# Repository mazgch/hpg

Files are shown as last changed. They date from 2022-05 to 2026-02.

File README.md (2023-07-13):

#  mazg.ch - HPG Solution

>**Note** This is a private project from [@mazgch](https://github.com/mazgch) <br> This code and hardware was developped during my free time. [u-blox](https://www.u-blox.com) decided to launch a simliar, inspired product under the name [XPLR-HPG-2](https://www.u-blox.com/en/product/xplr-hpg-2) along with production grade software based on [ubxlib](https://github.com/u-blox/ubxlib). u-blox has published the [hardware](https://github.com/u-blox/XPLR-HPG-hardware) and [software](https://github.com/u-blox/XPLR-HPG-software) on the [u-blox github account](https://github.com/u-blox). You can easily recognize the u-blox productized version by its green PCB color and u-blox sticker and silk logo on the back of the PCB.<br>
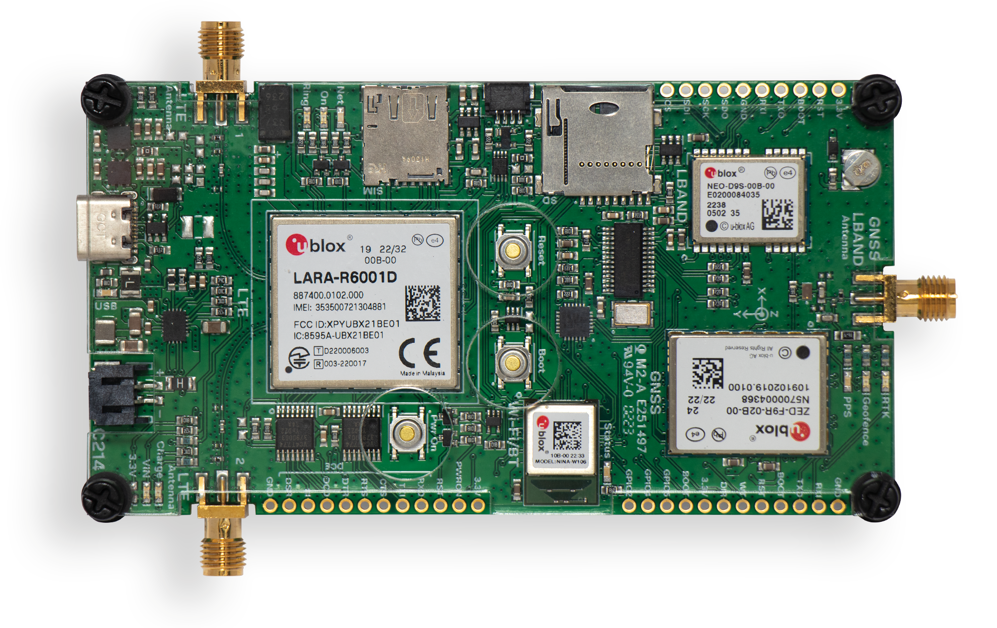
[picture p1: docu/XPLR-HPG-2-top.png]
[](https://www.u-blox.com/en/product/xplr-hpg-2)<br>
The Arduino software of this project can be compiled for the XPLR-HPG-2/1 by adjusting the `HW_TARGET` defines to `UBLOX_XPLR_HPG2_C214` in the [`software\HW.h`](./software/HW.h) file and selecting the right module/board. 

Board with accessories

This project has the goal to demonstrate a high precision positioning function. It uses a Global Navigation Satellite System (GNSS) L1/L2 receiver with Real Time Kinematic (RTK) and Inertial Measurement Unit (IMU) Sensor based Dead Reckoning (DR) function to determine its location. In order achieve its best accuracy the receiver needs a correction data stream. On this solution the correction data can be received from a satellite broadcast using a LBAND receiver or over IP connectivity using Wi-FI or LTE. While other systems typically use local reference stations as correction source that have to be setup a maintained, this system makes use of a continental wide commercial SSR service. The whole solution shared in this project consist of three parts: 

## The three elements of the HPG Solution 

| [**HPG Hardware**](./hardware) | [**HPG Software**](./software) | [**HPG Monitor Webpage**](./monitor) |
|---|---|---|
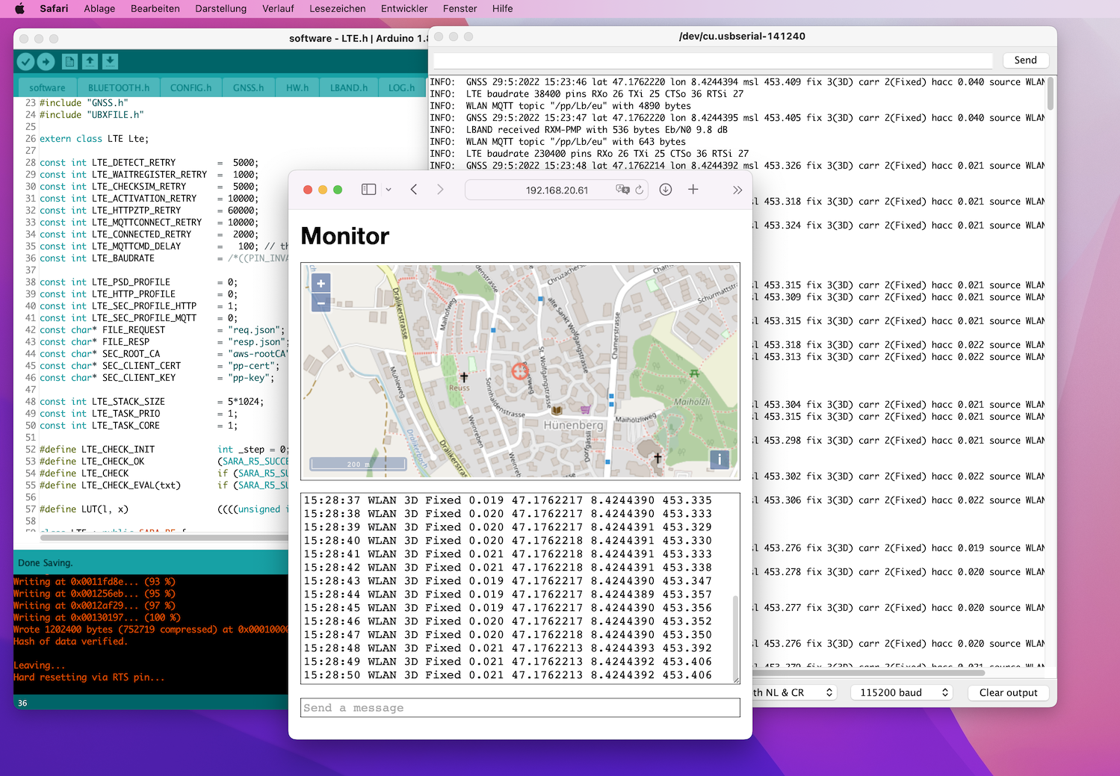
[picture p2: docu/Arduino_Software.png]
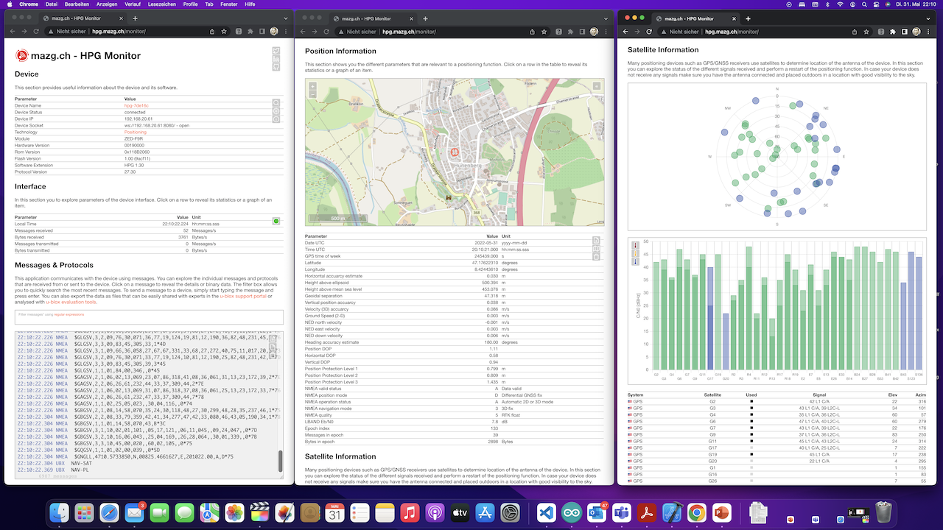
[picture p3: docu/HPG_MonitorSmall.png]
|  |  |  |
| The HPG hardware has a GNSS and a LBAND receiver that are used to achieve cm-Level precision. A Wi-Fi/BT module and a LTE modem make sure that the board is always connected to the internet. A USB port is used for changing or connecting a powerful host. The CPU of the Wi-Fi/BT module can be programmed with the HPG Software. | The HPG software implements a captive portal for configuration and monitoring. The software operates autonomously, configures all the modules and handles the different correction data sources and provides its data to the RTK system. It can also record two logfiles to the SD card of the GNSS/LBAND and the LTE communication. | The online HPG Monitor webpage at [hpg.mazg.ch](http://hpg.mazg.ch) is a online tools that allows you visualize the data of the solution. You can plot graph, export data to Excel or other offline tools. Satellite information as well as a map overlay are even available. The different messages and commands can be analyzed in a console. A simpler version can be accessed in the captive portal directly. |  

## Getting started

To make this device work as intended you need some accessories like LTE and GNSS antennas, a mobile data plan and nano SIM card and a subscription to PointPerfect. Follow this sequence to get the device configured and setup, click on the image below for a short YouTube video on how to do some of these steps.

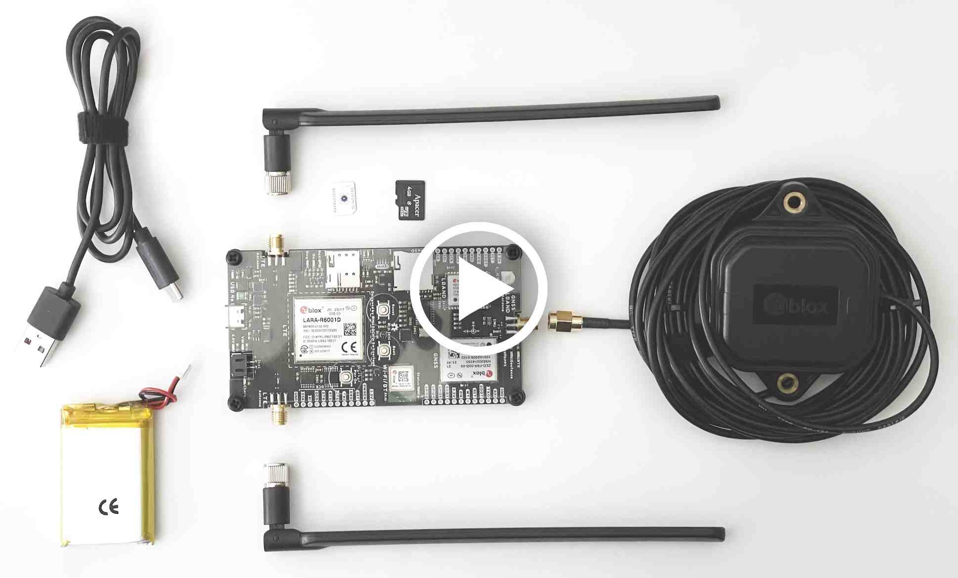
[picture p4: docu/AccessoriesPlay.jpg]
Accessories Video (https://youtu.be/jzHmvw_pzyI)


1. Insert a nano SIM card, the socket is a push/push socket so don't try to just pull the card out.
2. Optional: Insert a micro-SD card (FAT, max 32GB) if you like the device to record logfiles. 
3. Attach the two LTE antennas to the SMA ports located on the long edges. To avoid mechanical stress on the center pin, make sure you do not rotate the antenna itself but only the nut of the SMA connector. 
4. Connect a survey grade L1/L2/L5 GNSS and LBAND antenna to the SMA port on the small edge of the device and place the antenna in a location with very good and unobstructed visibility to the sky. This is important to allow reliable LBAND reception as well as avoid multipath errors on the GNSS measurements 
5. Connect a USB cable to a computer, this will turn the device on, and you will see various LEDS turn on. In addition, your computer will enumerate several USB devices and serial as well a modem ports will become available.  

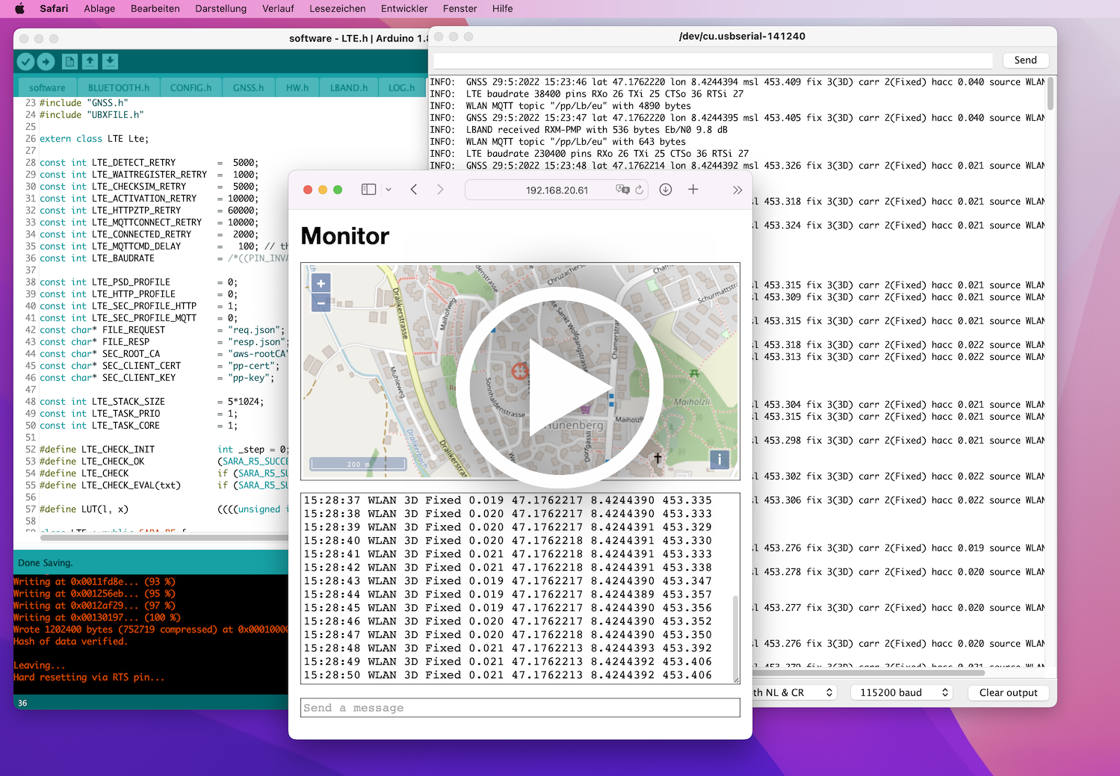
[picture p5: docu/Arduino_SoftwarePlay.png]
Software Getting Started Video (https://youtu.be/k2dovptFn9o)


6. Optional: if the [software](./software) is not yet programmed, follow the build instructions of the Arduino based software and load it to the device. 
7. In order to add the device to your local Wi-Fi connect your computer or mobile phone with the `hpg-XXXXXX` Wi-Fi network. You will be directed to a captive portal where you can then enter your networks Wi-Fi credentials. Make sure that the Wi-Fi network that you like to connect to is supporting 2.4GHz band. Once done the device will connect to your local network and get an IP. You may want to reset your device to force a fast reconnection.
8. After the device is connected, you can try to connect to it using its host name `hpg-XXXXXX`. The IP address of the device is also reported in the debug output on the console output CDC port at 115'200 baud. A third option is to use the device discovery of the [HPG Monitor](http://hpg.mazg.ch). Some networks do not allow communication between attached Wi-Fi clients so it may be better to connect the device to your computer or mobile in hotspot mode. 
9. After you have successfully connected your device, you need to configure the PointPerfect location device token that you can get from the Thingstream portal and set the possible correction sources to use. If you do not have a device profile, create one with following settings: ``Status = enabled, Auto Activate Devices = true, Hardware Code = mandatory`` Return existing device details if Hardware Code is in use. You can also set the SIM pin, but it is often easier to remove the SIM pin from your SIM card with a mobile phone first. Alternatively you can provide the ``u-centerConfig.json`` to the device.  
10. After that the device will provision the credentials using zero touch provisioning (ZTP) from the PointPerfect servers.
11. Now you are ready to Monitor the operation of the device using the console output on the CDC, using the Monitor webpage that is served directly by the device.

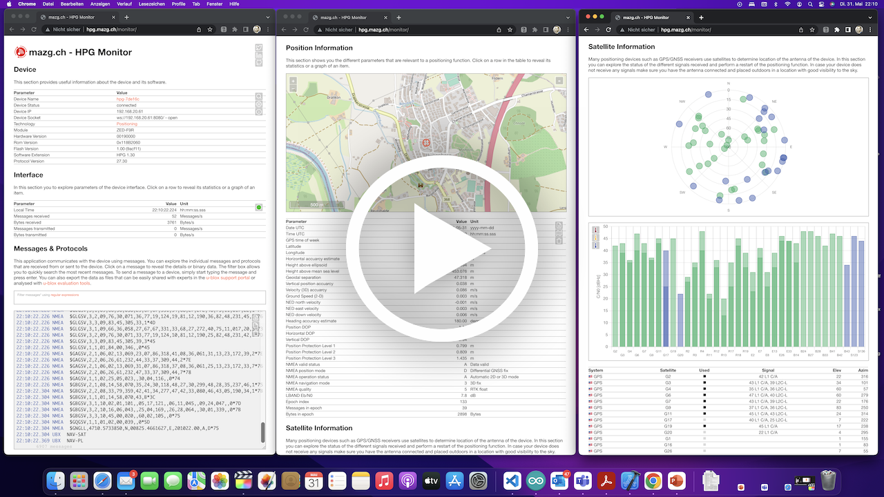
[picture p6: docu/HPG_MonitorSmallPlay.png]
HPG Monitor Getting Started Video (https://youtu.be/LLKUxa8krcs)

  
11. You can also access and find your hpg devices using the HPG Monitor webpage at [hpg.mazg.ch](http://hpa.mazg.ch) This webpage displays various status information, messages and can even plot graphs of parameter or satellite signal strenghs. A map overlay completes the functionality of the HPG Monitor. You can even export your data a text, in common file formats for offline tools.
12. You are now ready to start experimenting with this exciting technology and go outside and test RTK positioning in your use cases. The solution is suitable for a variety of applications from Lawn Mower, Heavy machine and Construction vehicles, Drones, Precision Agriculture, Cars and of course Mobile Robotics. 
13. To get best performance sure that the GNSS/LBAND antenna is well positioned and has good visibility to the sky!
14. So have fun and put this solution on your robot, [vehicle](docu/Vehicle.md), [scooter](docu/Scooter.md) or [lawn mower](docu/Mower.md) project. Feel free to connect with me even if it’s just to share the projects you are building using this exciting technology and solution.

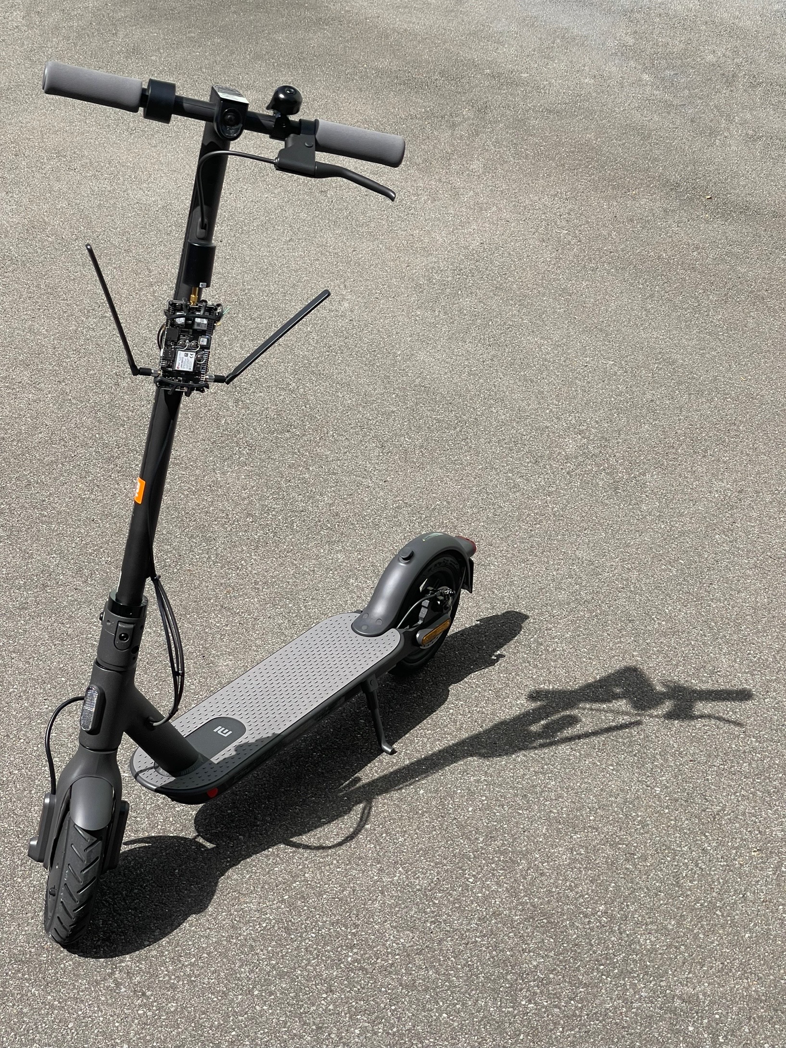
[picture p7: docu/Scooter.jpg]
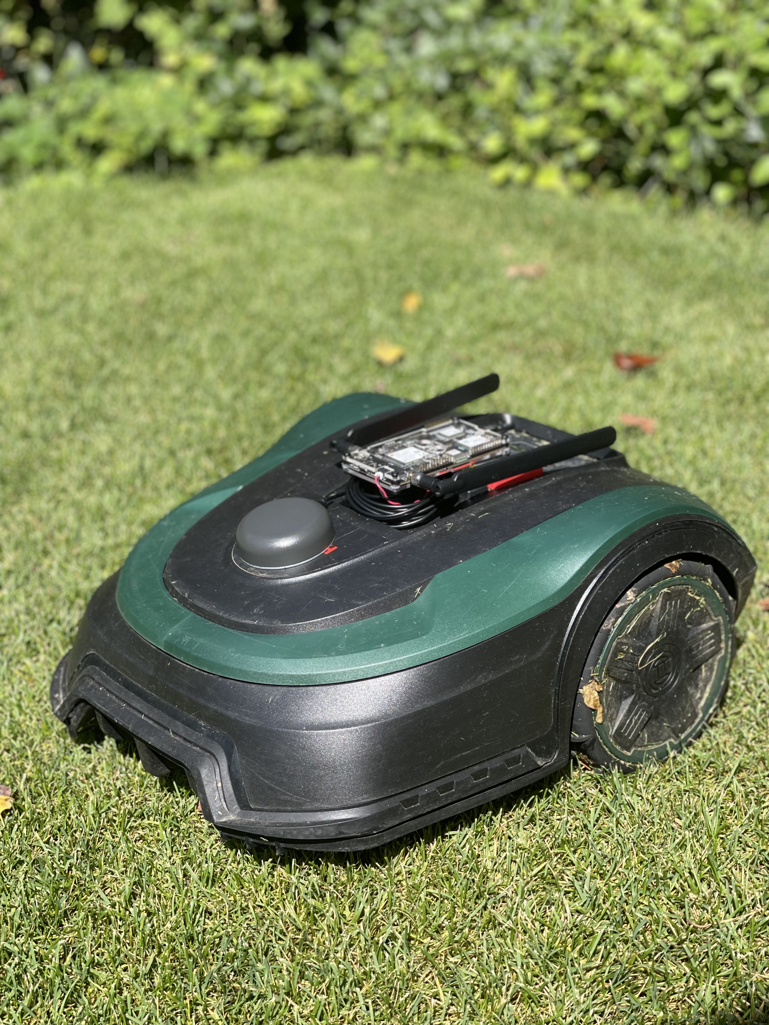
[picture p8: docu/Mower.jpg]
  

## Quick Reference Card

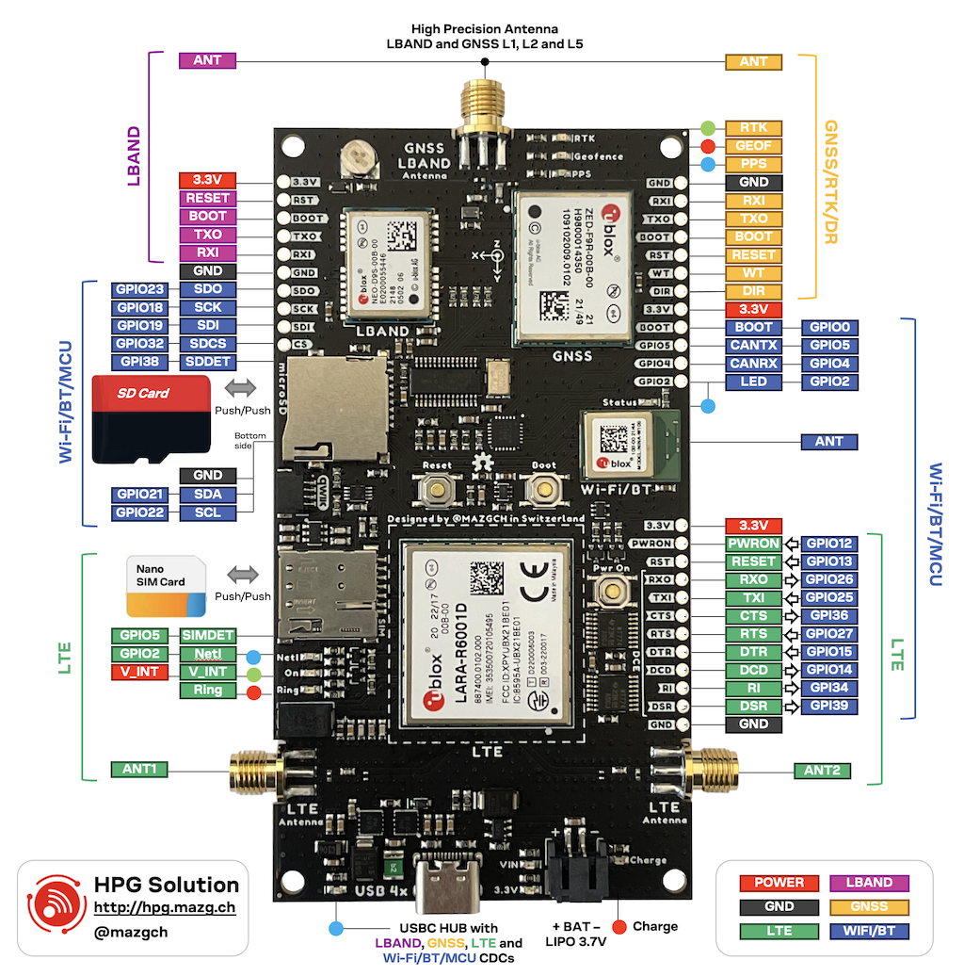
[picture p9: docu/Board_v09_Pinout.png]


## An all [u-blox](https://www.u-blox.com) solution

This solution is an attempt to design a 'full u-blox solution' using various products In particular the solution implements following hardware and services:

| u-blox Product / Service | Description |
|:---:|---|
| [NINA-W106](https://www.u-blox.com/en/product/nina-w10-series-open-cpu) | An ESP32 based WIFI and BT module with Open CPU that will host the application. | 
| [LARA-R6001D](https://www.u-blox.com/en/product/lara-r6-series) | A LTE Cat 1 cellular modem with 2G / 3G fallback. |
| [ZED-F9R](https://www.u-blox.com/en/product/zed-f9r-module) | A GNSS Module with RTK, DR and L1/L2 multiband capability. |
| [NEO-D9S](https://www.u-blox.com/en/product/neo-d9s-series) | A LBAND receiver to get PointPerfect correction service. | 
| [ANN-MB](https://www.u-blox.com/en/product/ann-mb-series) | L1/L2 multi-band, high precision GNSS antenna (LBAND is not offically supported, it may work but there is a slight degradation depending on the frequency) | 
| [PointPerfect](https://www.u-blox.com/en/product/pointperfect) | A continental wide SSR correction service with coverage in Europe and North America. |
| [AssistNow](https://www.u-blox.com/en/product/assistnow) | A assisted GNSS services that allows to speed up the system start. |

The hardware allows different SKUs and can be assembled with alternative modules with compatible form-factors such as [SARA-R510S](https://www.u-blox.com/en/product/sara-r5-series), [LENA-R8001](https://www.u-blox.com/en/product/lena-r8-series), [ZED-F9P](https://www.u-blox.com/en/product/zed-f9p-module) or [NEO-D9C](https://www.u-blox.com/en/product/neo-d9c-series).

## Availability

As this is a private project, availability of real prototypes and hardware is pretty much limited to friends and colleagues. I am sharing here my work with the open source community with the goal that others can learn from it and collaborate. If you like to have a discussion or business interesst you can contact me with a DM.

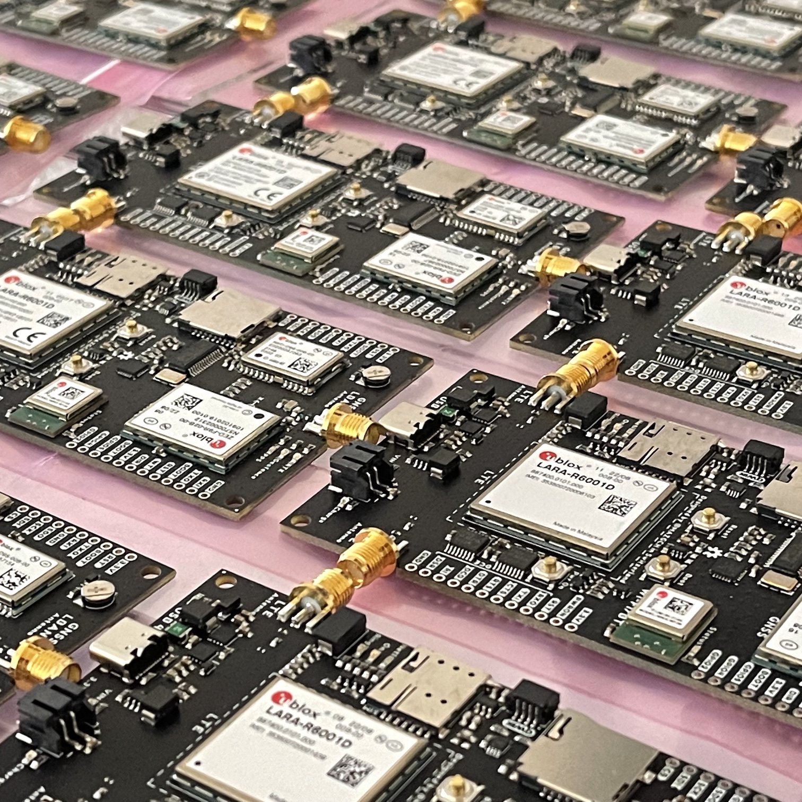
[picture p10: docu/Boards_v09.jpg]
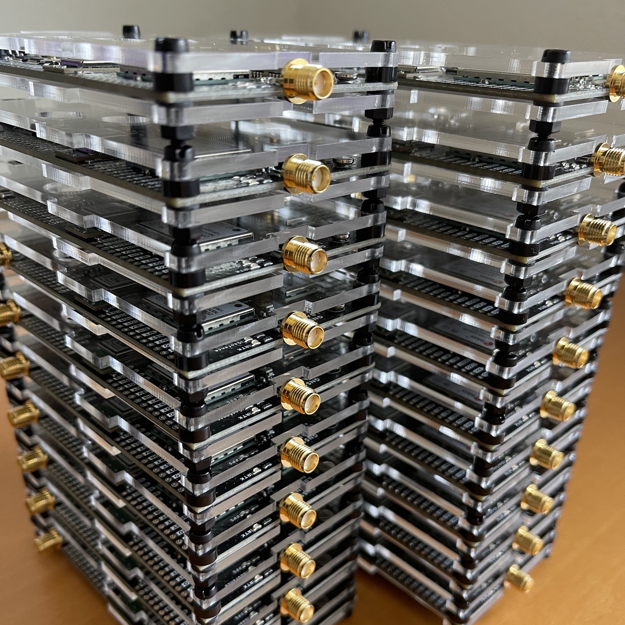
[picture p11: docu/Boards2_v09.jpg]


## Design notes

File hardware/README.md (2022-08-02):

# Hardware



This hardware was designed with Autodesk Eagle and is hugely based on Sparkfun open-source designs. The PCB is a standard four-layer PCB 1.6mm with quite conservative design rules and components, passives are mostly 0603. The core of the circuit is centered around various u-blox modules. The design's default assembly option are the following modules.

| u-blox Module | Function |
|:---|:---|
| [NINA-W106](https://www.u-blox.com/en/product/nina-w10-series-open-cpu) | An ESP32 based WIFI and BT module with Open CPU that will host the application. | 
| [LARA-R6001D](https://www.u-blox.com/en/product/lara-r6-series) | A LTE Cat 1 cellular modem with 2G / 3G fallback. |
| [ZED-F9R](https://www.u-blox.com/en/product/zed-f9r-module) | A GNSS Module with RTK, DR and L1/L2 multiband capability. |
| [NEO-D9S](https://www.u-blox.com/en/product/neo-d9s-series) | A LBAND receiver to get PointPerfect correction service. | 

## Design Resources 

Here you can find the schematic, layout and pictures of both sides of the PCB.
- [**PCB Schematic**](./HPG_Solution_sch.pdf)
- [**PCB Layout**](./HPG_Solution_brd.pdf)
- [**Autodesk Eagle Files**](./hardware/Eagle/)
- [**Gerber Files and Assembly Data**](./hardware/CAMOutputs)

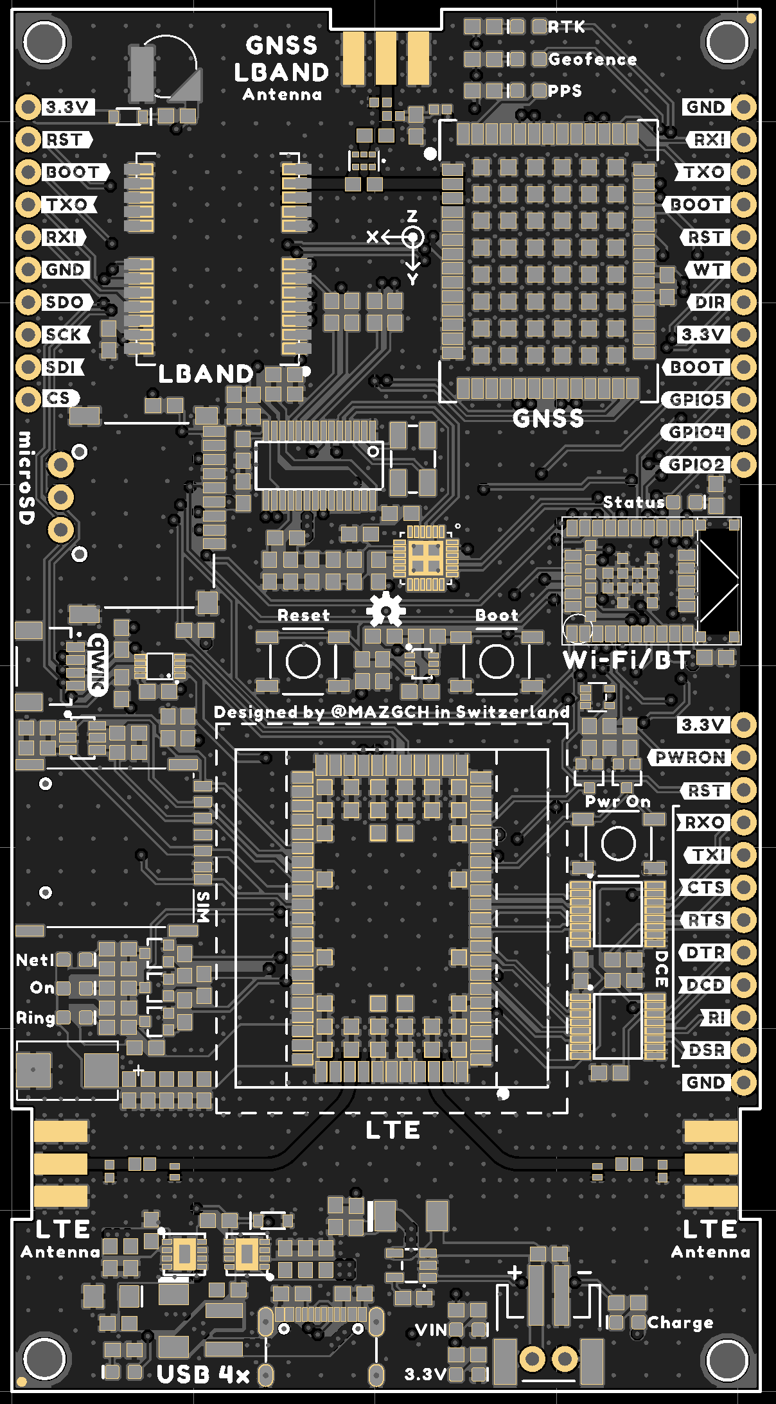
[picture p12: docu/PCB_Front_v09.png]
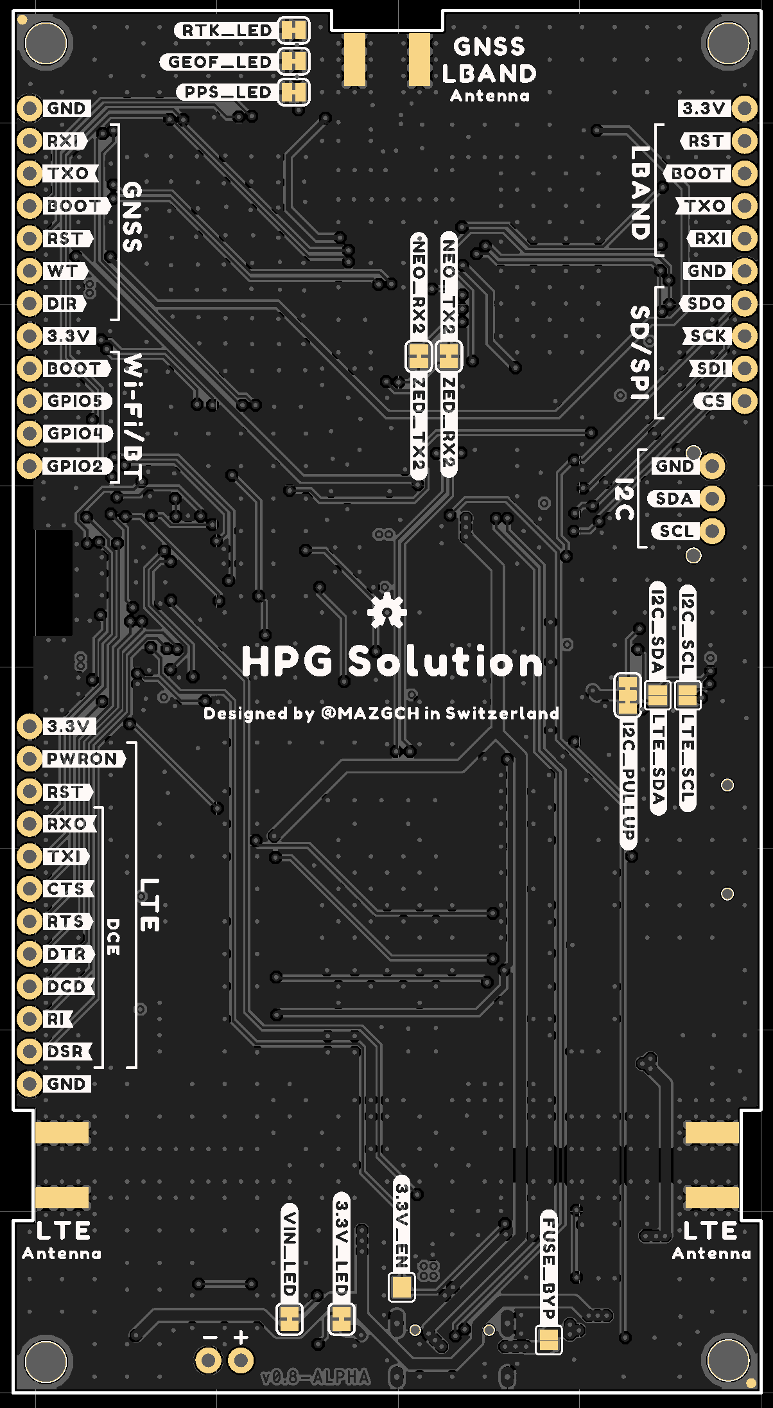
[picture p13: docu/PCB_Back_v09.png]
&nbsp;

## LTE Modem 
There board was designed for u-blox [LARA-R6001D](https://www.u-blox.com/en/product/lara-r6-series) LTE modem, but it allows SKUs by swapping the cellular module to a  [SARA-R510](https://www.u-blox.com/en/product/sara-r5-series) for LTE Cat M1 NB-IoT or a [LENA-R8001](https://www.u-blox.com/en/product/lena-R8-series) Cat 1 bis. Several different modem variants are available from u-blox, only some BOM adjustments might be needed to make different SKUs of this function board. The board requires two external LTE antennas with SMA connectors (only one antenna would be used for [LENA-R8001](https://www.u-blox.com/en/product/lena-R8-series), [SARA-R510](https://www.u-blox.com/en/product/sara-r5-series). The LTE modem uses DCE notation and signal are connected straight to the NINA CPU (no null modem, crossover). The LTE_PWR_ON pin is also connected to a button to allow manual turning on of the LTE modem. The LTE_RESET pin unfortunately does not have a pull up resistor, this could be considered as a mistake, but it can be set by the NINA CPU after software is loaded. If this is not done, then the module will turn off after it booted  

| u-blox Series | LTE Standard | # Antenna |
|:---|:---|:---:|
| [LARA-R6](https://www.u-blox.com/en/product/lara-r6-series) | LTE Cat 1 with 2G / 3G fallback | 2 |
| [LENA-R8](https://www.u-blox.com/en/product/lena-R8-series) | LTE Cat 1bis with 2G / 3G fallback | 1 |
| [SARA-R5](https://www.u-blox.com/en/product/sara-r5-series) | LTE Cat M1 / NB-IoT | 1 |
| [SARA-R4](https://www.u-blox.com/en/product/sara-r4-series) | LTE Cat M1 / NB-IoT with 2G fallback | 1 |

## High Precision GNSS and LBAND Receivers
The board was designed for u-blox **ZED-F9R** high precision GNSS RTK and DR module and a **NEO-D9S**, but it allows SKUs by swapping the modules to different variants such a **ZED-F9P** or the **NEO-D9C** that supports Japan's CLAS system. The board requires an external L1/L2/L5 and LBAND antenna with SMA connectors.

## Wi-Fi/BT with open CPU capability. 

NINA-W106-01 is a ESP32 with 8MB of FLASH memory. This module is responsible to run the software of the whole design. It can be easily programmed using different environments. The RESET and BOOT pins can be controlled with buttons and as well though a special Auto Reset circuit.

### NINA-W106 Pin Assignments

| GPIO  | Signal Function | DIR | Comment |
|:-----:|:---|:---:|:---|
| 0 | BOOT / GPIO0 | IN  | <- BOOT button, USB CDC RTS/CTS |
| 1 | CDC_TX | OUT | -> USB CDC RX |
| 2 | LED / GPIO2 | OUT | -> LED |
| 3 | CDC_RX | IN  | -> USB CDC TX |
| 4 | GPIO4 / CAN_RX | I/O | <- CAN (external) |
| 5 | GPIO5 / CAN_TX | I/O | -> CAN (external) |
|  12 | LTE_PWR_ON | OUT | active HIGH, **no pull up!** |
|  13 | LTE_RESET | OUT | active LOW, ext pulled LOW |
|  14 | LTE_DCD | OUT | -> LTE. |
|  15 | LTE_DTR | OUT | -> LTE |
|  18 | MICROSD_SCK / SCK | OUT | -> SD card |
|  19 | MICROSD_SDI / COPI / MOSI | OUT | -> SD card |
|  23 | MICROSD_SDO / CIPO / MISO | IN  | <- SD card |
|  21 | I2C_SDA | I/O | <-> GNSS, LBAND, LTE, QWIC |
|  22 | I2C_SCL | OUT | -> GNSS, LBAND, LTE, QWIC |
|  25 | LTE_TXI | OUT | -> LTE |
|  26 | LTE_RXO | IN  | -> LTE |
|  27 | LTE_RTS | OUT | -> LTE |
|  32 | MICROSD_CS | OUT | -> SD |
|  33 | VCC_EN | OUT | -> power supply |
|  34 | LTE_RI | IN  | <- LTE |
|  35 | VIN/3 | IN  | <- power supply |
|  36 | LTE_CTS | IN  | <- LTE |
|  37 | LTE_ON | IN  | <- LTE |
|  38 | MICROSD_DET | IN  | <- SD card holder |
|  39 | LTE_DSR | IN  | <- LTE |
| RESET | RESET | IN  | <- RESET button, USB CTS RTS/CTS |

## Power Supply
The board has two 1A LDOs, one for the LTE modem and a second for all other functions. The status of the Power supply can be monitored using the different LEDs across the board. A changer is provided to support charging of a single 3.7V LIPO cell. A special LED will indicate the charging status. The **3.3V pins on the pin headers are output only** and can be used to power an external sensor or device like a CAN transceiver. 

## Other Functions

- **USB** The USB-C port provides as interface to an external host and is used for supplying the board. 
- **CAN** The GPIO4 and GPIO5 of the NINA-W106 can be used to connect a CAN transceiver such as a SN65HVD230. Thre a simple breakout board that you can attach using jumper wires such as the [CJMCU-230](https://de.aliexpress.com/item/32278648363.html)
- **BAT** A 3.7V single LIPO cell can be connected and will be charged when USB is connected. 
- **QWIK** The QWIK connector can be used to connect other I2C devices such as sensors or a display. 

## External Accessories

External antennas have to be connected to operate the device. The combined GNSS and LBAND antenna should support at least L1, L2 and LBAND frequency bands and it can support L5 band in addition. The antenna should be an antennna that is high precision capable, typically these are Helix type of antennas or active patch antennas with dual feed and reasonably sized GND planes (>10cm). If the antenna does not come with a ground plane, place it on a metal surface such as a car roof.
The LTE modem needs to 4G capable antennas and cover the band of the modem usually this is 700kHz - 2.6GHz. In addition you need to insert a SIM card with a data plan from your local mobile network operator.
A micro-SD card is only required if you intend to record logfiles from the modem of GNSS_ 

### Accessory parts and suppliers:
- Plexi were ordered from [Alibaba Shenzhen Elemei Display Products Co., Ltd](https://elemeidisplay.en.alibaba.com/minisiteentrance.html) they offer laser cut custom plexi under part number [OEM and ODM custom laser cut acrylic shapes customized service](https://www.alibaba.com/product-detail/OEM-and-ODM-custom-laser-cut_1600273363981.html) you send them the two PlexiTop and PlexBot layers exported as DXF file.  
- LTE antennas were ordered from [Advanced Aerial Store](https://de.aliexpress.com/store/912726145), you need 2pcs (= one order) of the following product for each board [2pcs/lot 4G Antenna 10dBi SMA Male 700-2700MHz for 4G LTE Router External Antenna](https://de.aliexpress.com/item/1005003688735673.html)
- The screws an nuts were ordered from [LANHAI Fastener Store](https://de.aliexpress.com/store/912262969), for a single board 4pcs are needed from each part. 
  - [M3x15mm / Phillips head screw](https://de.aliexpress.com/item/1005003106000201.html)
  - [hex nut M3](https://de.aliexpress.com/item/1005003106000201.html)
  - [Black / M3 ID3.1mm OD7mm / 3mm](https://de.aliexpress.com/item/1005003106036023.html)
  - [M3x6x1mm / black](https://de.aliexpress.com/item/1005003106227200.html)

## Known Issue of version 0.9: 
- The LTE_PWR_ON is floating towards GND, this causes the modem to constantly reset if no software is loaded. Software needs to be loaded that configures the GPIO12 either output HIGH or as INPUT with PULL-UP enabled. During reset the ESP applies however some LOW and high signal. It would be best to swap the LTE_RESET and LTE_PWRON pins to avoid changes during updates or reset. 
- The C41 was added to the Auto Reset circuit of the NINA-W106. This sometimes can cause issues with certain terminal applications or if the BOOT GPIO is used for other functions. Simply remove the C41 with a soldering iron if it causes issues for you.
- The shield of the SIM card holder is not connected to GND in the symbol. To make SIM detection work, we have to connect it to GND by makeing a solder bridge to GND pads of C38/36. In addition the software needs to set AT+UGPIOC=42,7 and AT+UDCONF=50,1. If SIM detection is not needed and then it is better to maybe remove R50. 
- On the v0.9 build some of the SIMhard holders are not porperly positioned on the board. This results in the component being a bit tilted due to the guidance pins. The parts were not repositioned but simply fixed with just more solder. 
- If special firmware is loaded to ZED-F9 (e.g., dev builds), make sure that RTK_STAT assigned to GPIO11 and GEOFENCE to GPIO12 to use that function.
- Higher baud rates on the LTE are not recommended even if RTS / CTS is used, this is a software issue and unrelated to hardware.
- LENA-R8: prototype require VCC of the module to be higher than 3.5V, this can be fixed by changing the dedicated LTE LDO to a adjustable version with a resistor divider at 3.8V. Also Pin 33 USB_BOOT of LENA should be routed to a jumper that can connect to VINT (V1.8) to allo firmware update over USB.
- Pins could be reassigned, to allow use of JTAG as alternative to the full 8 wire UART (second level shifter would need to be disabled.

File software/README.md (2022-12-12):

# Software



The software ensures full autonomous operation of a high precision solution using cellular or Wi-Fi network for internet connectivity. u-center compatible logging of GNSS data can be stored on SD card. In parallel full evaluation capability should be feasible by giving direct access to the modules through USB to all modules, this interface is also used to update software and firmware of the modules. The application that will runs on the NINA-W106 is be open sourced and serve as an example that can be tailored to different use cases. Ideally the board can be shipped with a software that can be configured using captive portal 

## Features
- Captive and Web portal for configuration of the system and setting Wi-Fi credentials
- Reporting of status on the console using CDC on USB 
- Storing of GNSS UBX and AT commands file to SD card
- Provisioning of PointPerfect credentials using zero touch provisioning (ZTP) by providing device profile token
- Reception of Pointperfect correction data using the MQTT protocol over WIFI an LTE
- Reception of NTRIP corrections using WIFI or LTE (when PointPerfect Correction source set to a `NTRIP:` option)
- Management of different regional correction stream to only ensure one active connection per device. 
- configuration of LBAND frequency and communication settings depending on location and PointPerfect subscription plan. 
- Configuration of the GNSS correction source depending on incoming LBAND or IP data
- Hot plug and runtime detection of gnss, lband and SD card
- Visualisation of the data on a webpage [hpg.mazg.ch](http://hpg.mazg.ch) using websockets 
- Bluetooth connection from a mobile phone using a suitable app (e.g SW Maps on [iOS](https://apps.apple.com/ch/app/sw-maps/id6444248083) or [Android](https://play.google.com/store/apps/details?id=np.com.softwel.swmaps) ). 

## Captive portal
A captive portal is available for configurating the device. Select the Wi-Fi network `hpg-XXXXXX` with a notebook or mobile phone. You can then enter the Wi-Fi network to connect to, configure the Point Perfect device token, stream preferences as well as the LTE related settings. 
The captive protal also will show the client ID when provisioned. 

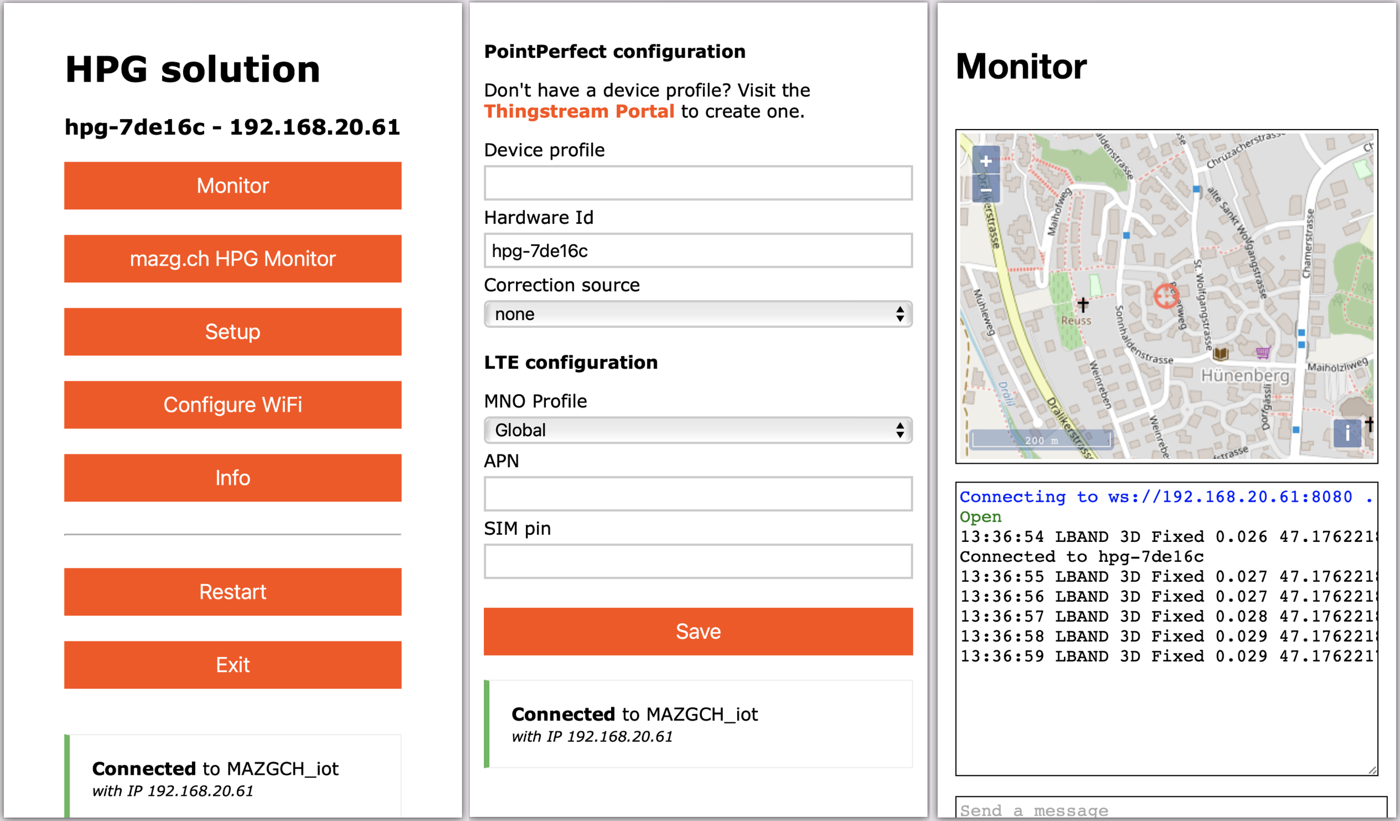
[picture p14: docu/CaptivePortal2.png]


## Host drivers & tools
The USB port exposes each module as serial ports, the LARA is also recognized as a modem. These ports are available for a prowerful host or to connect the various u-blox evaluation tools or a terminal program: 

- [m-Center Cellular Evaluation Tool](https://www.u-blox.com/en/product/m-center)
- [u-center GNSS Evaluation Tool](https://www.u-blox.com/en/product/u-center)

The solution might require installation of drivers these are either available from Microsoft Update or from the u-blox and third party websites.

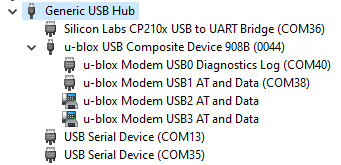
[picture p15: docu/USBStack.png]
Drivers


- [LARA-R6 Drivers](https://content.u-blox.com/sites/default/files/2022-04/ublox_LARA-R6xx_%20windows_3264_v1.0.0.0.exe.zip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)
- [SiLabs CP2101N Drivers](https://www.silabs.com/developers/usb-to-uart-bridge-vcp-drivers)
- ZED-F9 and NEO-D9 works with the standard Windows drivers. [This application note explain details](https://www.u-blox.com/sites/default/files/WindowsDrivers_AppNote_%28UBX-19005821%29.pdf)
- USB Hub works with the standard Windows drivers.

## CDC interface: 
The solution provides a debug console on a CDC USB port. This interface can be used to update this application firmware after compiling it in the Arduino environment. After normal startup it will provide visibility of the activity of the solution. Messages are tagged depending on their severity and software block. (the debug output on the CDC port was recently restructed to use the ESP log APIs an now looks different)

```
INFO:  -------------------------------------------------------------------
INFO:  u-blox HPG solution
INFO:  MAIN task on core 1
INFO:  CONFIG::init FFS ok
INFO:  CONFIG::init "FFS/config.ffs" read
INFO:  UBXSD task on core 1
INFO:  UBXSD card state changed 1 (removed)
INFO:  LBAND detect receiver detected
INFO:  LBAND detect configuration complete, receiver online
INFO:  GNSS detect receiver detected
INFO:  GNSS detect injecting saved key 60 bytes
INFO:  GNSS detect configuration complete, receiver online
INFO:  LED task on core 1
INFO:  WLAN task on core 0
INFO:  LTE task on core 1
INFO:  WLAN init autoconnect using wifi/hostname "u-blox-hpg-7d6de378"
INFO:  LBAND received RXM-PMP EB/N0 37 with 528 bytes
INFO:  GNSS spartanUseSource 1-PMP from source LBAND
INFO:  LBAND received RXM-PMP EB/N0 37 with 528 bytes
INFO:  GNSS 30:4:2022 19:21:08 lat 47.1762495 lon 8.4243838 msl 453.130 fix 3(3D) carr 2(Fixed) hacc 0.025 heap 121188
INFO:  WIFI state change 1(searching)
INFO:  WLAN poll got connection
INFO:  WLAN poll connected with hostname "u-blox-hpg-7d6de378" at IP 192.168.20.57 RSSI -51 dBm
INFO:  WLAN poll visit portal at "http://192.168.20.57/"
INFO:  WLAN bindCallback webserver started
INFO:  WIFI state change 3(provisioned)
INFO:  GNSS 30:4:2022 19:21:09 lat 47.1762495 lon 8.4243838 msl 453.139 fix 3(3D) carr 2(Fixed) hacc 0.026 heap 61696
INFO:  LTE config manufacturer "u-blox" model="LARA-R6401D" version="00.11"
INFO:  LTE state change 1(check sim)
INFO:  LTE SIM card status "READY" CCID="89410112191214532555"
INFO:  LBAND received RXM-PMP EB/N0 35 with 528 bytes
INFO:  LTE IMEI="359352450003076" IMSI="228012122453255" subscriber=""+41799613242"
INFO:  LTE state change 2(sim ready)
INFO:  LTE state change 3(wait register)
INFO:  GNSS 30:4:2022 19:21:10 lat 47.1762496 lon 8.4243839 msl 453.133 fix 3(3D) carr 2(Fixed) hacc 0.027 heap 59320
INFO:  GNSS 30:4:2022 19:21:11 lat 47.1762496 lon 8.4243839 msl 453.135 fix 3(3D) carr 2(Fixed) hacc 0.027 heap 52384
INFO:  LBAND received RXM-PMP EB/N0 39 with 528 bytes
INFO:  GNSS 30:4:2022 19:21:12 lat 47.1762495 lon 8.4243837 msl 453.141 fix 3(3D) carr 2(Fixed) hacc 0.022 heap 67196
INFO:  WLAN MQTT connect to "pp.services.u-blox.com":8883 as client "c07eae12-a01d-4f23-8b8f-dd67a753f3b7"
INFO:  WIFI state change 4(connected)
INFO:  WLAN MQTT subscribe "/pp/ubx/mga"
INFO:  WLAN MQTT subscribe "/pp/ubx/0236/Lb"
INFO:  LBAND received RXM-PMP EB/N0 39 with 528 bytes
INFO:  WLAN MQTT "/pp/ubx/mga" received 8184 wrote 8184 of total 8184 bytes
INFO:  WLAN MQTT "/pp/ubx/0236/Lb" received 60 wrote 60 of total 60 bytes
INFO:  WLAN MQTT subscribe "/pp/Lb/eu"
INFO:  GNSS 30:4:2022 19:21:13 lat 47.1762496 lon 8.4243838 msl 453.130 fix 3(3D) carr 2(Fixed) hacc 0.022 heap 69976
INFO:  GNSS spartanUseSource 0-SPARTAN from source WLAN
INFO:  WLAN MQTT "/pp/Lb/eu" received 232 wrote 232 of total 232 bytes
INFO:  GNSS 30:4:2022 19:21:14 lat 47.1762496 lon 8.4243838 msl 453.129 fix 3(3D) carr 2(Fixed) hacc 0.022 heap 71756
INFO:  WLAN MQTT "/pp/Lb/eu" received 4690 wrote 4690 of total 4690 bytes
INFO:  WLAN MQTT "/pp/Lb/eu" received 572 wrote 572 of total 572 bytes
INFO:  LBAND received RXM-PMP EB/N0 38 with 528 bytes
INFO:  GNSS 30:4:2022 19:21:15 lat 47.1762496 lon 8.4243838 msl 453.131 fix 3(3D) carr 2(Fixed) hacc 0.023 heap 71756
INFO:  GNSS 30:4:2022 19:21:16 lat 47.1762494 lon 8.4243831 msl 453.149 fix 3(3D) carr 2(Fixed) hacc 0.021 heap 71756
INFO:  LBAND received RXM-PMP EB/N0 40 with 528 bytes
INFO:  GNSS 30:4:2022 19:21:17 lat 47.1762495 lon 8.4243833 msl 453.139 fix 3(3D) carr 2(Fixed) hacc 0.021 heap 71756
INFO:  LBAND received RXM-PMP EB/N0 39 with 528 bytes
INFO:  GNSS 30:4:2022 19:21:18 lat 47.1762495 lon 8.4243833 msl 453.145 fix 3(3D) carr 2(Fixed) hacc 0.021 heap 71756
INFO:  WLAN MQTT "/pp/Lb/eu" received 136 wrote 136 of total 136 bytes
INFO:  GNSS 30:4:2022 19:21:19 lat 47.1762495 lon 8.4243833 msl 453.152 fix 3(3D) carr 2(Fixed) hacc 0.022 heap 71756
```

## Known Issues
- Rarely the software crashes and the webserver maybe not so responsive (about 10s) as it is not asynchronous. It seems this is caused by low memoryand was improved by optimizing usage and now is more stable. **imroved**
- When connecting the board to a windows hotspot, then it seems that the network stack of the laptop gets confused. It is unclear why this happens maybe the dhcp or other service of the captive portal causes these issues. Better use a hotspot or ihone mobile hotspot mode.
- Since the latest arduino_esp32 SDK it seems that parallel wifi and SD is causing issues. start_ssl_client fails during MQTT connect, maybe some dependency on the use of the file system of available heap. **solved**
- 2.0.4 had a issue with partition maps when 2MB is selected, workarount is to use 4MB or stay with 2.0.3 **solved**

## Build instructions
This software uses the free **Arduino IDE** that you can download from [their website](https://www.arduino.cc/en/software). It is recommended to use the installer (not the windows store App) as there have been on some PCs issues with running the compiler. The board uses a ESP32 based module, the NINA-W106 or Sparkfuns ESP32 Micromod. In order to compile the software for this target you need to install the [**arduino-esp32**](https://github.com/espressif/arduino-esp32) board support package. The [install instructions](https://docs.espressif.com/projects/arduino-esp32/en/latest/installing.html) will guide you through that process. At the time of writing these instructions, it is recommended to use the current development release of the package as some critical fixes that this software relies on were just recently contributed to this package. Then go to the board manager and install the esp32 package. When done you may need to restart to select and configure the Arduino IDE to use the correct device, please select **u-blox NINA-W10 series** and make sure the various settings are like in following screenshot: 

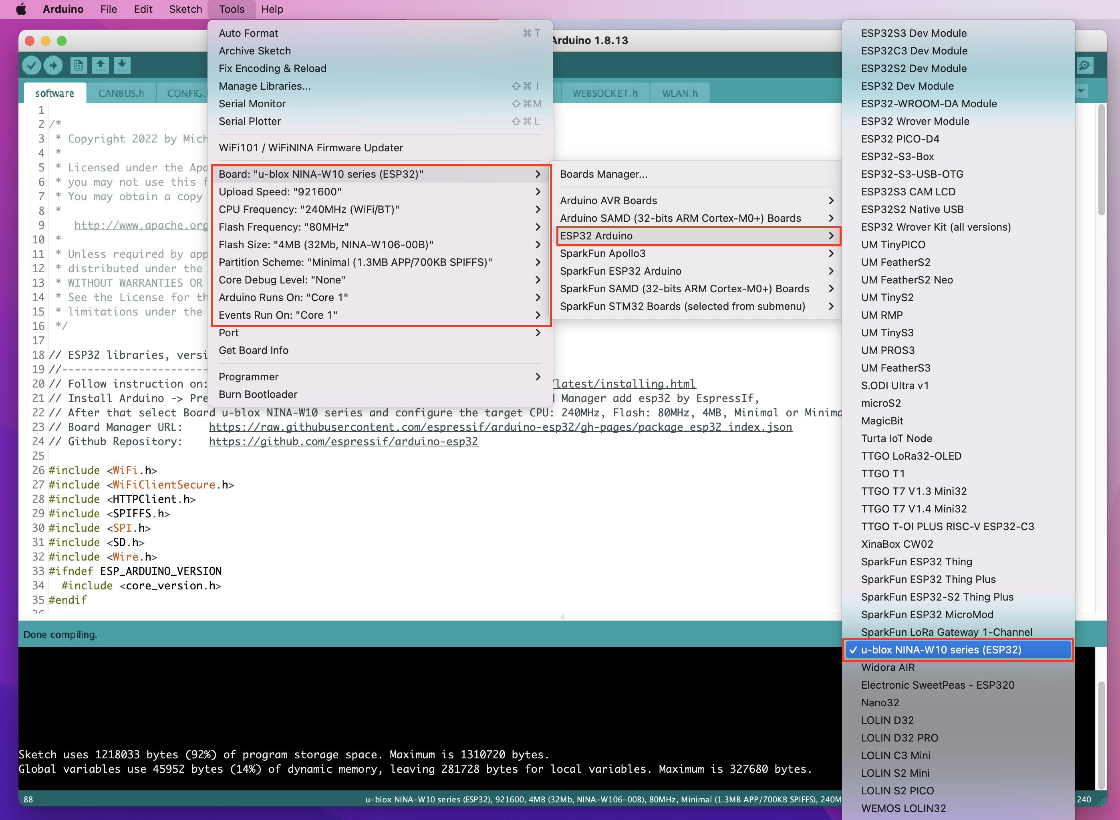
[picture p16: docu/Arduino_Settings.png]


The software makes use of several proprietary libraries and packages, all the packages can be downloaded using the library manager (recommended) or manually downloaded installed using GitHub, for this project some fixes and features were contributed to the following libraries so please makes sure you have the latest beta or even development version. You will find library manager links also in the software.ino file just click them all and install the needed package, some links give you multiple option please select carefully the right package: 
- [arduino-esp32](https://github.com/espressif/arduino-esp32) used for NINA-W1 target and SD, FS, Wifi, SPI and many other functions provided by the ESP chip
- [ArduinoMqttClient](https://github.com/arduino-libraries/ArduinoMqttClient) for communicating with PointPerfect MQTT broker 
- [ArduinoJson](https://github.com/bblanchon/ArduinoJson) Json for storing configurations and parsing ZTP messages  
- [WiFiManager](https://github.com/tzapu/WiFiManager) Captive and configuration portal
- [ArduinoWebsockets](https://github.com/gilmaimon/ArduinoWebsockets) in future we may communicate with a website using web sockets
- [SparkFun_u-blox_GNSS_Arduino_Library](https://github.com/sparkfun/SparkFun_u-blox_GNSS_Arduino_Library) can be used for ZED-F9 or NEO-D9 communication using UBX or NMEA
- [SparkFun_u-blox_SARA-R5_Arduino_Library](https://github.com/sparkfun/SparkFun_u-blox_SARA-R5_Arduino_Library) can be used to communicate using AT commands with SARA or LARA LTE modems

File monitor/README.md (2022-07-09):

# HPG Monitor



This webpage is used in the HPG-Solution project. Its main capability is to search for devices in local network, visualize the data from the GNSS receiver and perform configurations, actions or export data. 
the page is accessible at [http://hpg.mazg.ch](http://hpg.mazg.ch)

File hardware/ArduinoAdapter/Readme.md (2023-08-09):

# Arduino Adapter Board

This is an adapter for replacing the ArduSimple board in the [Open Mower project](https://github.com/ClemensElflein/OpenMower) by [Clemens Elflein](https://github.com/ClemensElflein/OpenMower/commits?author=ClemensElflein) with this project or a XPLR-HPG-2.

**Remarks**
- The Yellow marked pin headers are mounted on bottom side to provide connection to the Open Mower board.
- The Purple marked pin headers are mounted on top side and connect to the HPG board.
- All other pin header signals are not connected, but can be mounted for mechanical stability. 
- When powering the board in this way do not connect a battery as this is used to inject supply from the Open mower board. 

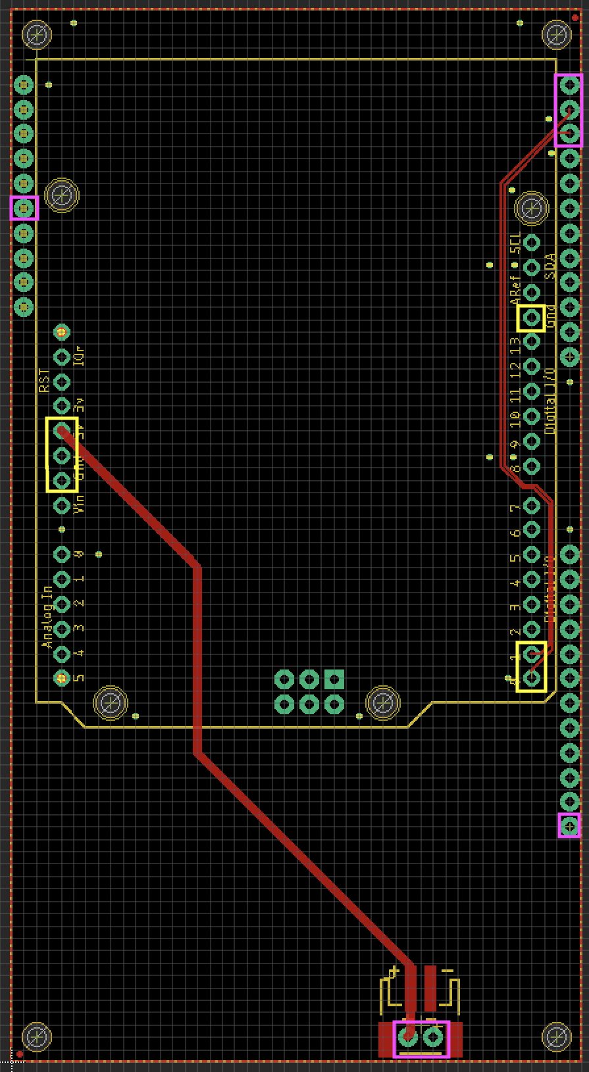
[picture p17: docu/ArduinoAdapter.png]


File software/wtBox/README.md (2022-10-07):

# Hall sensor wheel tick to ESF-MEAS conversion box.

This small project converts the 6 Hall sensor signals from two motors (e.g from a small robot) to a ``UBX-ESF-MEAS`` mesage that can be directly injected into the UART port (``ZED-RXI``) of the HPG solution board. You can probably use any Arduino that has 7 spare GPIOs and at least one UART. Any u-blox Arduino compatible modules like NINA-B10x, ANNA-B10x, NINA-W10x or NORA.W10x will probably work well.

Each motor has three hall sensors that represent 6 states, if the state is increading it means it is moving forward, if decreasing it means it moved backwards. For vehicles with two independent wwheels one of the motor might be reversed as it is mounted in 180 degrees compared to the other one. . 
```
State:  -000-111-222-333-444-555-000-111-222-333-444-555-000-111-222-333-444-555-
        |   .   .   .   .   .   |   .   .   .   .   .   |   .   .   .   .   .   | 
Hall C: ________/-----------\___________/-----------\___________/-----------\____
        |   .   .   .   .   .   |   .   .   .   .   .   |   .   .   .   .   .   |  
Hall B: ----\___________/-----------\___________/-----------\___________/--------
        |   .   .   .   .   .   |   .   .   .   .   .   |   .   .   .   .   .   | 
Hall A: ------------\___________/-----------\___________/-----------\___________/
        |   .   .   .   .   .   |   .   .   .   .   .   |   .   .   .   .   .   | 
``` 

The following picture shows how the board is connected to the wires, at the time of this photo the non default ``D8`` was used for ``D4 TX1 -> ESF-MEAS -> ZED RXI``, this was later changed to the default ``D4 TX1`` location which links with the status LED. I used a WEMOS D1 mini that was just lying around in my drawer. and connected all signals with 1k Ohm resoistors to have them a bit decoupled. 

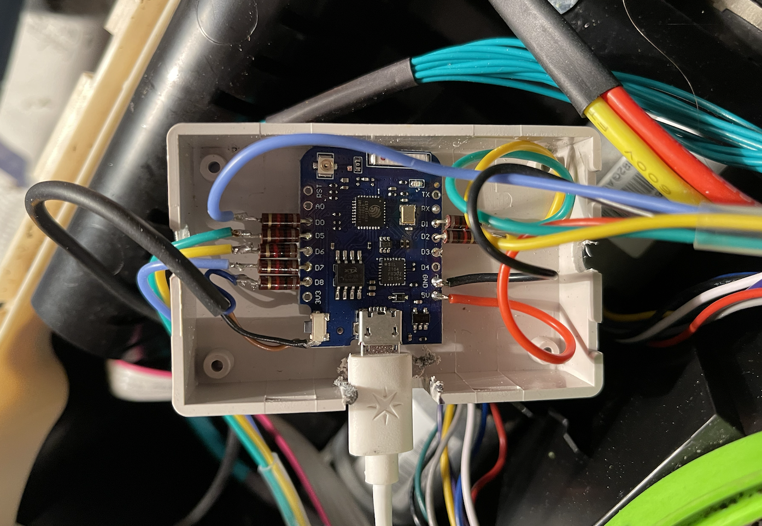
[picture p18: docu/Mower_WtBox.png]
Mower conversion box


Here is the default pin assignement of the WT conversion code when running on the board I used. 

```
                          --- ANTENNA ---
                          |        LED  |
                          RST          TX -> CDC @ 115200
                          ADC0         RX 
      BLUE / HALL_RL_A -> D0,WAKE      D1 <- HALL_RL_B / YELLOW 
     GREEN / HALL_RR_C -> D5           D2 <- HALL_RL_C / GREEN
    YELLOW / HALL_RR_B -> D6   CHIPS   D3
      BLUE / HALL_RR_A -> D7   LED,TXI,D4 -> ESF-MEAS @ 38400 -> ZED RXI
                          D8          GND
                          3v3          5V <- IN
                          ---------------
                                USB
```

Please check the [Mower](../../docu/Mower.md) documentation for an example use of this conversion box.

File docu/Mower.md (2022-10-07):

# Lawn Mower & Slow Moving Robots

The HPG solution can be easily fitted to a lawn mower or slow moving robot to test the performance. 

Bosch lawn mower

The lawn mowers from BOSCH can be easily modified to extract the Hall sensor signals that are used as a distance sensor by the ZED-F9R WT input. First you need to open the mower. Remove the green and black cover by releasing the 6 plastic latches from the bottom side. Release the 8 screws, 6 are easily accessible and two are hidden under the black button with an arrow on it, just next to the red stop botton. Now the black cover can be removed. The Hall sensors signals can be tapped in on the Green, Purple and Gray wires on the two motor connectors. In addition Red is 5V and Black is ``GND``. The signal from the hall sensor is 3.3V and can directly be used. The three thicker wires are to drive phase wires to the motor, these are high current !. 

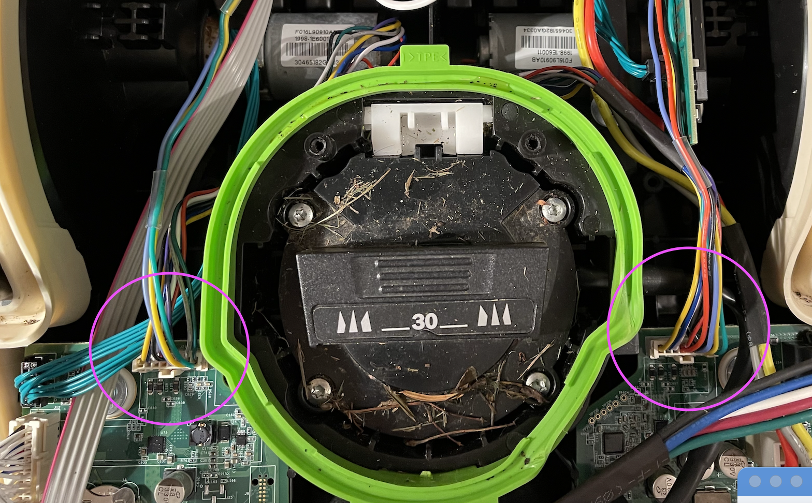
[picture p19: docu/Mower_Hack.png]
Bosch lawn mower


To convert the Hall sensors signals to a ``UBX-ESF-MEAS`` a small Arduino MCU with at least 7 GPIOs is used. This code could be integrated with the main project but we don't have enough spare GPIOs on the hpg board and maybe it also better to avoid large delays in processing and sampling the Hall signals. For details about standalone software project go to [wtBox](../software/wtBox/). I used 1kOhm resistors to connect the wtBox to the Hall sensor wires of the mower, and also for the connection to the HPG board ``ZED RXI`` pin and ``GND`` pins. This reduces the risk for accidential issues in case one of the boards is missbehaving or off. The following picture shows how the board is connected to the wires, at the time of this photo the non defualt ``D8`` was used for ``D4 TX1 -> ESF-MEAS -> ZED RXI``, this was later changed to the default ``D4 TX1`` location that is also connected to the LED on the board. In [``GNSS.h``](../software/GNSS.h) you need to set the ``dynModel = DYN_MODEL_MOWER`` that applies certain configurations required to ZED, you may also need to change the ``odoFactor`` for the wheel circumference as well as the ticks per revolution. 

Bosch lawn mower

Here is the HPG board and antenna mounted to the mower. The GNSS antenna and the IMU sensor are positioned centered above the rear axle, with X axis pointing accurately towards the front. This will ensure best performance and only minimal configuration for sensor fusion is needed. If you displace the antenna from the center rear axle or rotate the board then you may have to configure the lever arm and set IMU alignment.   

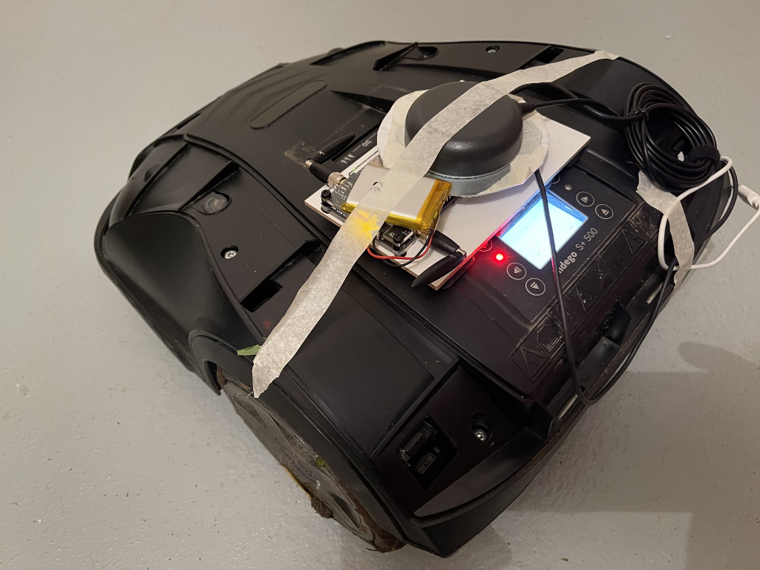
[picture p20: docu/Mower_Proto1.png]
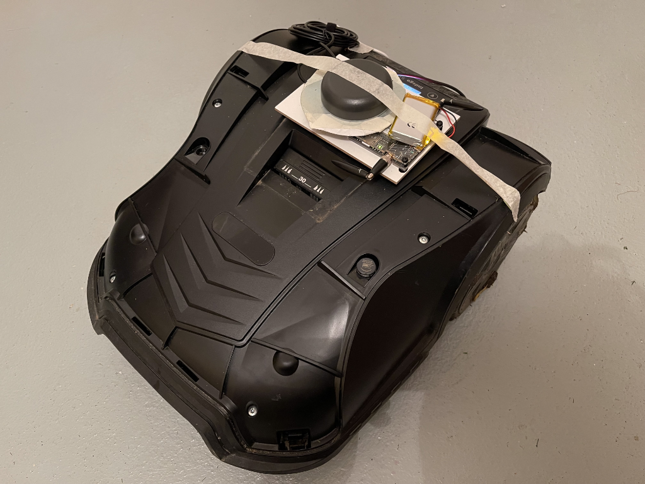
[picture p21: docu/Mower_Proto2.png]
  

Below a short video of the mower and the monitor website in action. This is just a short video with DWT and IMU sensor fusion. 

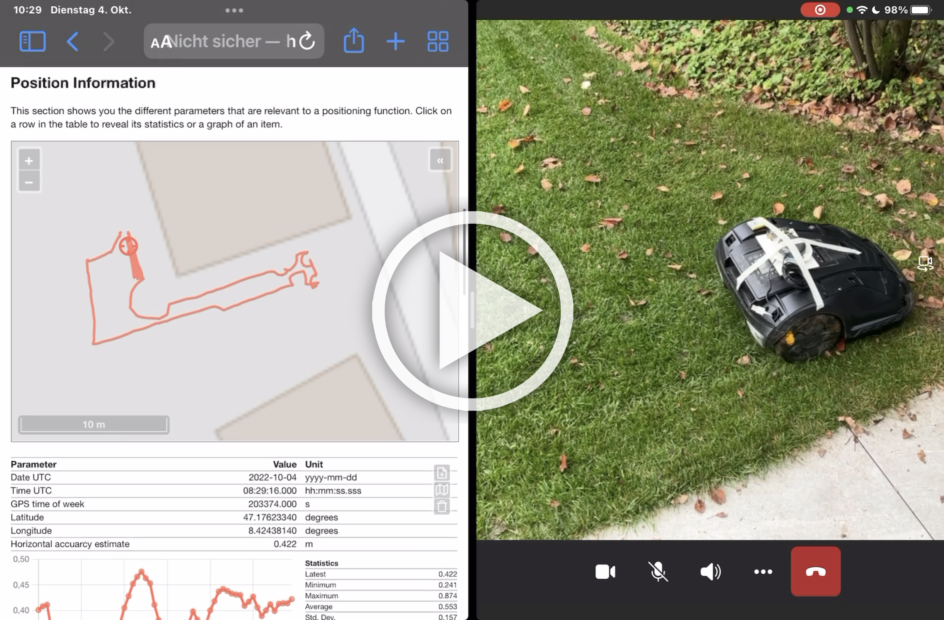
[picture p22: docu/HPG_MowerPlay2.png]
HPG Mower with IMU and DWT Sensor Fusion Video (https://youtu.be/o-bJSjF51Sc)


The first 10 minutes of the next viedo shows the calibration of the sensors and the wheel ticks, during this time, sensor fusion is initializing and calibrating. At position [9:50](https://youtu.be/d0S1z9fmatQ?t=590) the sensor fusion swiches into fusion mode and is now able to naviagte more reliably using the sensors and determine the heading or course over ground even while rotateing at its location. 

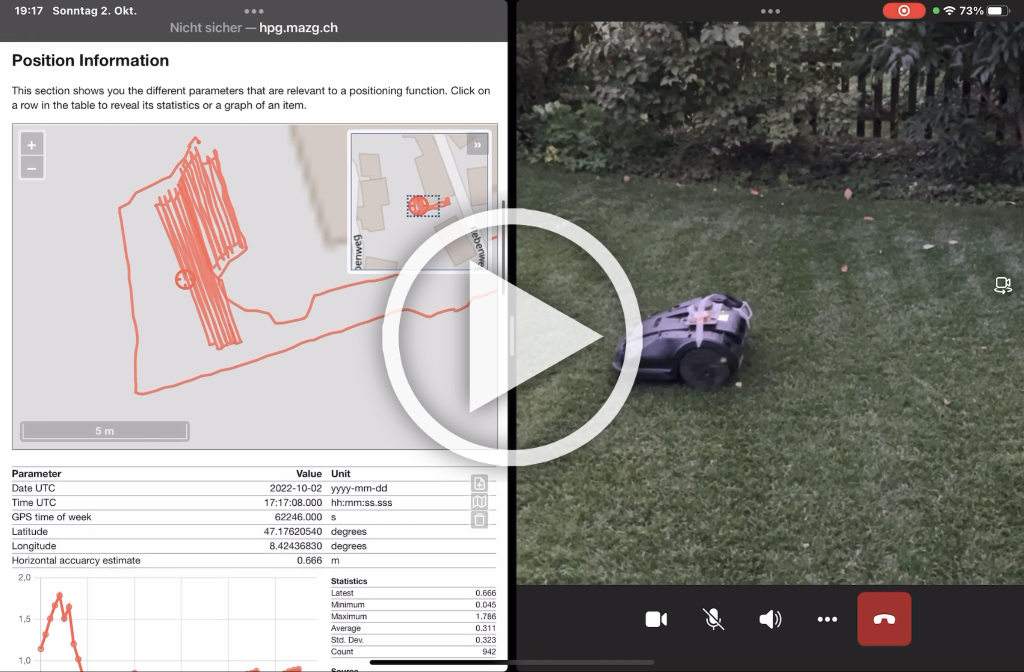
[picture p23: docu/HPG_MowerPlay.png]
HPG Mower with IMU only Sensor Fusion Video (https://youtu.be/d0S1z9fmatQ)


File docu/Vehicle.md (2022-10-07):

# Vehicles (CAN)

The HPG solution can be easily fitted to the CAN bus of a vehicle to support the DR function of the ZED-F9R.

The GPIO4 and GPIO5 of the NINA-W106 can be used to connect a CAN transceiver such as a SN65HVD230. There a simple breakout board that you can attach using jumper wires such as the [CJMCU-230](https://de.aliexpress.com/item/32278648363.html)

An example implementation of a CAN test is part of this project [``CANBUS.h``](../software/CANBUS.h) but the CAN protocol and messages are propritary for every vehicle and brand. The community around Comma.ai has a published a project that contains CAN definition definition files. You can go to their [project on github](https://github.com/commaai/opendbc) to get some information of different vehicles and brands.

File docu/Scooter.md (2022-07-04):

# Scooter

The HPG solution can be easily fitted to a scooter to test the performance. 

Xiaomi Scooter

The scooters from XIAOMI can be easily hacked to extract the Hall sensor signals that are used as a distance sensor by the ZED-F9R WT input. 
The hall sensor are located in the front wheel next to the motor. Their singal are connected to the ESC motor controller that is located in the base of 
the scooter. To open the base plate remove the Torx screws from the bottom side. This will reveal the controlle. The Hall sensor connector 
is the white 5 pin 2mm JST connector. The connector carries three hall sensors signals (yellow, green and blue), 5V (red) and GND (black).
The hall sensors output a signal between 0 and 3.3V when the scooter is on and the wheel is rotated. Select one of the Hall sensors and 
connect it to the ZED-F9R WT input with a series resistor (e.g 1k) to have some isolation and limit the current that can flow. The GND can 
be directly connected to the GND of the HPG solutions. In my case I routed the cable through the steering bar up to the handle bar. You need 
to bypass some foam and squeeze it though the rubber parts along the other cables, but this gives a clean nice setup.

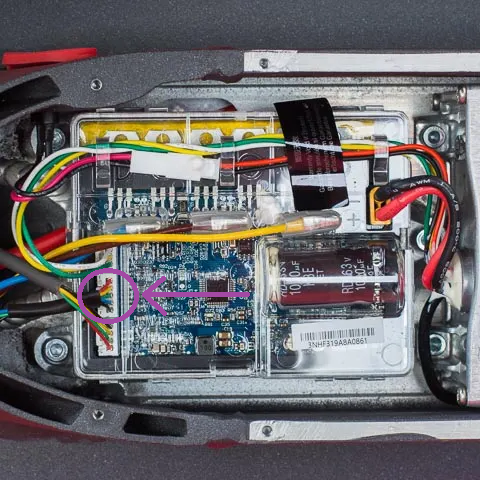
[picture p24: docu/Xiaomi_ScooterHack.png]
Scooter Handle Bar


At the handle bar you need to mount the HPG solution board leveled, with x-axis pointing in drive direction. This is important in order 
to use the default sensor alignment settings, otherwise you need to manually set the alignment of the HPG board with UBX configuration 
commands in the ZED-F9R. Select also the scooter dynamic model and save it. Make sure that you fix the board tightly so that it does not 
fall off or gets tilted on handle bar. The antenna is very critical to achive best performance, use a patch with GND plane or a helix 
antenna. Avoid the other antennas being in close and point them away to avoid obstruction. 

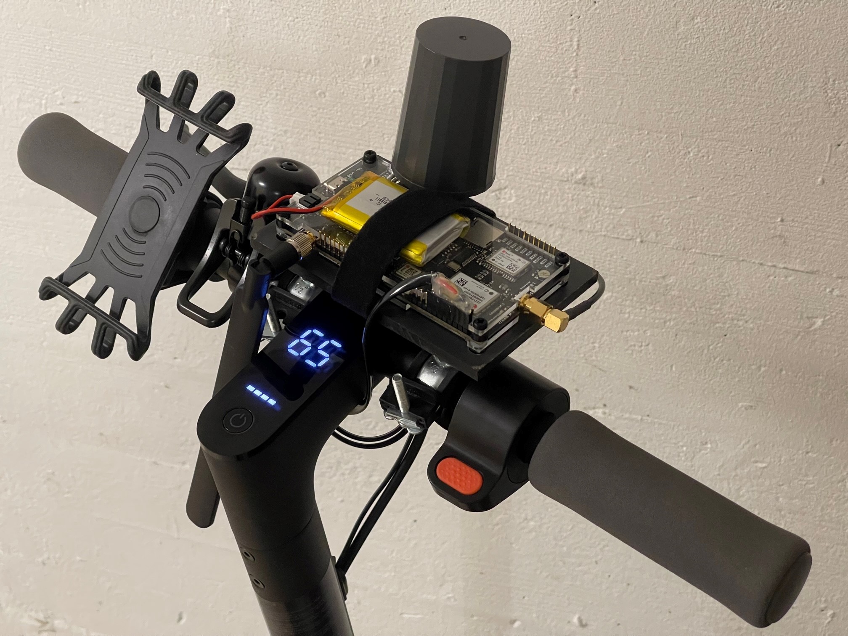
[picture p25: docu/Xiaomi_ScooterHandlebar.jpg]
Scooter Handle Bar


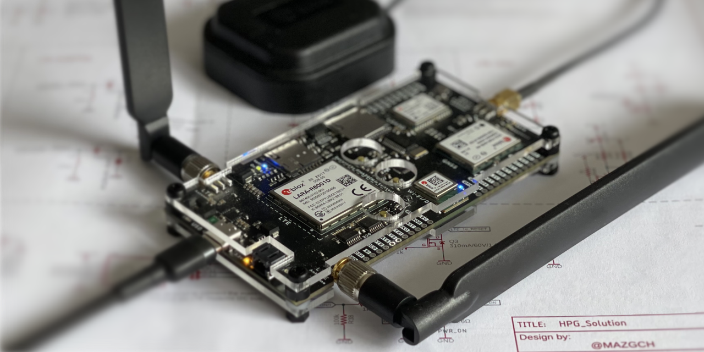
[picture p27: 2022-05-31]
docu/GithubSocialImage.png

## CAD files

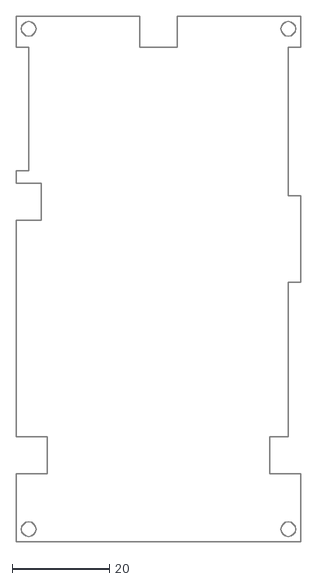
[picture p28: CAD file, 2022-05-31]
hardware/CAMOutputs/Assembly/AcrylGlass_Bot.dxf
58.4 x 108.0

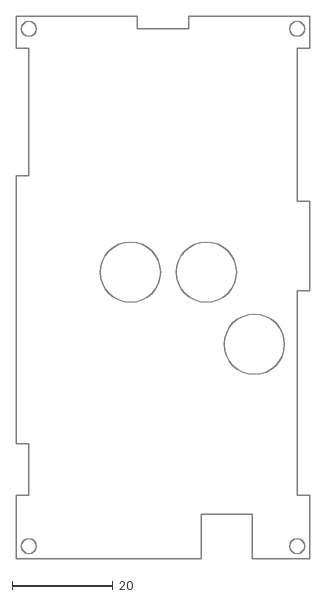
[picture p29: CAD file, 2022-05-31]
hardware/CAMOutputs/Assembly/AcrylGlass_Top.dxf
58.4 x 108.0

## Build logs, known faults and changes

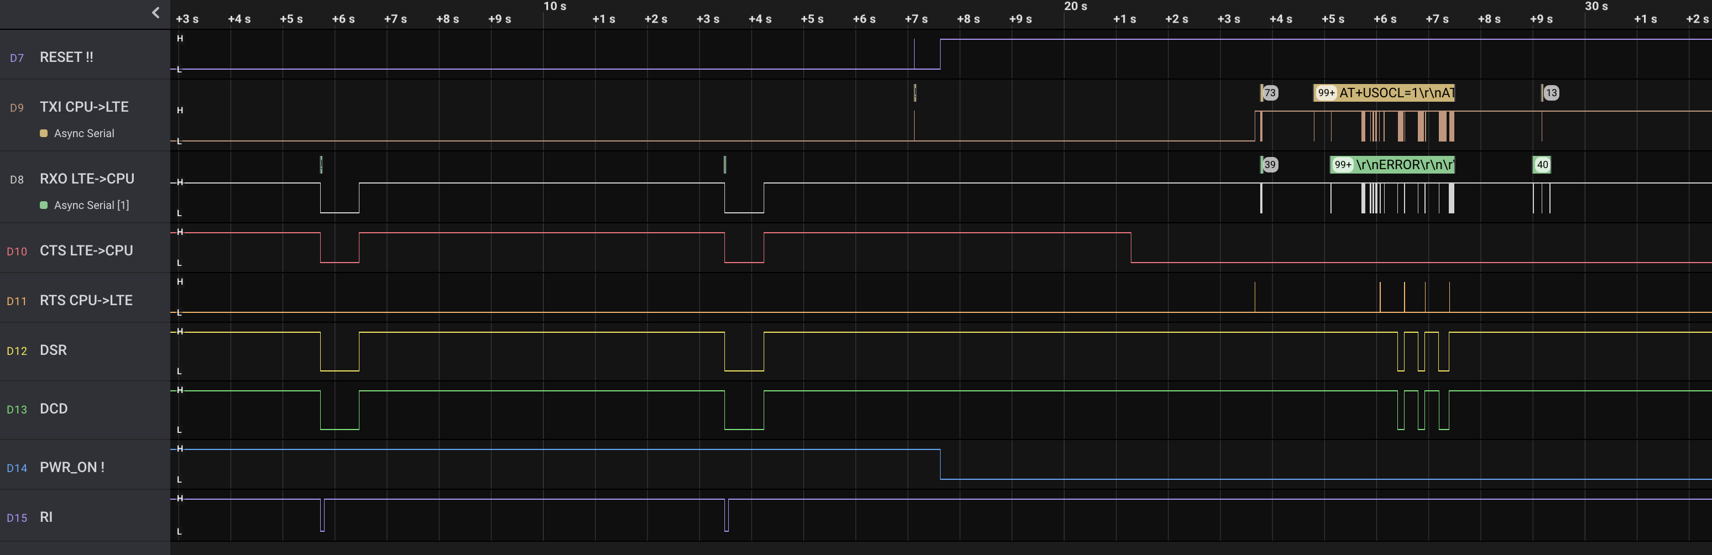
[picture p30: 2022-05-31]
docu/MinorIssue_v09_RESET_PWRON.png

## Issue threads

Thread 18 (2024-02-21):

spi_flash: Detected size(128k) smaller than the size in the binary image header(4096k). Probe failed.

netanbi, 2024-02-21:
Hi,
I program the XPLR module from the Arduino IDE I received this message
do you know how to fix that?

17:00:14.256 ->
17:00:14.256 -> rst:0xc (SW_CPU_RESET),boot:0x33 (SPI_FAST_FLASH_BOOT)
17:00:14.288 -> configsip: 0, SPIWP:0xee
17:00:14.288 -> clk_drv:0x00,q_drv:0x00,d_drv:0x00,cs0_drv:0x00,hd_drv:0x00,wp_drv:0x00
17:00:14.288 -> mode:DIO, clock div:1
17:00:14.288 -> load:0x3fff0030,len:1184
17:00:14.288 -> load:0x40078000,len:13260
17:00:14.288 -> load:0x40080400,len:3028
17:00:14.288 -> entry 0x400805e4
17:00:14.726 -> E (452) spi_flash: Detected size(128k) smaller than the size in the binary image header(4096k). Probe failed.
17:00:14.726 ->
17:00:14.726 -> assert failed: do_core_init startup.c:328 (flash_ret == ESP_OK)
17:00:14.726 ->
17:00:14.726 ->
17:00:14.726 -> Backtrace: 0x40083b7d:0x3ffe3ab0 0x4008df95:0x3ffe3ad0 0x400936ed:0x3ffe3af0 0x4011496a:0x3ffe3c20 0x40083291:0x3ffe3c50 0x40079306:0x3ffe3c90 |<-CORRUPTED
17:00:14.726 ->
17:00:14.726 ->

mazgch, 2024-02-21:
Make sure you select the tight target as indicated on lines 21 in software.ino, also partition must be properly selected.

Try to follow the build instructions at the bottom of software/readme.md

netanbi, 2024-02-22:
Hi,
I follow your response, i still received resets from the nina module
this is my configuration,

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

rst:0x3 (SW_RESET),boot:0x33 (SPI_FAST_FLASH_BOOT)
configsip: 0, SPIWP:0xee
clk_drv:0x00,q_drv:0x00,d_drv:0x00,cs0_drv:0x00,hd_drv:0x00,wp_drv:0x00
mode:DIO, clock div:1
load:0x3fff0030,len:1256
load:0x40078000,len:13832
load:0x40080400,len:4
load:0x40080404,len:3048
entry 0x40080590
ets Jul 29 2019 12:21:46

rst:0x3 (SW_RESET),boot:0x33 (SPI_FAST_FLASH_BOOT)
configsip: 0, SPIWP:0xee
clk_drv:0x00,q_drv:0x00,d_drv:0x00,cs0_drv:0x00,hd_drv:0x00,wp_drv:0x00
mode:DIO, clock div:1
load:0x3fff0030,len:1256

this is the flusing output:
Sketch uses 1415217 bytes (71%) of program storage space. Maximum is 1966080 bytes.
Global variables use 50364 bytes (15%) of dynamic memory, leaving 277316 bytes for local variables. Maximum is 327680 bytes.
"C:\Users\NetanelB\AppData\Local\Arduino15\packages\esp32\tools\esptool_py\4.6/esptool.exe" --chip esp32 --port "COM14" --baud 921600  --before default_reset --after hard_reset write_flash  -z --flash_mode keep --flash_freq keep --flash_size keep 0x1000 "C:\Users\NetanelB\AppData\Local\Temp\arduino\sketches\42A5A684C703AC7993F48E2DF576D34B/software.ino.bootloader.bin" 0x8000 "C:\Users\NetanelB\AppData\Local\Temp\arduino\sketches\42A5A684C703AC7993F48E2DF576D34B/software.ino.partitions.bin" 0xe000 "C:\Users\NetanelB\AppData\Local\Arduino15\packages\esp32\hardware\esp32\3.0.0-alpha3/tools/partitions/boot_app0.bin" 0x10000 "C:\Users\NetanelB\AppData\Local\Temp\arduino\sketches\42A5A684C703AC7993F48E2DF576D34B/software.ino.bin"
esptool.py v4.6
Serial port COM14
Connecting....
Chip is ESP32-D0WD-V3 (revision v3.0)
Features: WiFi, BT, Dual Core, 240MHz, VRef calibration in efuse, Coding Scheme None
Crystal is 40MHz
MAC: e8:31:cd:da:98:ec
Uploading stub...
Running stub...
Stub running...
Changing baud rate to 921600
Changed.
Configuring flash size...
Flash will be erased from 0x00001000 to 0x00005fff...
Flash will be erased from 0x00008000 to 0x00008fff...
Flash will be erased from 0x0000e000 to 0x0000ffff...
Flash will be erased from 0x00010000 to 0x0016bfff...
Compressed 18240 bytes to 12688...
Writing at 0x00001000... (100 %)
Wrote 18240 bytes (12688 compressed) at 0x00001000 in 0.3 seconds (effective 428.1 kbit/s)...
Hash of data verified.
Compressed 3072 bytes to 146...
Writing at 0x00008000... (100 %)
Wrote 3072 bytes (146 compressed) at 0x00008000 in 0.0 seconds (effective 585.1 kbit/s)...
Hash of data verified.
Compressed 8192 bytes to 47...
Writing at 0x0000e000... (100 %)
Wrote 8192 bytes (47 compressed) at 0x0000e000 in 0.1 seconds (effective 866.4 kbit/s)...
Hash of data verified.
Compressed 1421744 bytes to 911452...
Writing at 0x00010000... (1 %)
Writing at 0x0001a06b... (3 %)
Writing at 0x000219ba... (5 %)
Writing at 0x000269cd... (7 %)
Writing at 0x0002be05... (8 %)
Writing at 0x00034754... (10 %)
Writing at 0x0003fd9d... (12 %)
Writing at 0x0004491a... (14 %)
Writing at 0x0004b89a... (16 %)
Writing at 0x00053f0c... (17 %)
Writing at 0x00066b26... (19 %)
Writing at 0x0006ed63... (21 %)
Writing at 0x00074b3a... (23 %)
Writing at 0x0007aae7... (25 %)
Writing at 0x00080a11... (26 %)
Writing at 0x00085f35... (28 %)
Writing at 0x0008c3a0... (30 %)
Writing at 0x00093353... (32 %)
Writing at 0x000996ab... (33 %)
Writing at 0x0009f86f... (35 %)
Writing at 0x000a5b5a... (37 %)
Writing at 0x000ab76b... (39 %)
Writing at 0x000b0ff9... (41 %)
Writing at 0x000b6c9c... (42 %)
Writing at 0x000bc3c0... (44 %)
Writing at 0x000c13df... (46 %)
Writing at 0x000c66c4... (48 %)
Writing at 0x000cba32... (50 %)
Writing at 0x000d0d55... (51 %)
Writing at 0x000d5fa8... (53 %)
Writing at 0x000dafaf... (55 %)
Writing at 0x000e02fa... (57 %)
Writing at 0x000e565d... (58 %)
Writing at 0x000ea61f... (60 %)
Writing at 0x000ef6d3... (62 %)
Writing at 0x000f47ce... (64 %)
Writing at 0x000fa1fe... (66 %)
Writing at 0x000ff9c5... (67 %)
Writing at 0x001050e4... (69 %)
Writing at 0x0010a3fe... (71 %)
Writing at 0x0010f7b1... (73 %)
Writing at 0x00114b13... (75 %)
Writing at 0x0011a029... (76 %)
Writing at 0x0011f30a... (78 %)
Writing at 0x001249e0... (80 %)
Writing at 0x0012a172... (82 %)
Writing at 0x0012ff1b... (83 %)
Writing at 0x001358ab... (85 %)
Writing at 0x0013b036... (87 %)
Writing at 0x0014421a... (89 %)
Writing at 0x0014acd4... (91 %)
Writing at 0x00152361... (92 %)
Writing at 0x001574df... (94 %)
Writing at 0x0015cd78... (96 %)
Writing at 0x001621d0... (98 %)
Writing at 0x00167778... (100 %)
Wrote 1421744 bytes (911452 compressed) at 0x00010000 in 15.0 seconds (effective 757.4 kbit/s)...
Hash of data verified.

Leaving...
Hard resetting via RTS pin...

mazgch, 2024-02-22:
I think the module on the board is the -10B version with bigger flash. But not sure if this will improve as you used a small partition.

In case you have the u-blox version (green board) have you changed the HW.h file?

I don't see any resets in your report.

Maybe try to enable core debug.

netanbi, 2024-02-22:
I have the black xplr module, like in documents,
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

I configure it like in :
// After that select Board u-blox NINA-W10 series and configure the target CPU: 240MHz, Flash: 80MHz, 4MB, Minimal SPIFFS

i did not touch anything in HW.h

do I need to change something with the black module?
is the partition that I selected correct?
this is the serial monitor output :
see the first row
**rst:0x3 (SW_RESET),boot:0x33 (SPI_FAST_FLASH_BOOT)**
configsip: 0, SPIWP:0xee
clk_drv:0x00,q_drv:0x00,d_drv:0x00,cs0_drv:0x00,hd_drv:0x00,wp_drv:0x00
mode:DIO, clock div:2
load:0x3fff0030,len:1256
load:0x40078000,len:13816
load:0x40080400,len:4
load:0x40080404,len:3048
entry 0x40080590
ets Jul 29 2019 12:21:46

netanbi, 2024-02-22:
can you please what is you setup that work ? esp32 board library version ? configuration ?

gabrielyoung92, 2024-04-29:
I've had this same problem, it is a problem with the ESP32 board manager.  If you install V2.0.10 or later this will occur nor matter the sketch - "Blink" will do the same issue!  You need to downgrade to 2.0.9 or lower
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

mazgch, 2024-04-29:
Related to: https://github.com/espressif/esp-idf/issues/12222

mazgch, 2024-05-29:
arduino_esp32 v3.0.0 (https://github.com/espressif/arduino-esp32/releases/tag/3.0.0) with esp core 5.1 seems to solve this issue, but several libraries needed are not yet compatible or create several warnings

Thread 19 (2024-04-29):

Monitor page keeps refreshing

gabrielyoung92, 2024-04-29:
I have an issue where the monitor page (https://hpg.mazg.ch/monitor/) keeps refreshing constantly without loading.  Tested this on Chrome, Chrome (Incognito mode), Edge, and Android phone (Chrome) with all the browsers doing the same thing.  Initially, the page loaded fine

In the attached video the web UI as presented by the module loads and can be refreshed ok.  As soon as "Monitor" is clicked it redirects to the monitor page and just continues to reload.  Even if you load the URL without the "?ip=" it will keep reloading
https://github.com/mazgch/hpg/assets/76025494/8c666195-05f9-4e50-8c57-a9271216ee74

The hardware is a ublox-xplr-hpg-2-gnss-kit

mazgch, 2024-04-29:
What is page-script.js

Does it happen if there is no device avaialble. Just unpower it.

Can you give me any hint what might be the last thing that done before it reloads, maybe try to break on any exceptions.

gabrielyoung92, 2024-04-29:
This is the Passkey feature of my Bitwarden password manager.  This issue also occurs in other browsers where I do not use Bitwarden
chrome-extension://nngceckbapebfimnlniiiahkandclblb/content/fido2/page-script.js

I was able to capture the network tab again, it looks like it is trying to load HTTP then gets a redirect to HTTPS
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

It looks like under hpg/monitor/js/monitor.js Line 38, it is trying to redirect HTTPSback to HTTP, then GitHub reverses it back to HTTPS when serving the page

mazgch, 2024-04-29:
The https will not work with this page as it will cause issues with mixed content as the websocket on the device is using insecure ws (not wss) connection. You have to use the http://hpg.mazg.ch/monitor/ this is why the page will redirect to http if it was loaded using https protocol. It should stay with http it is not clear to me why it would redirect back to https.

mazgch, 2024-04-30:
Now a message box will popup before redirecting. Can you confirm that it is wirking with http so we can close this?

gabrielyoung92, 2024-04-30:
I have just loaded the latest copy of the code onto the module
A popup does appear now but if I click OK it goes into an endless loop
If I click cancel the attached the page loads but freezes.
Please see attached video

https://github.com/mazgch/hpg/assets/76025494/8ed7c7b8-0c2d-4ced-a552-17b9e7ca9ff1

mazgch, 2024-05-01:
Have you tried to enter http://hpg.mazg.ch/monitor/ manualy ?

gabrielyoung92, 2024-05-02:
Originally doing that didn't work, but since Chrome has just updated it works now and the page loads.  It does product that message once, clicking ok then manually changing https:// to HTTP:// works.  Thanks

mazgch, 2024-05-03:
Thanks Gabriel for confirming and sorry for the inconvenience, if you have a proposal/fix how to improve don't hesitate to send me a pull request.

Closed 2024-05-02.

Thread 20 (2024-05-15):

LTE socket error when verifying

phant0m85, 2024-05-15:
I am using esp32 2.0.9 with all recommended library versions listed in software.ino. This issue is only with the latest version. I would like to use LTE. Anything I am doing incorrectly? Should I just build it given the listed errors?

In file included from C:\git_repos\mazgch\hpg\software\software.ino:76:
C:\git_repos\mazgch\hpg\software\LTE.h: In member function 'bool LTE::ntripConnect(String)':
C:\git_repos\mazgch\hpg\software\LTE.h:483:22: error: 'socketSetSecure' was not declared in this scope
       LTE_CHECK(6) = socketSetSecure(ntripSocket, proto.equalsIgnoreCase("https"), LTE_SEC_PROFILE_NTRIP);
                      ^~~~~~~~~~~~~~~
C:\git_repos\mazgch\hpg\software\LTE.h:483:22: note: suggested alternative: 'socketConnect'
       LTE_CHECK(6) = socketSetSecure(ntripSocket, proto.equalsIgnoreCase("https"), LTE_SEC_PROFILE_NTRIP);
                      ^~~~~~~~~~~~~~~
                      socketConnect

exit status 1

Compilation error: 'socketSetSecure' was not declared in this scope

mazgch, 2024-05-15:
Could you please chevk the Sparkfun SARA-R5 library version. This was recently added in a pull request to SFe library.

mazgch, 2024-05-15:
https://github.com/sparkfun/SparkFun_u-blox_SARA-R5_Arduino_Library/commit/11cc451de73bfaa79af345b26d6cac0fa0ab6971

phant0m85, 2024-05-15:
Ah, good catch. I was using Sparkfun SARA-R5 library version 1.1.10. After updating, it now verifies. Thank you very much for the fast reply!

Closed 2024-05-15.

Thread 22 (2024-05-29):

NTRIP correction over LTE fails, but over WIFI works fine

gabrielyoung92, 2024-05-29:
I am having an issue with using NTRIP correction data over LTE where it will perform the ntripConnect() [LTE.h:548] but will not get any data.  This is both true for HTTPS (443) and HTTP (2101).  However correctional data will work fine over WIFI.  I am not using PointPerfect

A difference that can be seen in the attached screenshots
LTE_HTTPS, The connection debug string shows the server URL without the mount point and doesn't go any further
LTE_HTTP, the URL string is full, and the GET line comes through [LTE.h:497] but then disconnects.  This will then loop and try to connect

The hardware I am using is the C214 dev board - The SIM that is inserted into the LARA-R6 module is confirmed working even with m-centre

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

mazgch, 2024-05-29:
Are you blanking the password and user names in those screenshots or are they really empty?

Is there any way I could try this, I must admit I have not tested a lot with LTE as I need to swap SIMs.

gabrielyoung92, 2024-05-29:
Yes, i have blanked out username/passwords.  There are proper credentials which do work.

To use the source of the NTRIP I am using, you can sign up https://gnss.ga.gov.au/stream
It is a free service here in Australia

The particular source that I am using is  [/MBCH00AUS0]  http://ntrip.data.gnss.ga.gov.au:443/MBCH00AUS0

mazgch, 2024-05-29:
I just added some debug messages that might give us better clues of what is happening or blocking the code to proceed. Just pull them. I might be able to try it later today when I am home.

gabrielyoung92, 2024-05-31:
Sorry this took a while, I had an issue where the modem was refusing to register to the network here.  it is now working
I have attached 2x log files where I have also enabled  [Lte.enableAtDebugging]  Both methods act different.
It looks like I can get HTTP over LTE to work.  Not sure about HTTPS yet

I've done some testing using PUTTY and found that a header is required
[PuttySocket_Failed.txt](https://github.com/user-attachments/files/15507934/PuttySocket_Failed.txt)

I created a socket and put in the host part and now I'm getting data through putty
[PuttySocket_Success.txt](https://github.com/user-attachments/files/15507928/PuttySocket_Success.txt)

I did alter the LTE code a little to try and add the Host header but it doesn't seem to work for me
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

=== MCU Serial Output data ===
For HTTP it looks like the socket is opened and data is sent to the server (Lines 33-41) but when the read socket (26.13 Read Socket Data +USORD) is attemped there is never any data ready
[HTTP_Log_Serial.txt](https://github.com/user-attachments/files/15507869/HTTP_Log_Serial.txt)

For HTTPS, line 61 the MCU sends [AT+USOWR=0,242] to the LTE module but gets an error back  (26.11 Write socket data +USOWR) returns an error
[HTTPS_Log_Serial.txt](https://github.com/user-attachments/files/15507870/HTTPS_Log_Serial.txt)
(Serial);]

mazgch, 2024-06-01:
I pushed some fixes to LTE.h. Seems there was an additional cr/lr missing for this server. At least insecure connection using http and 2101 now works

```
[  5230][_][LTE.h:753] lteRegistered(): registered 1(home) operator "Swisscom" rssi 27 clock "24/06/01,15:35:49+08"
[  5259][_][LTE.h:890] setState(): state change 4(registered)
[  5294][_][LTE.h:890] setState(): state change 5(online)
[  5517][D][LTE.h:482] ntripConnect(): server "http://ntrip.data.gnss.ga.gov.au:2101"
[  5656][_][GNSS.h:302] onPVT(): 11.9.2022 00:21:48 lat 0.0000000 lon 0.0000000 msl -17.000 fix 0(No) carr 0(No) hacc 4294967.295 source -
[  5923][D][LTE.h:496] ntripConnect(): GET "/MBCH00AUS0" user="username" pwd="password" auth="scrambleduserpwd" ver="Ntrip/2.0"
[  6354][_][LTE.h:535] ntripConnect(): url "http://ntrip.data.gnss.ga.gov.au:2101/MBCH00AUS0" user "username" pwd "password" ver "Ntrip/2.0" connected
[  6368][_][LTE.h:890] setState(): state change 7(ntrip)
[  6431][_][LTE.h:591] ntripTask(): read 111 bytes
[  6510][_][LTE.h:612] ntripTask(): write "$GPGGA,131240.00,0000.0000,N,00000.0000,E,1,31,0.87,453.4,M,47.3,M,,*5C\r\n" 71 bytes
```

I did not get the https/443 version working so far. probably something to to with the TLS negotiation.

Here also just for completeness the two curl requests that worked from the console.
```
~ % curl -v -u username:password -f -v --http0.9 --header "Ntrip-Version: Ntrip/2.0" "https://ntrip.data.gnss.ga.gov.au:443/MBCH00AUS0"
* Host ntrip.data.gnss.ga.gov.au:443 was resolved.
* IPv6: (none)
* IPv4: 3.104.156.106, 52.65.142.231, 13.237.241.59
*   Trying 3.104.156.106:443...
* Connected to ntrip.data.gnss.ga.gov.au (3.104.156.106) port 443
* ALPN: curl offers h2,http/1.1
* (304) (OUT), TLS handshake, Client hello (1):
*  CAfile: /etc/ssl/cert.pem
*  CApath: none
* (304) (IN), TLS handshake, Server hello (2):
* TLSv1.2 (IN), TLS handshake, Certificate (11):
* TLSv1.2 (IN), TLS handshake, Server key exchange (12):
* TLSv1.2 (IN), TLS handshake, Server finished (14):
* TLSv1.2 (OUT), TLS handshake, Client key exchange (16):
* TLSv1.2 (OUT), TLS change cipher, Change cipher spec (1):
* TLSv1.2 (OUT), TLS handshake, Finished (20):
* TLSv1.2 (IN), TLS change cipher, Change cipher spec (1):
* TLSv1.2 (IN), TLS handshake, Finished (20):
* SSL connection using TLSv1.2 / ECDHE-RSA-AES128-GCM-SHA256 / [blank] / UNDEF
* ALPN: server did not agree on a protocol. Uses default.
* Server certificate:
*  subject: CN=*.prod-data.gnss.ga.gov.au
*  start date: Nov 13 00:00:00 2023 GMT
*  expire date: Dec 12 23:59:59 2024 GMT
*  subjectAltName: host "ntrip.data.gnss.ga.gov.au" matched cert's "*.data.gnss.ga.gov.au"
*  issuer: C=US; O=Amazon; CN=Amazon RSA 2048 M02
*  SSL certificate verify ok.
* using HTTP/1.x
* Server auth using Basic with user 'mazgch'
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
< HTTP/1.1 200 OK
< Connection: close
< Content-Type: gnss/data
< Date: Sat, 01 Jun 2024 13:20:08 GMT
< Transfer-Encoding: chunked
<
Warning: Binary output can mess up your terminal. Use "--output -" to tell
Warning: curl to output it to your terminal anyway, or consider "--output
Warning: <FILE>" to save to a file.
* Failure writing output to destination
* Failed reading the chunked-encoded stream
* Closing connection
* TLSv1.2 (OUT), TLS alert, close notify (256):
... ~ % curl -v -u user:password -f -v --http0.9 --header "Ntrip-Version: Ntrip/2.0" "http://ntrip.data.gnss.ga.gov.au:2101/MBCH00AUS0"
* Host ntrip.data.gnss.ga.gov.au:2101 was resolved.
* IPv6: (none)
* IPv4: 3.104.156.106, 52.65.142.231, 13.237.241.59
*   Trying 3.104.156.106:2101...
* Connected to ntrip.data.gnss.ga.gov.au (3.104.156.106) port 2101
* Server auth using Basic with user 'mazgch'
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
< HTTP/1.1 200 OK
< Connection: close
< Content-Type: gnss/data
< Date: Sat, 01 Jun 2024 13:21:11 GMT
< Transfer-Encoding: chunked
<
Warning: Binary output can mess up your terminal. Use "--output -" to tell
Warning: curl to output it to your terminal anyway, or consider "--output
Warning: <FILE>" to save to a file.
* Failure writing output to destination
* Failed reading the chunked-encoded stream
* Closing connection

```

gabrielyoung92, 2024-06-02:
Morning,

ALmost there, I had to add another line to the code to get it to work. Now I am receiving the NTRIP data over LTE and even getting the RTK led to flash on the PCB

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

mazgch, 2024-06-03:
Nice that you got the same solutions.

gabrielyoung92, 2024-06-03:
Hi Michael,

Yes, we can close this now.  I believe that using the correction data over an unencrypted channel is acceptable as it is already publicly accessible data. Thanks for your help with this.

Gab

Closed 2024-06-03.

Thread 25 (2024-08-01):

Change the baudrate of the tx/rx pins of the UART on the XPLR-HPG-2 board

etonucci, 2024-08-01:
Dear Michael,
I tryed to change the baudrate of the tx/rx pins of the UART on the XPLR-HPG-2 board without succes.
I tryed to change the UART1 baudrate from the UBX->CFG->PRT menu and then save the configuration by the UBX->CFG->CFG menu from the u-center software, but the speed doesn't change!
There is a possibility to chenge this speed from your code?

Thank you in advance.

Emanuele
[Michael Ammann Github.pdf](https://github.com/user-attachments/files/16457065/Michael.Ammann.Github.pdf)

mazgch, 2024-08-01:
You need to use the new configuration view with config keys for F9 generation. It is described in the F9 interface manuals. It is the UBX-CFG-SETVAL ... messages

The old u-blox m8 config messages are no longer supported in 9th generation.

mazgch, 2024-08-01:
You can also set this from the software look at the init code in GNSS.h and set the additional UART1 Baudrate config key

etonucci, 2024-08-02:
Dear Michael,

thank you very much for your support.

I tryed to insert this istructions:

GNSS_CHECK(15) = rx.setVal(UBLOX_CFG_UART1_BAUDRATE, 115200, VAL_LAYER_RAM);

or

GNSS_CHECK(15) = rx.setVal(UBLOX_CFG_UART1_BAUDRATE, 0x0001C200, VAL_LAYER_RAM);

before the istructions

online = ok = GNSS_CHECK_OK;

GNSS_CHECK_EVAL("configuration");

but I received this error

Thank you again

Emanuele

Da: Michael Ammann ***@***.***
Inviato: giovedì 1 agosto 2024 17:39
A: mazgch/hpg ***@***.***>
Cc: Ing. Emanuele Tonucci ***@***.***>; Author ***@***.***>
Oggetto: Re: [mazgch/hpg] Change the baudrate of the tx/rx pins of the UART on the XPLR-HPG-2 board (Issue #25)

You can also set this from the software look at the init code in GNSS.h and set the additional UART1 Baudrate config key

—
Reply to this email directly, view it on GitHub <https://github.com/mazgch/hpg/issues/25#issuecomment-2263380206> , or unsubscribe <https://github.com/notifications/unsubscribe-auth/ADKXBKK6IA5TCMXD2IXKYC3ZPJJCPAVCNFSM6AAAAABL2R4FA2VHI2DSMVQWIX3LMV43OSLTON2WKQ3PNVWWK3TUHMZDENRTGM4DAMRQGY> .
You are receiving this because you authored the thread.  <https://github.com/notifications/beacon/ADKXBKKLHBGLJSEAGGSJVZLZPJJCPA5CNFSM6AAAAABL2R4FA2WGG33NNVSW45C7OR4XAZNMJFZXG5LFINXW23LFNZ2KUY3PNVWWK3TUL5UWJTUG5BYO4.gif> Message ID: < ***@***.***> ***@***.***>

--
Questa email è stata esaminata alla ricerca di virus dal software antivirus AVG.
www.avg.com

mazgch, 2024-08-02:
You may also use directly the Sparkfun API for changing baudrate rx.setSerialRate(112500, ...)

etonucci, 2024-08-02:
Dear Michael,

thank you very much!

Now it’s works!

You are Great!

Emanuele

Da: Michael Ammann ***@***.***
Inviato: venerdì 2 agosto 2024 13:50
A: mazgch/hpg ***@***.***>
Cc: Ing. Emanuele Tonucci ***@***.***>; Author ***@***.***>
Oggetto: Re: [mazgch/hpg] Change the baudrate of the tx/rx pins of the UART on the XPLR-HPG-2 board (Issue #25)

You may also use directly the Sparkfun API for changing baudrate rx.setSerialRate(112500, ...)

—
Reply to this email directly, view it on GitHub <https://github.com/mazgch/hpg/issues/25#issuecomment-2265188782> , or unsubscribe <https://github.com/notifications/unsubscribe-auth/ADKXBKKVNIDQXPETNP2AS2DZPNW5LAVCNFSM6AAAAABL2R4FA2VHI2DSMVQWIX3LMV43OSLTON2WKQ3PNVWWK3TUHMZDENRVGE4DQNZYGI> .
You are receiving this because you authored the thread.  <https://github.com/notifications/beacon/ADKXBKIEO5QIIP555QRKHETZPNW5LA5CNFSM6AAAAABL2R4FA2WGG33NNVSW45C7OR4XAZNMJFZXG5LFINXW23LFNZ2KUY3PNVWWK3TUL5UWJTUHAQE24.gif> Message ID: ***@***.*** ***@***.***> >

--
Questa email è stata esaminata alla ricerca di virus dal software antivirus AVG.
www.avg.com

Closed 2024-08-02.

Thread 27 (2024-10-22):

DeadReckon Question

Geromatic, 2024-10-22:
how can I turn on dead reckoning or is it on by default?

mazgch, 2024-10-22:
Basically you can switch the GNSS_DYNAMIC_MODE to your platform and need to wire up the system to your vehicle so that is get the speed or tick information.

Setting up DR is not easy, you need some engineering skills and knowledge. It is all documented, I suggest to also read the u-blox manuals on DR.

Michael

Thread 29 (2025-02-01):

Don't find bluetooth device, problem with wifi connection

rodolfoblanchietti, 2025-02-01:
Hallo,
I build (with bluetooth option) and flashed the program,
but I have two problems:

1) I can't find xplr-hpg-2 via bluetooth way;
2) If I connect  xplr-hpg-2 with wifi at the page  http://hpg.mazg.ch/monitor/
   I only see the screenshoot's page and no else, and I can't find
   the page at https://github.com/mazgch/hpg/tree/main/monitor

How can I solve the problem?
Than you very much
Rodolfo Blanchietti

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

mazgch, 2025-02-03:
Sorry - but you need to better describe your problem, your setup, what you are doing or have compiled. It is unclear from the information you share here.

rodolfoblanchietti, 2025-02-04:
Hello Michael,
thank you for your fast reply,

1. I downloaded at the page https://github.com/mazgch/hpg  your software.
2. I enabled all feature execpt canbus (picture 1) and I compilated
   the sofware without  problems.
2. At the page https://github.com/mazgch/hpg/tree/main/software  I see that I
   should reach the two picture above (picture 2-3)
3. I enabled wifi, bluetooth.
4. but I'm only able to reach the page of the fourth picture, Why?

I hope I was clear.
Thank you very much.
Rodolfo Blanchietti

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

mazgch, 2025-02-04:
Cam be many things. Maybe you have disabled point to point communication in your network.

Try watching zhe videos, reading all documentation, maybe even ask a knowledgeable colleague for help.

You are still not providing the serial output if you device, which I therefore assume you have not looked at. The serial output gives good infication egat is happening.

I also dont understand why you would add bluetooth to the project, but then try to access using wifi http/websocket? Have you tried swmaps with the bluetooth feature?

This is sn adanced project that involves many tasks, functions and hardware, maybe try starting with some simple arduino or esp projects.

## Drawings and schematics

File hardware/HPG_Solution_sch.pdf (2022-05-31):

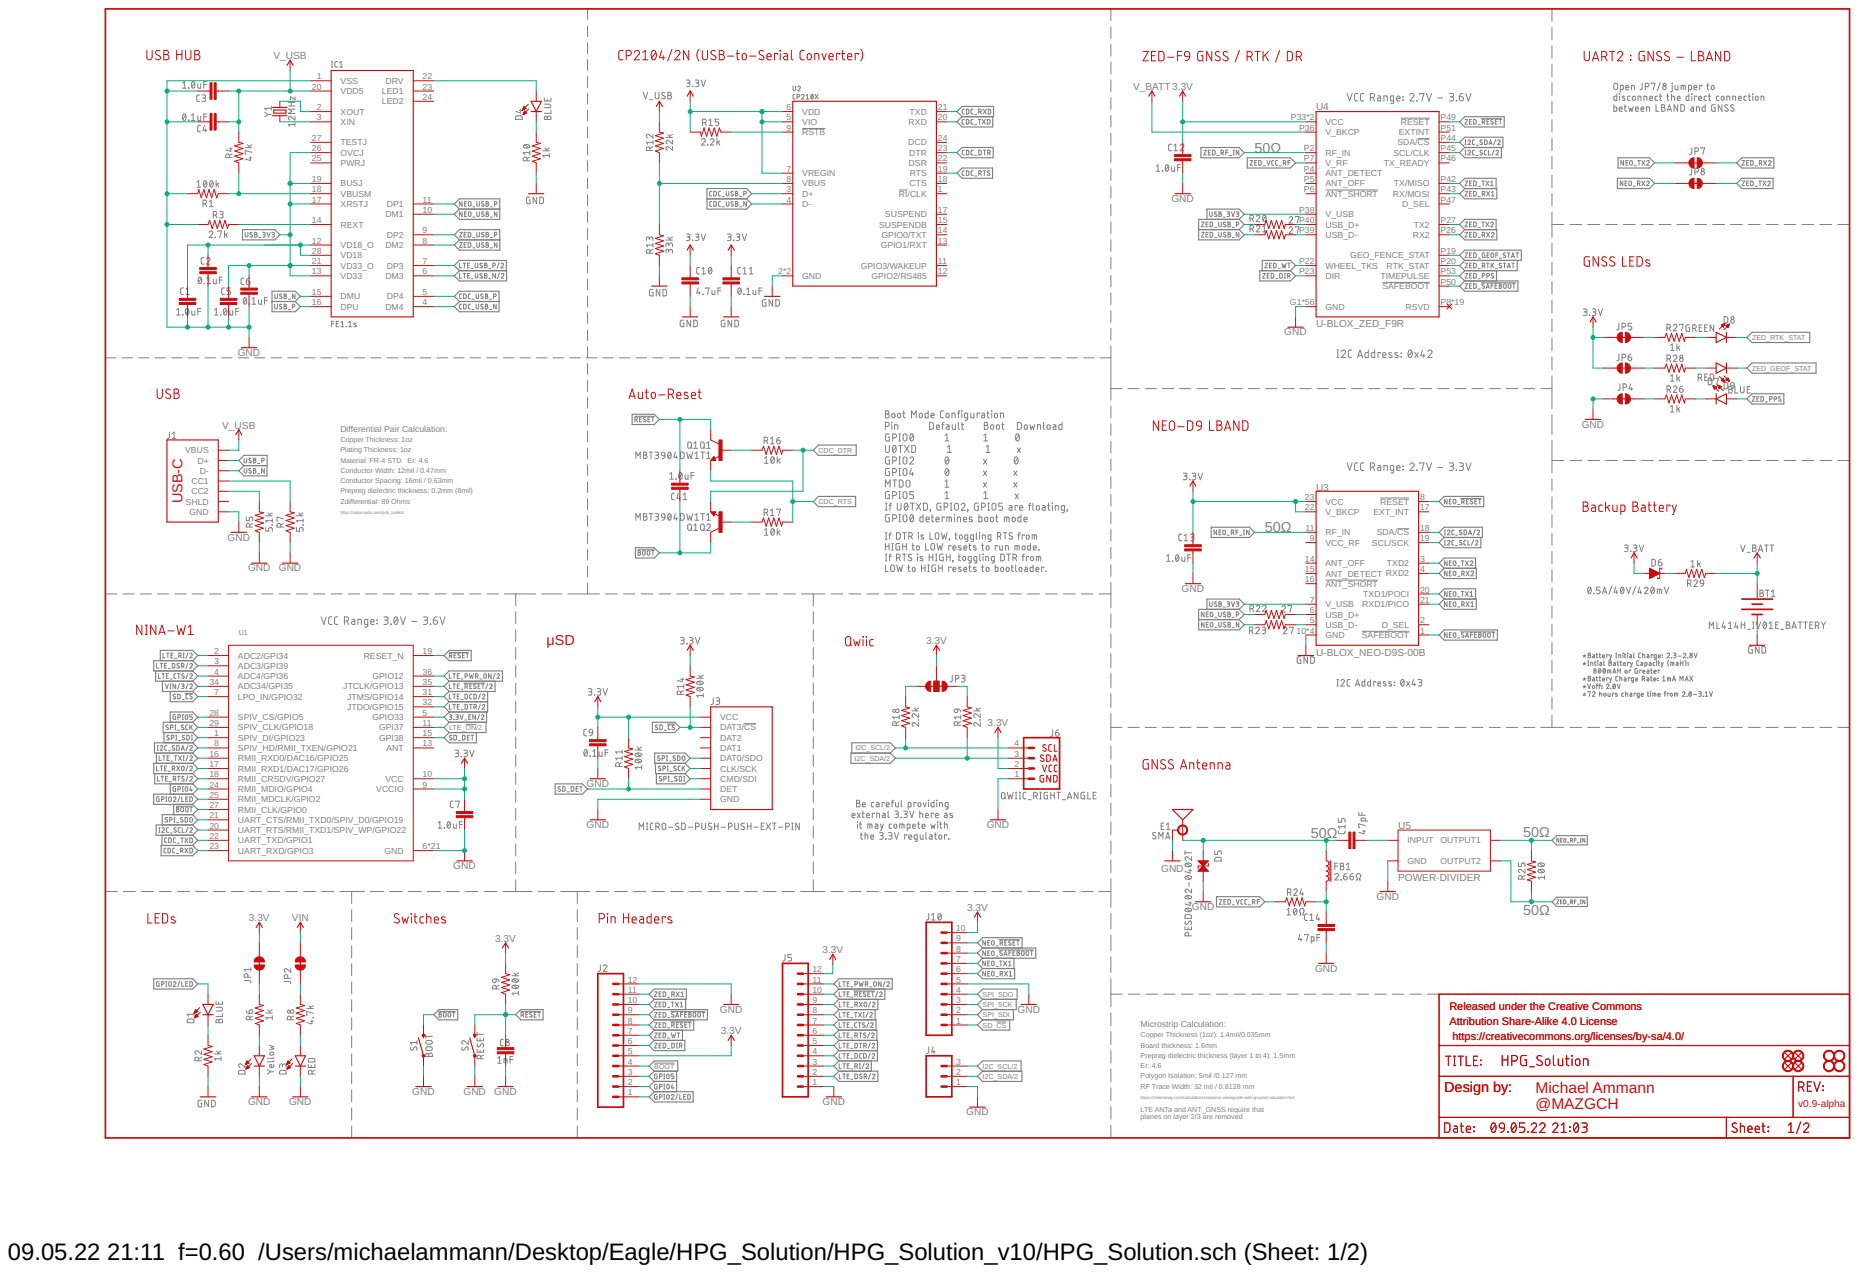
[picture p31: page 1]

Differential Pair Calculation:
Plating Thickness: 1oz Material: FR-4 STD Er: 4.6 Copper Thickness: 1oz Conductor Spacing: 16mil / 0.63mm

Prepreg dielectric thickness: 0.2mm (8mil) https://saturnpcb.com/pcb_toolkit/
Zdifferential: 89 Ohms

VCC
DAT3/CS CMD/SDI DAT0/SDO
DAT2 DAT1 CLK/SCK DET

Released under the Creative Commons Attribution Share-Alike 4.0 License

Microstrip Calculation:
Er: 4.6 Copper Thickness (1oz): 1.4mil/0.035mm
Board thickness: 1.6mm
Prepreg dielectric thickness (layer 1 to 4): 1.5mm

https://creativecommons.org/licenses/by-sa/4.0/ Design by:

Polygon Isolation: 5mil /0.127 mm
RF Trace Width: 32 mil / 0.8128 mm

https://chemandy.com/calculators/coplanar-waveguide-with-ground-calculator.htm
LTE ANTa and ANT_GNSS require that planes on layer 2/3 are removed

09.05.22 21:11 f=0.60 /Users/michaelammann/Desktop/Eagle/HPG_Solution/HPG_Solution_v10/HPG_Solution.sch (Sheet: 1/2)

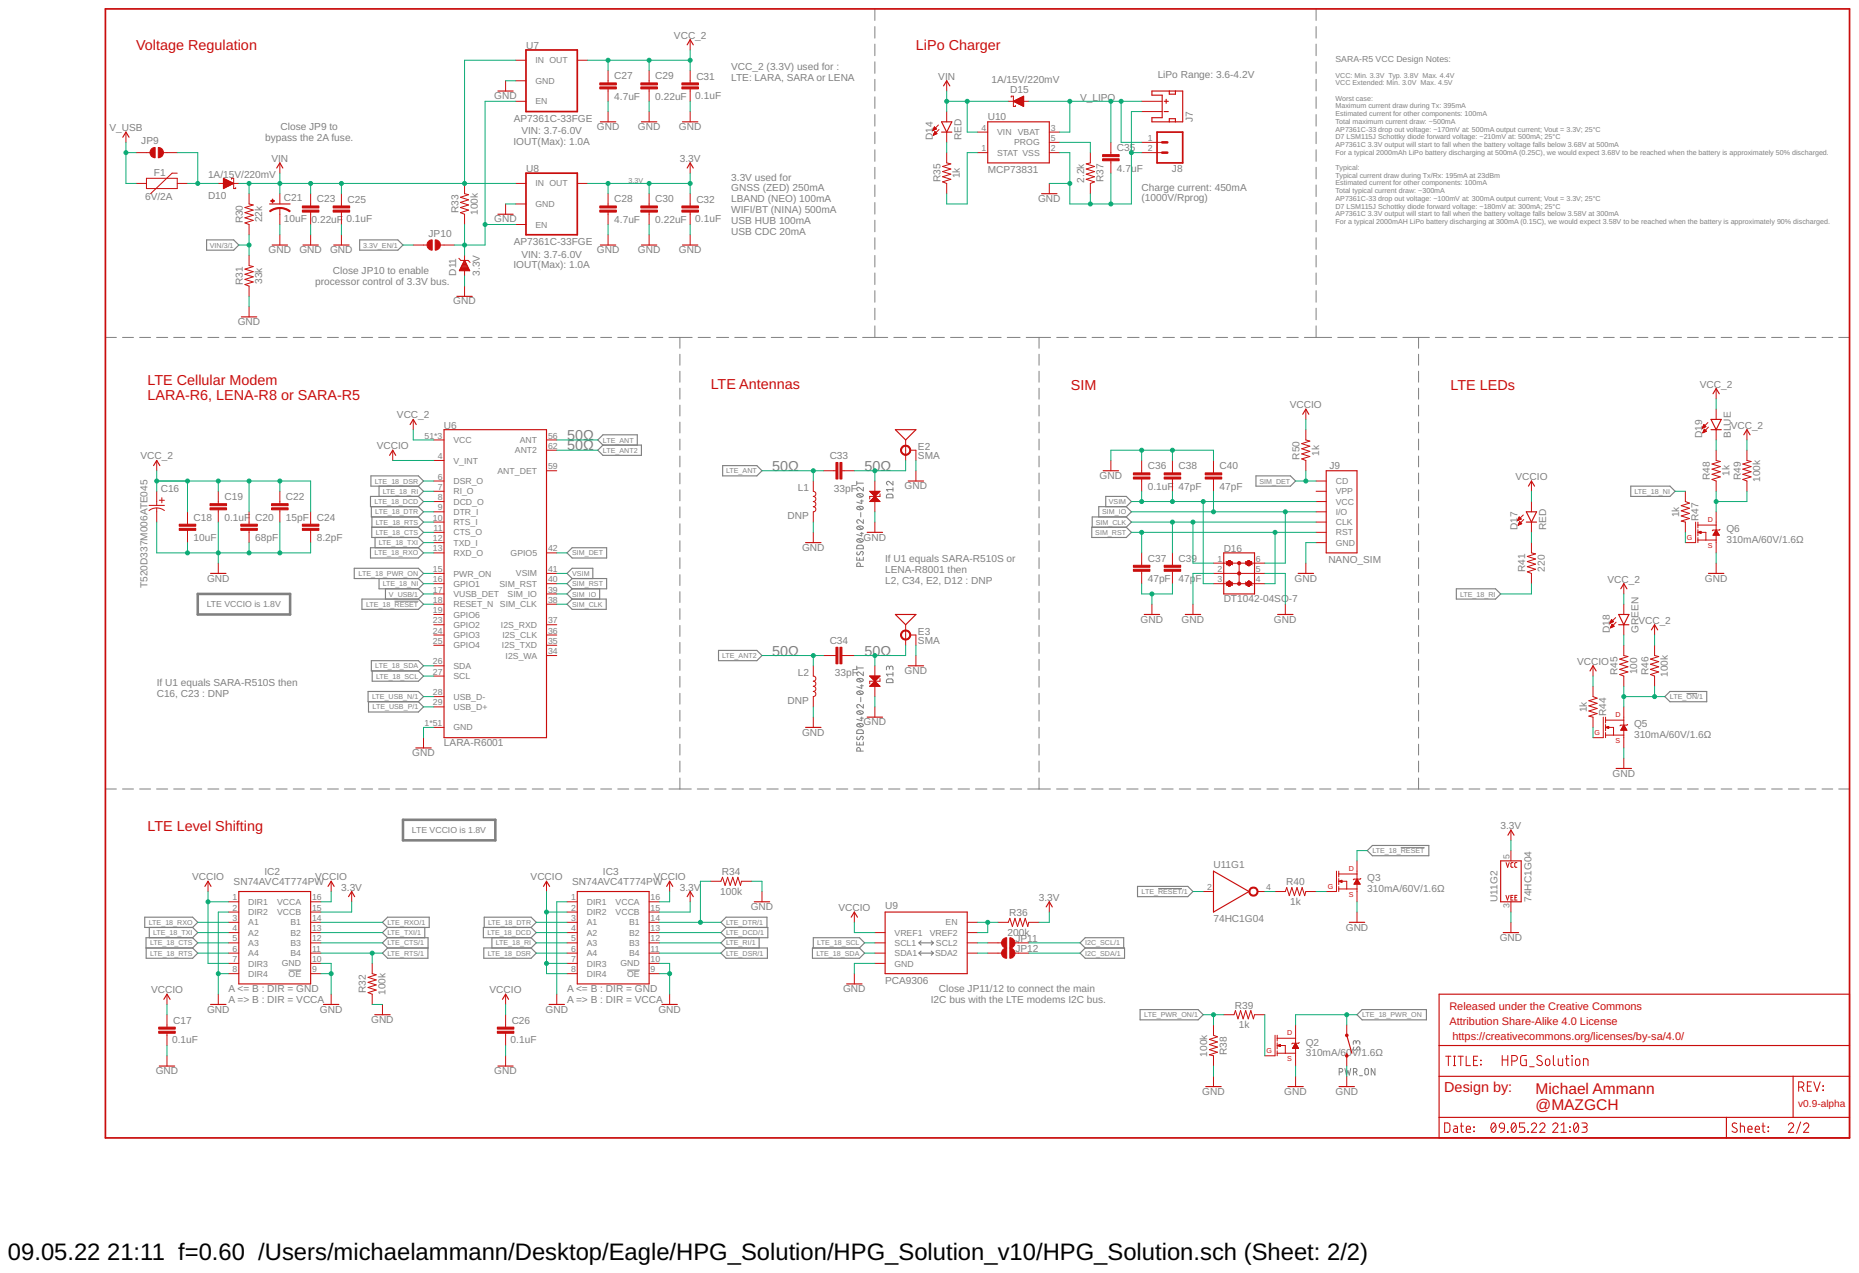
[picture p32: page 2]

VCC_2 (3.3V) used for : LTE: LARA, SARA or LENA

SARA-R5 VCC Design Notes: VCC: Min. 3.3V Typ. 3.8V Max. 4.4V

VCC Extended: Min. 3.0V Max. 4.5V Worst case: Maximum current draw during Tx: 395mA

Estimated current for other components: 100mA
Total maximum current draw: ~500mA
AP7361C-33 drop out voltage: ~170mV at: 500mA output current; Vout = 3.3V; 25°C
D7 LSM115J Schottky diode forward voltage: ~210mV at: 500mA; 25°C
AP7361C 3.3V output will start to fall when the battery voltage falls below 3.68V at 500mA
For a typical 2000mAh LiPo battery discharging at 500mA (0.25C), we would expect 3.68V to be reached when the battery is approximately 50% discharged. Typical: Typical current draw during Tx/Rx: 195mA at 23dBm

3.3V used for GNSS (ZED) 250mA
LBAND (NEO) 100mA WIFI/BT (NINA) 500mA USB HUB 100mA USB CDC 20mA

Total typical current draw: ~300mA
AP7361C-33 drop out voltage: ~100mV at: 300mA output current; Vout = 3.3V; 25°C
D7 LSM115J Schottky diode forward voltage: ~180mV at: 300mA; 25°C
AP7361C 3.3V output will start to fall when the battery voltage falls below 3.58V at 300mA

For a typical 2000mAH LiPo battery discharging at 300mA (0.15C), we would expect 3.58V to be reached when the battery is approximately 90% discharged. VIN: 3.7-6.0V
AP7361C-33FGE

IOUT(Max): 1.0A Close JP10 to enable
processor control of 3.3V bus.

LTE Cellular Modem
LARA-R6, LENA-R8 or SARA-R5
VCC_2

GND
If U1 equals SARA-R510S or LENA-R8001 then
L2, C34, E2, D12 : DNP

If U1 equals SARA-R510S then C16, C23 : DNP

R34 DIR1
SN74AVC4T774PW
I2C bus with the LTE modems I2C bus. A <= B : DIR = GND

Close JP11/12 to connect the main

Released under the Creative Commons Attribution Share-Alike 4.0 License

https://creativecommons.org/licenses/by-sa/4.0/ Design by:

09.05.22 21:11 f=0.60 /Users/michaelammann/Desktop/Eagle/HPG_Solution/HPG_Solution_v10/HPG_Solution.sch (Sheet: 2/2)

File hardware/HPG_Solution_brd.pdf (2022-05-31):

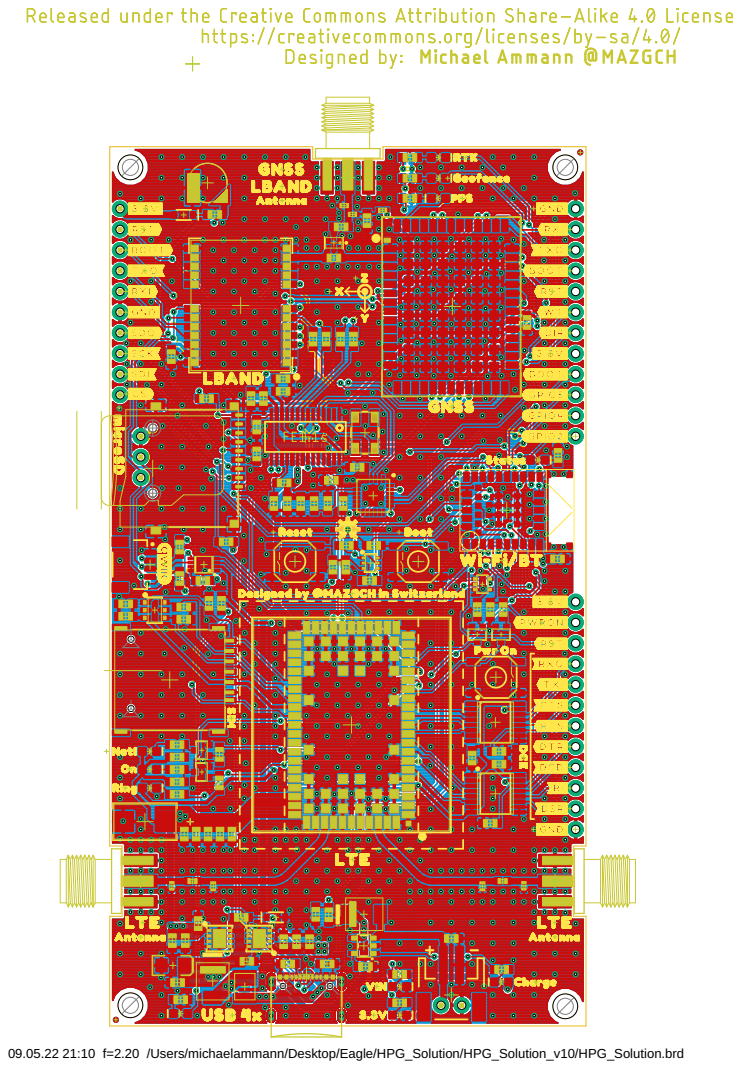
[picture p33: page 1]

09.05.22 21:10 f=2.20 /Users/michaelammann/Desktop/Eagle/HPG_Solution/HPG_Solution_v10/HPG_Solution.brd

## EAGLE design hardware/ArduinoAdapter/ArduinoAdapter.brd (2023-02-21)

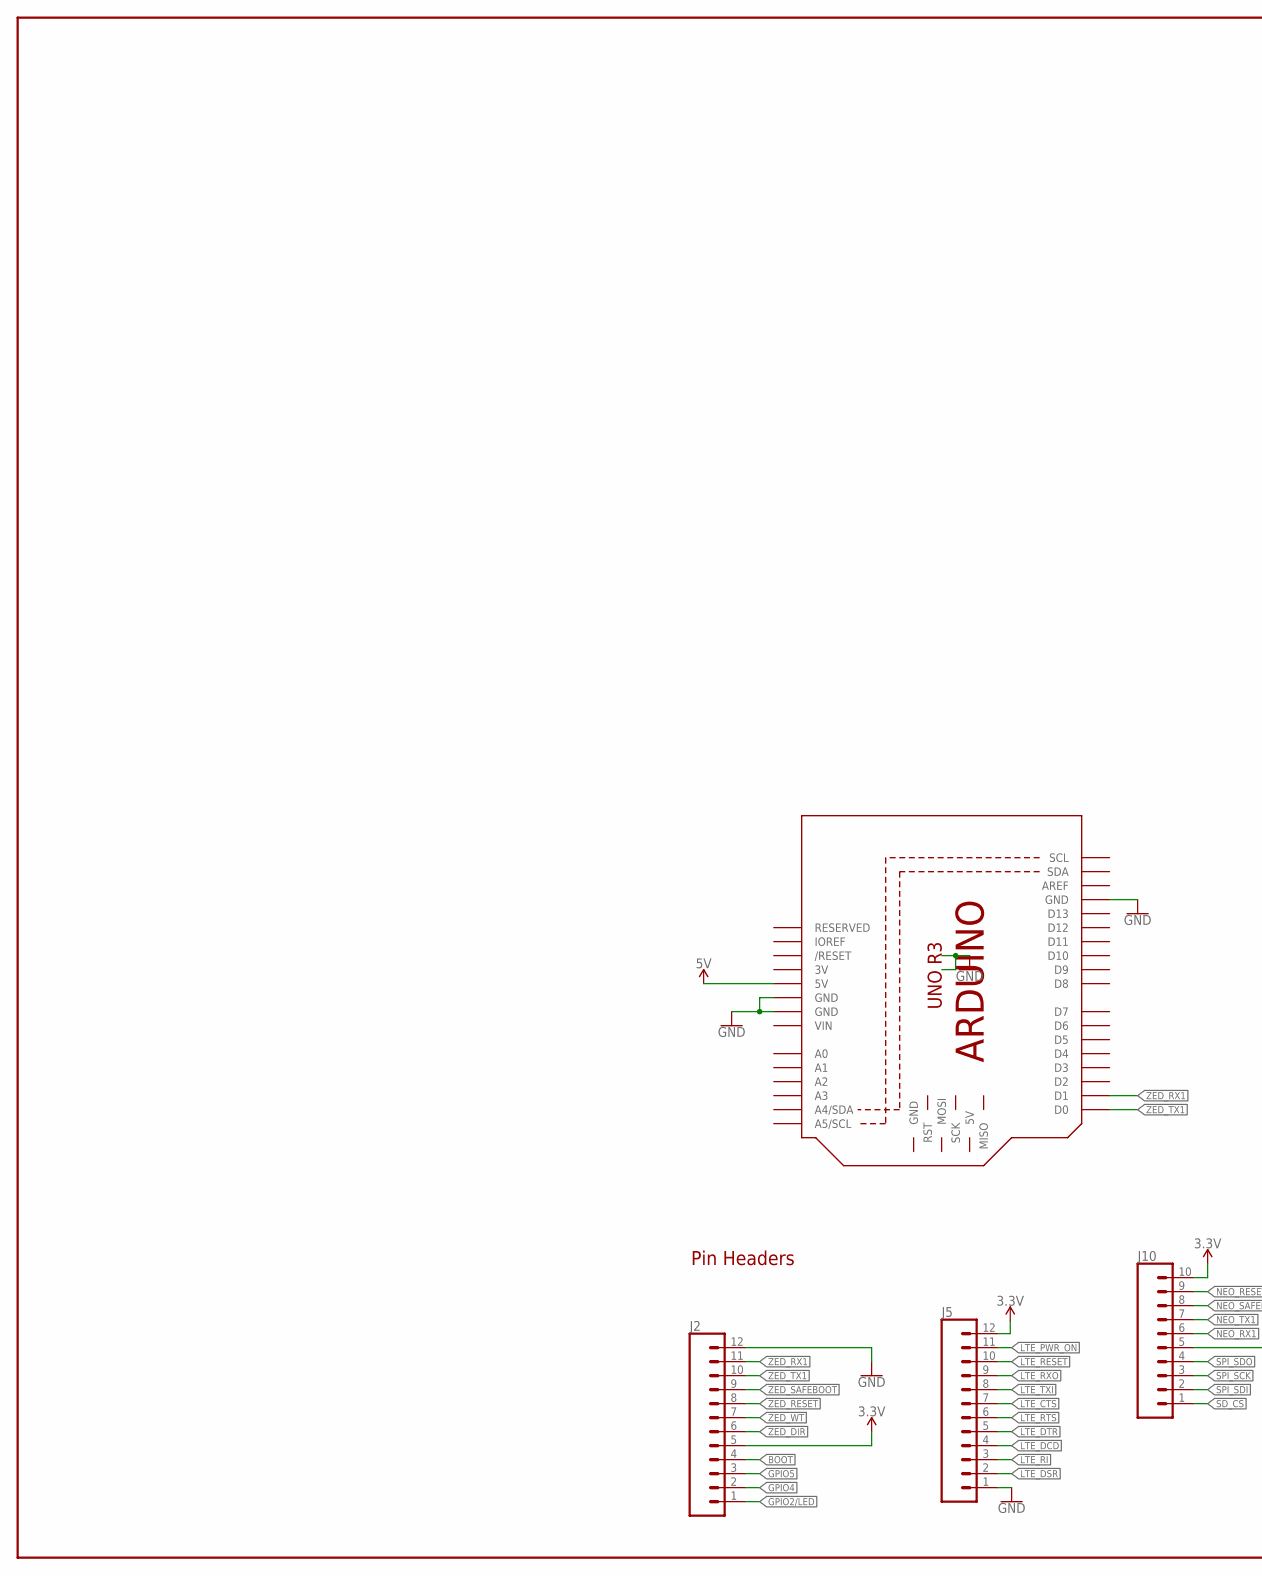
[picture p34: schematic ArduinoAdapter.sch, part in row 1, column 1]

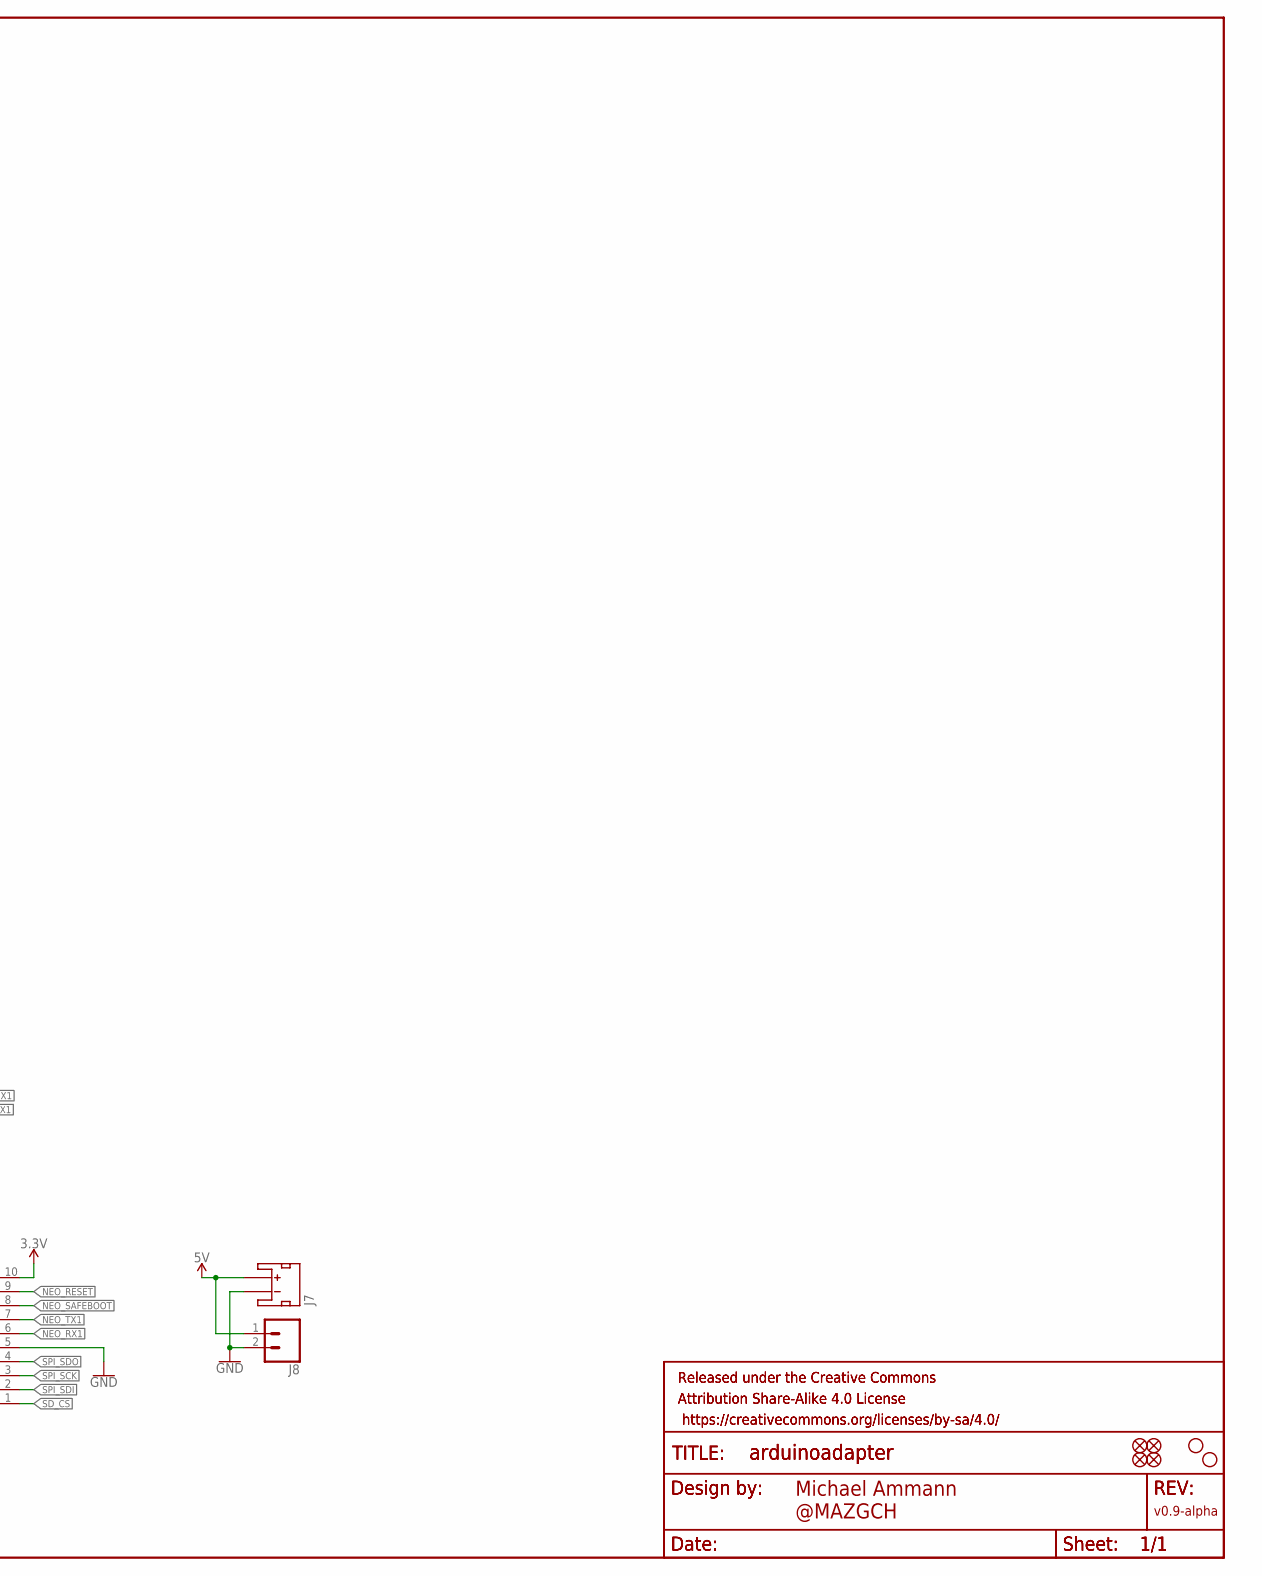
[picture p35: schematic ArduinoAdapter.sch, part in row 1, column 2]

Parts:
FD1, FD2, FD3, FD4: FIDUCIALUFIDUCIAL; FIDUCIAL-MICRO
FRAME1, FRAME2: FRAME-LEDGER; CREATIVE_COMMONS
H1, H4: STAND-OFFTIGHT; STAND-OFF-TIGHT
J2, J5: CONN_12NO_SILK; 1X12_NO_SILK
J7: JST_2MM_MALE; JST-2-SMD
J8: CONN_021X02_NO_SILK; 1X02_NO_SILK
J10: CONN_10NO_SILK_PTH_FEMALE; 1X10_NO_SILK
M1: ARDUINO_R3_ICSP; ARDUINOR3_ICSP

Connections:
3.3V: J2.5, J5.12, J10.10
3V: M1.3V
5V: J7.2 (+), J8.1, M1.5V
!BOOT!: J2.4
GND: J2.12, J5.1, J7.1 (-), J8.2, J10.5, M1.GND, M1.GND@1 (GND), M1.GND@3 (GND)
GPIO2/LED: J2.1
GPIO4: J2.2
GPIO5: J2.3
LTE_!RESET!: J5.10
LTE_CTS: J5.7
LTE_DCD: J5.4
LTE_DSR: J5.2
LTE_DTR: J5.5
LTE_PWR_ON: J5.11
LTE_RI: J5.3
LTE_RTS: J5.6
LTE_RXO: J5.9
LTE_TXI: J5.8
NEO_!RESET!: J10.9
NEO_!SAFEBOOT!: J10.8
NEO_RX1: J10.6
NEO_TX1: J10.7
SD_!CS!: J10.1
SPI_SCK: J10.3
SPI_SDI: J10.2
SPI_SDO: J10.4
VIN: M1.VIN
ZED_!RESET!: J2.8
ZED_!SAFEBOOT!: J2.9
ZED_DIR: J2.6
ZED_RX1: J2.11, M1.D1
ZED_TX1: J2.10, M1.D0
ZED_WT: J2.7

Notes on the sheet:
Pin Headers
Michael Ammann @MAZGCH
v0.9-alpha

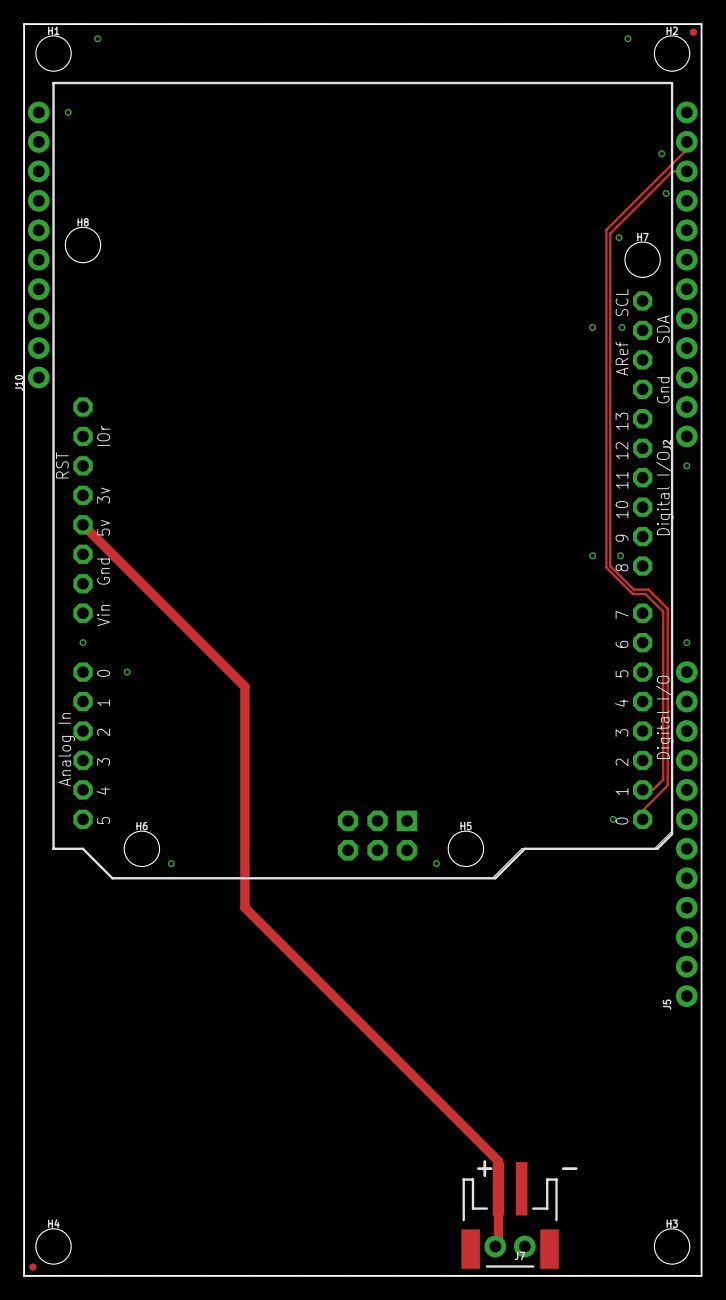
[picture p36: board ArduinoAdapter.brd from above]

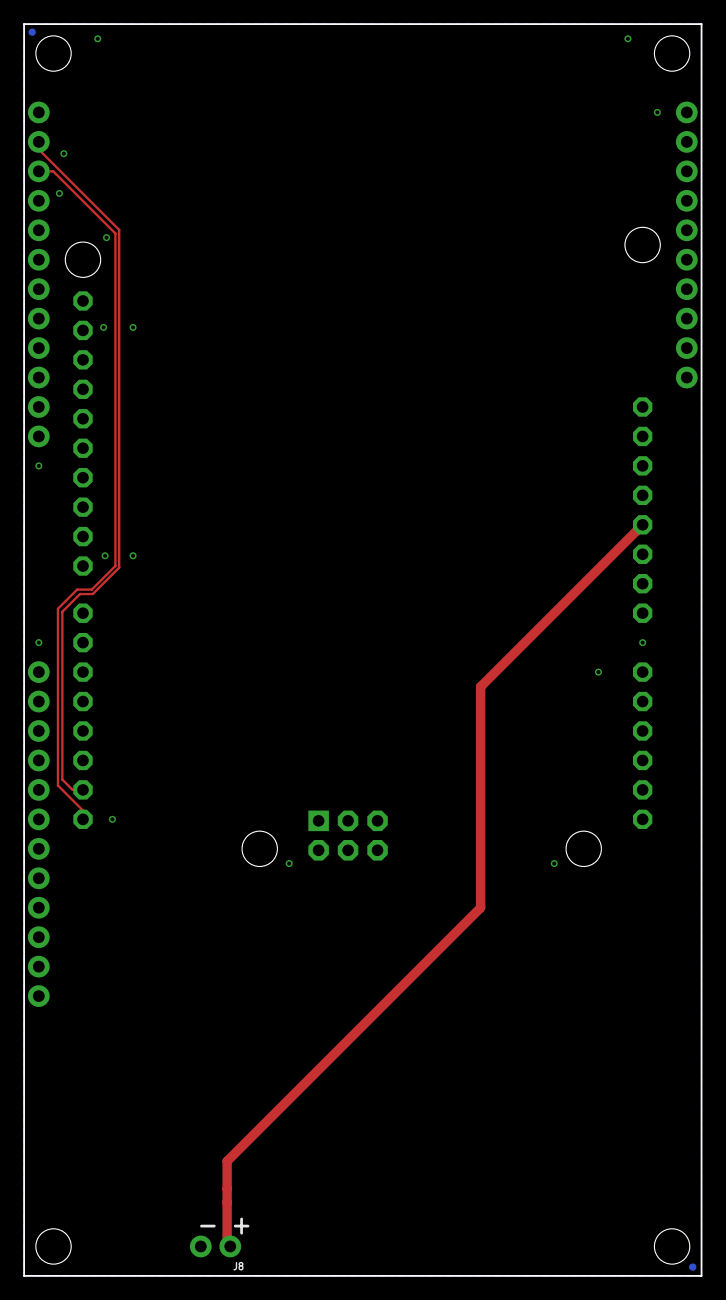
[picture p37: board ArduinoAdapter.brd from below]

Board: 2 copper layers, 58.4 x 108.0 mm, 20 parts (3 on the bottom side), 5 nets.

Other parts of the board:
H2, H3, H5, H6, H7, H8: STAND-OFFTIGHT; STAND-OFF-TIGHT

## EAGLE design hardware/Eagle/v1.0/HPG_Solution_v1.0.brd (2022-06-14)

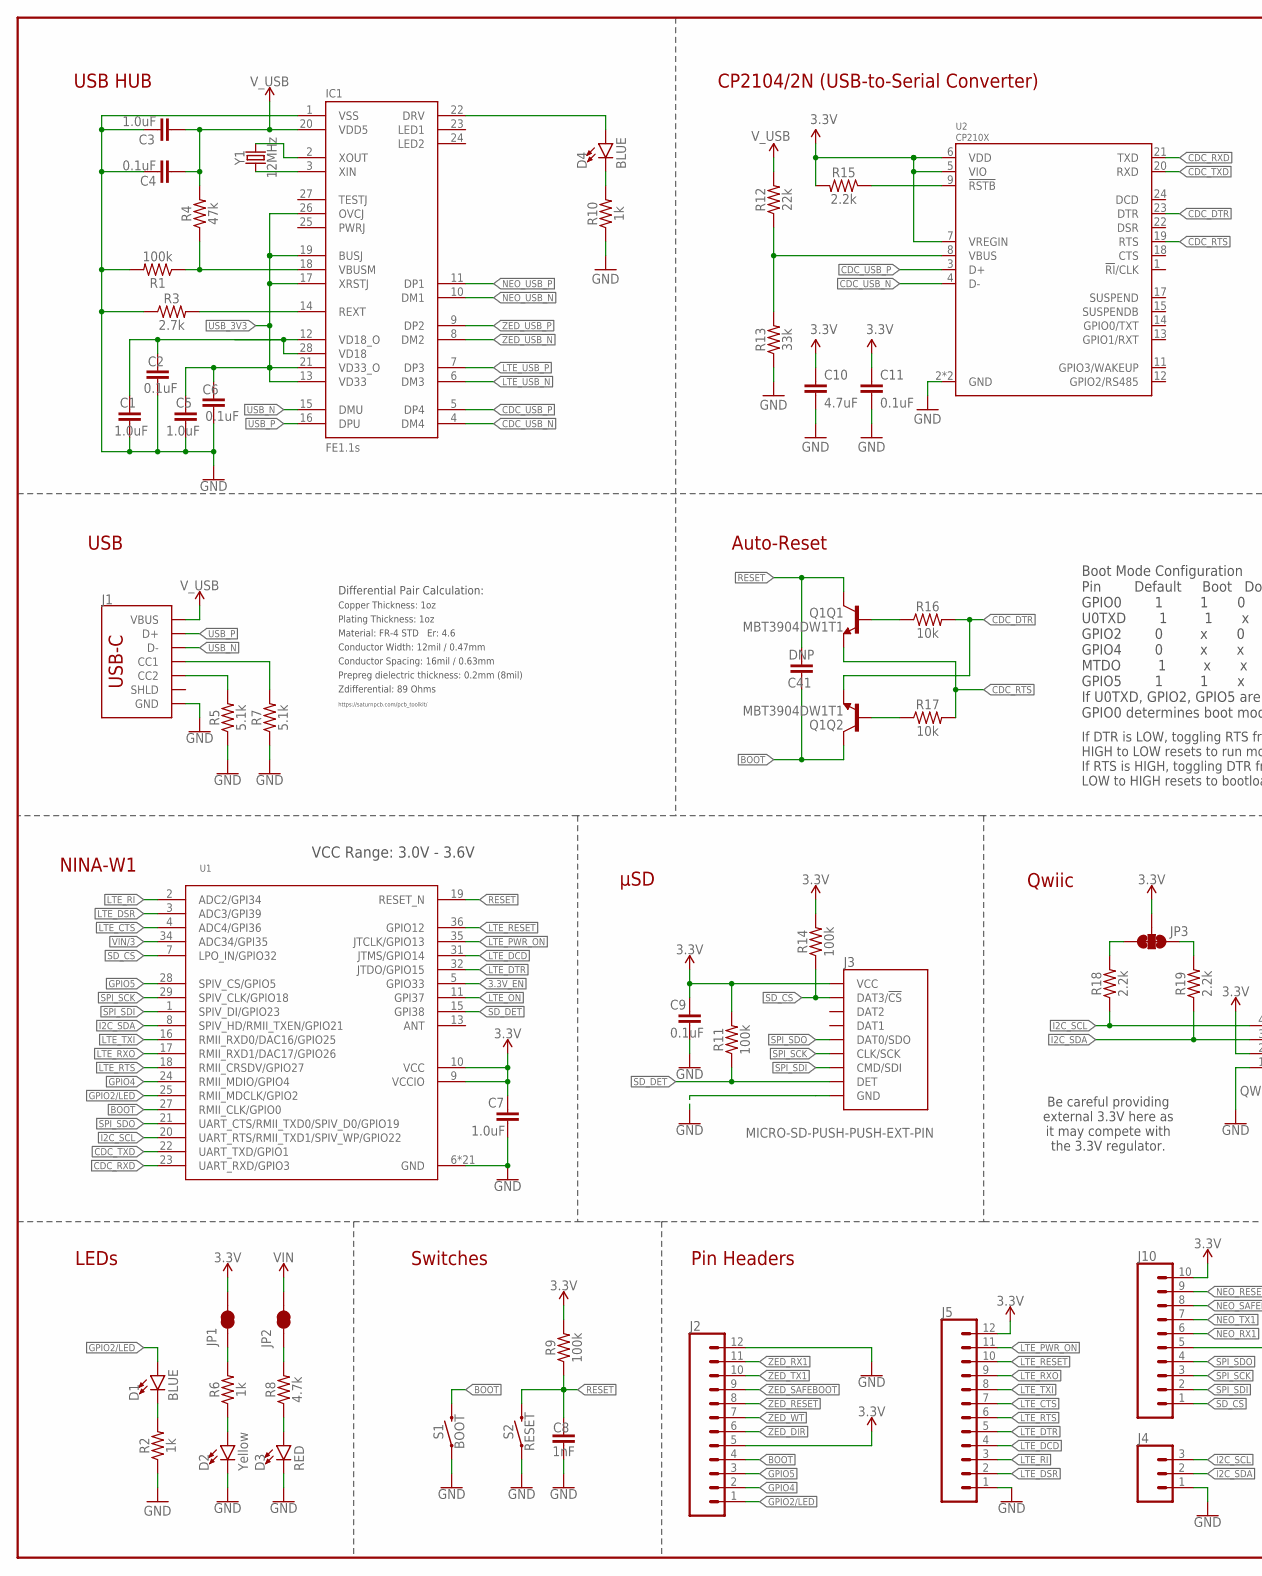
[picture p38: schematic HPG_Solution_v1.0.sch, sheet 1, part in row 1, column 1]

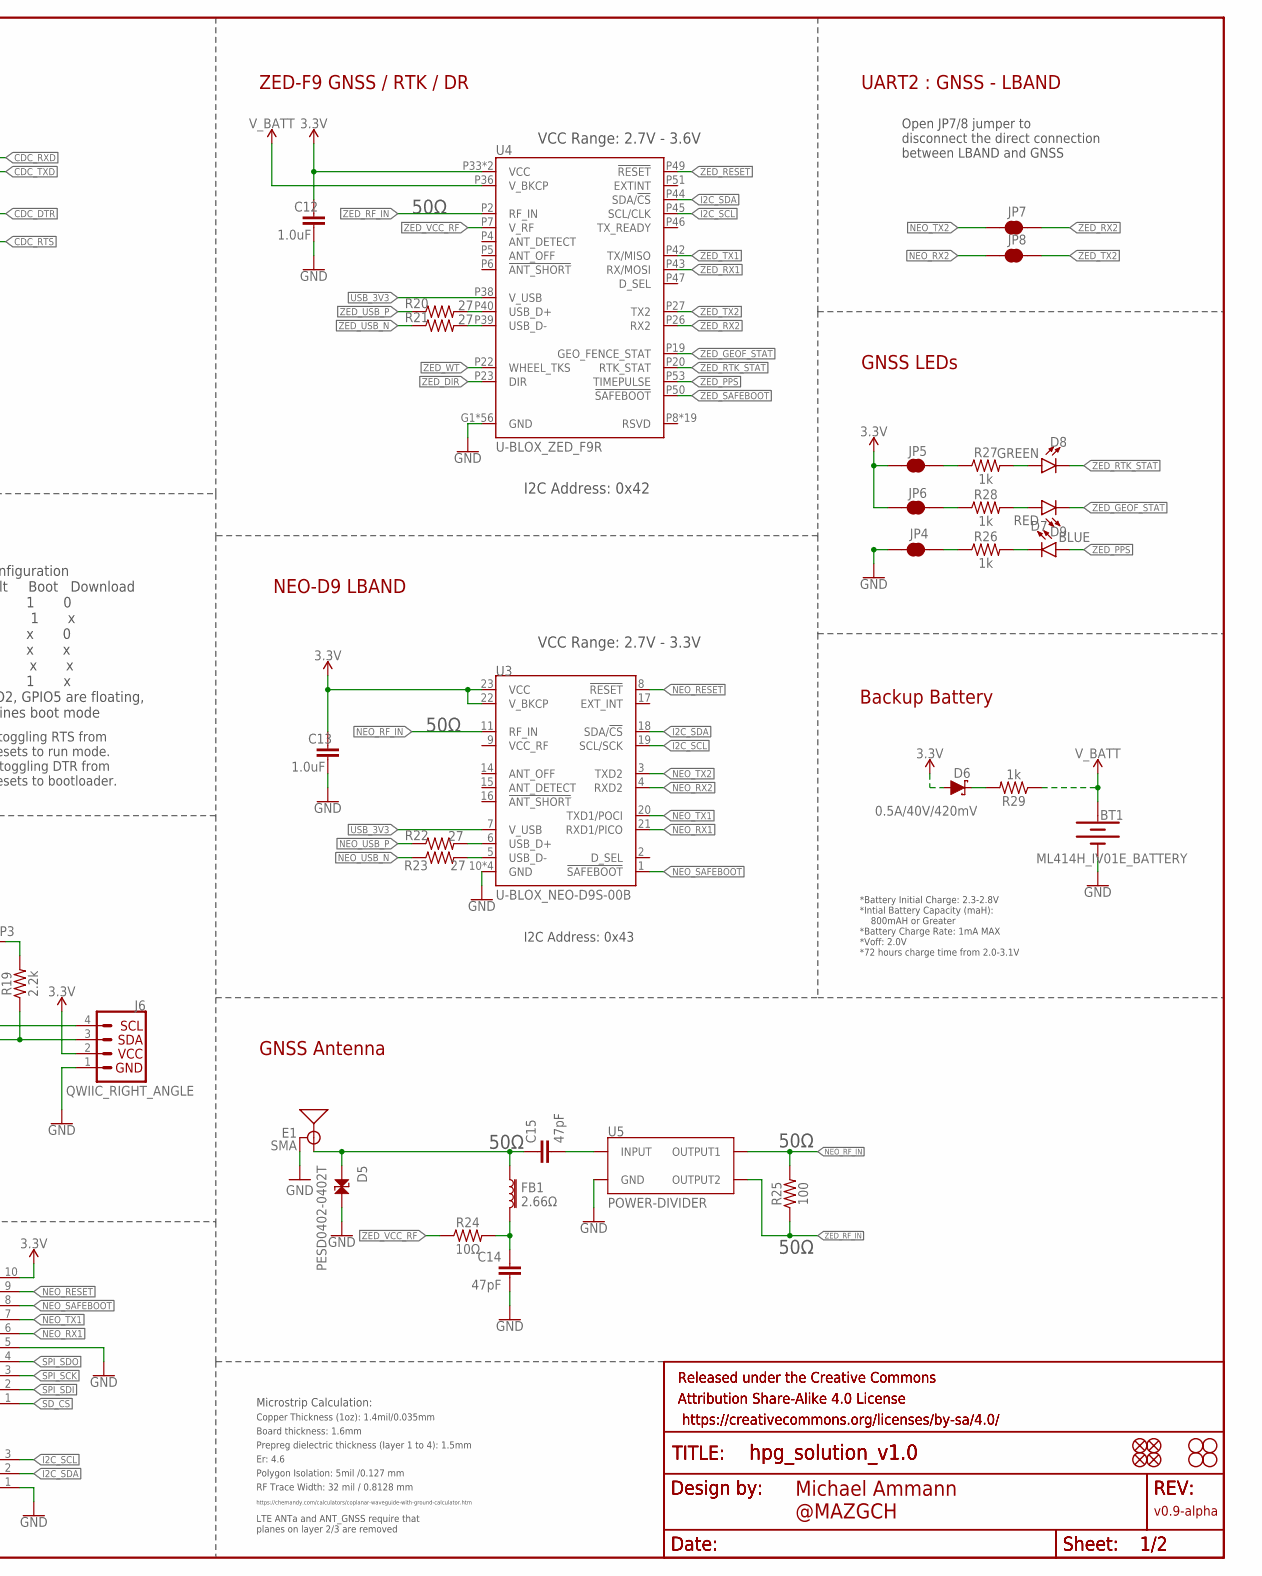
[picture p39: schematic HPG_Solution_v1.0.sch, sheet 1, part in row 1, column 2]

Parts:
BT1: ML414H_IV01E_BATTERY; ML414H_IV01E
C1, C3, C5, C7, C12, C13: 1.0uF; 0603
C2, C4, C6, C9, C11: 0.1uF; 0603
C8: 1nF; 0603
C10: 4.7uF; 0603
C14, C15: 47pF; 0603
C41: DNP; 0603
D1, D4, D7: BLUE; LED-0603
D2: Yellow; LED-0603
D3, D9: RED; LED-0603
D5: PESD0402-0402T; 0402-TIGHT
D6: 0.5A/40V/420mV; SOD-323
D8: GREEN; LED-0603
E1: SMA; SMA-EDGE
FB1: 2.66Ω; 0402-TIGHT
FD1, FD2, FD3, FD4: FIDUCIALUFIDUCIAL; FIDUCIAL-MICRO
FRAME1, FRAME2: FRAME-LEDGER; CREATIVE_COMMONS
H1, H2, H3, H4: STAND-OFFTIGHT; STAND-OFF-TIGHT
IC1: FE1.1S; FE1.1S_SSOP-28
J1: USB_C_4-LAYER_PADS; USB-C-16P_4LAYER-PADS
J2, J5: CONN_12NO_SILK; 1X12_NO_SILK
J3: MICRO-SD-PUSH-PUSH-EXT-PIN; MICROSD-EXTERNALPIN
J4: CONN_031X03_NO_SILK; 1X03_NO_SILK
J6: QWIIC_RIGHT_ANGLE; JST04_1MM_RA
J10: CONN_10NO_SILK_PTH_FEMALE; 1X10_NO_SILK
JP1, JP2, JP4, JP5, JP6, JP7, JP8: JUMPER-SMT_2_NC_TRACE_SILK; SMT-JUMPER_2_NC_TRACE_SILK
JP3: JUMPER-SMT_3_2-NC_TRACE_SILK; SMT-JUMPER_3_2-NC_TRACE_SILK
Q1: MBT3904DW1T1; SC70-6
R1, R9, R11, R14: 100k; 0603
R2, R6, R10, R26, R27, R28, R29: 1k; 0603
R3: 2.7k; 0603
R4: 47k; 0603
R5, R7: 5.1k; 0603
R8: 4.7k; 0603
R12: 22k; 0603
R13: 33k; 0603
R15, R18, R19: 2.2k; 0603
R16, R17: 10k; 0603
R20, R21, R22, R23: 27; 0603
R24: 10Ω; 0402-TIGHT
R25: 100; 0603
S1: BOOT; TACTILE_SWITCH_SMD_5.2MM
S2: RESET; TACTILE_SWITCH_SMD_5.2MM
U1: NINA-W106NINA-W106; NINA-W106
U2: CP210X; QFN24
U3: U-BLOX_NEO-D9S-00B; NEO-M9N/M8T/M8U/D9S
U4: U-BLOX_ZED_F9R; UBLOX_ZED_F9R
U5: POWER-DIVIDER; PD0922J5050S2HF_ANA
Y1: 12MHz; CRYSTAL-SMD-5X3.2-4PAD

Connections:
3.3V: C7.1, C9.1, C10.1, C11.1, C12.1, C13.1, D6.A, J2.5, J3.4 (VCC), J5.12, J6.2, J10.10, JP1.2, JP3.2, JP5.1, JP6.1, R9.2, R11.2, R14.2, R15.2, U1.9 (VCCIO), U1.10 (VCC), U2.5 (VIO), U2.6 (VDD), U2.7 (VREGIN), U3.22 (V_BKCP), U3.23 (VCC), U4.P33 (VCC), U4.P34 (VCC); also elsewhere on the board
3.3V_EN: U1.5 (GPIO33); also elsewhere on the board
!BOOT!: C41.1, J2.4, Q1.6 (C), S1.3 (2), S1.4 (2), U1.27 (RMII_CLK/GPIO0)
!RESET!: C8.1, C41.2, Q1.3 (C), R9.1, S2.3 (2), S2.4 (2), U1.19 (RESET_N)
CDC_DTR: Q1.1 (E), R16.2, U2.23 (DTR)
CDC_RTS: Q1.4 (E), R17.2, U2.19 (RTS)
CDC_RXD: U1.23 (UART_RXD/GPIO3), U2.21 (TXD)
CDC_TXD: U1.22 (UART_TXD/GPIO1), U2.20 (RXD)
CDC_USB_N: IC1.4 (DM4), U2.4 (D-)
CDC_USB_P: IC1.5 (DP4), U2.3 (D+)
GND: BT1.-, C1.2, C2.2, C3.1, C4.1, C5.2, C6.2, C7.2, C8.2, C9.2, C10.2, C11.2, C12.2, C13.2, C14.2, D2.C, D3.C, D5.2, E1.GND@0 (GND), E1.GND@1 (GND), E1.GND@2 (GND), E1.GND@3 (GND), IC1.1 (VSS), J1.GND, J1.GND2 (GND), J2.12, J3.6 (GND), J3.10 (GND), J3.11 (GND), J3.12 (GND), J3.13 (GND), J4.1, J5.1, J6.1, J10.5, JP4.1, R1.2, R2.1, R3.1, R5.1, R7.1, R10.1, R13.1, S1.1, S1.2 (1), S2.1, S2.2 (1), U1.6 (GND), U1.12 (GND), U1.14 (GND), U1.26 (GND), U1.30 (GND), U1.GND@1 (GND), U1.GND@2 (GND), U1.GND@3 (GND), U1.GND@4 (GND), U1.GND@5 (GND), U1.GND@6 (GND), U1.GND@7 (GND), U1.GND@8 (GND), U1.GND@9 (GND), U1.GND@10 (GND), U1.GND@11 (GND), U1.GND@12 (GND), U1.GND@13 (GND), U1.GND@14 (GND), U1.GND@15 (GND), U1.GND@16 (GND), U2.2 (GND), U2.PAD (GND), U3.10 (GND), U3.12 (GND), U3.13 (GND), U3.24 (GND), U4.G1 (GND), U4.G2 (GND), U4.G3 (GND), U4.G4 (GND), U4.G5 (GND), U4.G6 (GND), U4.G7 (GND), U4.G8 (GND), U4.G9 (GND), U4.G10 (GND), U4.G11 (GND), U4.G12 (GND), U4.G13 (GND), U4.G14 (GND), U4.G15 (GND), U4.G16 (GND), U4.G17 (GND), U4.G18 (GND), U4.G19 (GND), U4.G20 (GND), U4.G21 (GND), U4.G22 (GND), U4.G23 (GND), U4.G24 (GND), U4.G25 (GND), U4.G26 (GND), U4.G27 (GND), U4.G28 (GND), U4.G29 (GND), U4.G30 (GND), U4.G31 (GND), U4.G32 (GND), U4.G33 (GND), U4.G34 (GND), U4.G35 (GND), U4.G36 (GND), U4.G37 (GND), U4.G38 (GND), U4.G39 (GND), U4.G40 (GND), U4.G41 (GND), U4.G42 (GND), U4.G43 (GND), U4.G44 (GND), U4.G45 (GND), U4.G46 (GND), U4.G47 (GND), U4.G48 (GND), U4.P1 (GND), U4.P3 (GND), U4.P12 (GND), U4.P14 (GND), U4.P32 (GND), U4.P37 (GND), U4.P41 (GND), U4.P48 (GND), U5.1 (GND), U5.3 (GND), U5.5 (GND); also elsewhere on the board
GPIO2/LED: D1.A, J2.1, U1.25 (RMII_MDCLK/GPIO2)
GPIO4: J2.2, U1.24 (RMII_MDIO/GPIO4)
GPIO5: J2.3, U1.28 (SPIV_CS/GPIO5)
I2C_SCL: J4.3, J6.4, R18.1, U1.20 (UART_RTS/RMII_TXD1/SPIV_WP/GPIO22), U3.19 (SCL/SCK), U4.P45 (SCL/CLK); also elsewhere on the board
I2C_SDA: J4.2, J6.3, R19.1, U1.8 (SPIV_HD/RMII_TXEN/GPIO21), U3.18 (SDA/!CS!), U4.P44 (SDA/!CS!); also elsewhere on the board
LED1: D4.A, IC1.22 (DRV)
LTE_!ON!: U1.11 (GPI37); also elsewhere on the board
LTE_!RESET!: J5.10, U1.36 (GPIO12); also elsewhere on the board
LTE_CTS: J5.7, U1.4 (ADC4/GPI36); also elsewhere on the board
LTE_DCD: J5.4, U1.31 (JTMS/GPIO14); also elsewhere on the board
LTE_DSR: J5.2, U1.3 (ADC3/GPI39); also elsewhere on the board
LTE_DTR: J5.5, U1.32 (JTDO/GPIO15); also elsewhere on the board
LTE_PWR_ON: J5.11, U1.35 (JTCLK/GPIO13); also elsewhere on the board
LTE_RI: J5.3, U1.2 (ADC2/GPI34); also elsewhere on the board
LTE_RTS: J5.6, U1.18 (RMII_CRSDV/GPIO27); also elsewhere on the board
LTE_RXO: J5.9, U1.17 (RMII_RXD1/DAC17/GPIO26); also elsewhere on the board
LTE_TXI: J5.8, U1.16 (RMII_RXD0/DAC16/GPIO25); also elsewhere on the board
LTE_USB_N: IC1.6 (DM3); also elsewhere on the board
LTE_USB_P: IC1.7 (DP3); also elsewhere on the board
unnamed: JP2.1, R8.2
unnamed: R22.2, U3.6 (USB_D+)
unnamed: R23.2, U3.5 (USB_D-)
unnamed: JP1.1, R6.2
unnamed: D2.A, R6.1
unnamed: D3.A, R8.1
unnamed: JP3.3, R18.2
unnamed: J1.A5 (CC1), R7.2
unnamed: J1.B5 (CC2), R5.2
unnamed: D8.A, R27.2
unnamed: JP3.1, R19.2
unnamed: C15.2, U5.2 (INPUT)
unnamed: JP5.2, R27.1
unnamed: JP4.2, R26.1
unnamed: Q1.5 (B), R16.1
unnamed: Q1.2 (B), R17.1
unnamed: D1.C, R2.2
unnamed: D7.C, R26.2
unnamed: D9.A, R28.2
unnamed: C14.1, FB1.2, R24.2
unnamed: JP6.2, R28.1
unnamed: R12.1, R13.2, U2.8 (VBUS)
unnamed: D6.C, R29.2
unnamed: R21.2, U4.P39 (USB_D-)
unnamed: R15.1, U2.9 (!RSTB)
unnamed: R20.2, U4.P40 (USB_D+)
unnamed: C1.1, C2.1, IC1.12 (VD18_O), IC1.28 (VD18)
unnamed: IC1.14 (REXT), R3.2
unnamed: IC1.2 (XOUT), Y1.3 (2)
unnamed: IC1.3 (XIN), Y1.1
unnamed: D4.C, R10.2
unnamed: IC1.18 (VBUSM), R1.1, R4.1
NEO_!RESET!: J10.9, U3.8 (!RESET!)
NEO_!SAFEBOOT!: J10.8, U3.1 (!SAFEBOOT!)
NEO_RF_IN: R25.2, U3.11 (RF_IN), U5.4 (OUTPUT1)
NEO_RX1: J10.6, U3.21 (RXD1/PICO)
NEO_RX2: JP8.1, U3.4 (RXD2)
NEO_TX1: J10.7, U3.20 (TXD1/POCI)
NEO_TX2: JP7.1, U3.3 (TXD2)
NEO_USB_N: IC1.10 (DM1), R23.1
NEO_USB_P: IC1.11 (DP1), R22.1
RF_IN: C15.1, D5.1, E1.SIG (SIGNAL), FB1.1
SD_!CS!: J3.2 (DAT3/!CS!), J10.1, R14.1, U1.7 (LPO_IN/GPIO32)
SD_DET: J3.9 (DET), R11.1, U1.15 (GPI38)
SPI_SCK: J3.5 (CLK/SCK), J10.3, U1.29 (SPIV_CLK/GPIO18)
SPI_SDI: J3.3 (CMD/SDI), J10.2, U1.1 (SPIV_DI/GPIO23)
SPI_SDO: J3.7 (DAT0/SDO), J10.4, U1.21 (UART_CTS/RMII_TXD0/SPIV_D0/GPIO19)
USB_3V3: C5.1, C6.1, IC1.13 (VD33), IC1.17 (XRSTJ), IC1.19 (BUSJ), IC1.21 (VD33_O), IC1.26 (OVCJ), U3.7 (V_USB), U4.P38 (V_USB)
USB_N: IC1.15 (DMU), J1.A7 (D-), J1.B7 (D-)
USB_P: IC1.16 (DPU), J1.A6 (D+), J1.B6 (D+)
VIN: JP2.2; also elsewhere on the board
VIN/3: U1.34 (ADC34/GPI35); also elsewhere on the board
V_BATT: BT1.+, R29.1, U4.P36 (V_BKCP)
V_USB: C3.2, C4.2, IC1.20 (VDD5), J1.VBUS1 (VBUS), J1.VBUS2 (VBUS), R4.2, R12.2; also elsewhere on the board
ZED_!RESET!: J2.8, U4.P49 (!RESET!)
ZED_!SAFEBOOT!: J2.9, U4.P50 (!SAFEBOOT!)
ZED_DIR: J2.6, U4.P23 (DIR)
ZED_GEOF_STAT: D9.C, U4.P19 (GEO_FENCE_STAT)
ZED_PPS: D7.A, U4.P53 (TIMEPULSE)
ZED_RF_IN: R25.1, U4.P2 (RF_IN), U5.6 (OUTPUT2)
ZED_RTK_STAT: D8.C, U4.P20 (RTK_STAT)
ZED_RX1: J2.11, U4.P43 (RX/MOSI)
ZED_RX2: JP7.2, U4.P26 (RX2)
ZED_TX1: J2.10, U4.P42 (TX/MISO)
ZED_TX2: JP8.2, U4.P27 (TX2)
ZED_USB_N: IC1.8 (DM2), R21.1
ZED_USB_P: IC1.9 (DP2), R20.1
ZED_VCC_RF: R24.1, U4.P7 (V_RF)
ZED_WT: J2.7, U4.P22 (WHEEL_TKS)

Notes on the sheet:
μSD
USB HUB
Pin Headers
Be careful providing external 3.3V here as it may compete with the 3.3V regulator.
Qwiic
LEDs
Switches
Plating Thickness: 1oz
Material: FR-4 STD Er: 4.6
Copper Thickness: 1oz
Conductor Spacing: 16mil / 0.63mm
Conductor Width: 12mil / 0.47mm
Prepreg dielectric thickness: 0.2mm (8mil)
https://saturnpcb.com/pcb_toolkit/
Differential Pair Calculation:
Zdifferential: 89 Ohms
Boot Mode Configuration Pin Default Boot Download GPIO0 1 1 0 U0TXD 1 1 x GPIO2 0 x 0 GPIO4 0 x x MTDO 1 x x GPIO5 1 1 x If U0TXD, GPIO2, GPIO5 are floating, GPIO0 determines boot mode
Auto-Reset
If DTR is LOW, toggling RTS from HIGH to LOW resets to run mode. If RTS is HIGH, toggling DTR from LOW to HIGH resets to bootloader.
CP2104/2N (USB-to-Serial Converter)
Backup Battery
*Battery Initial Charge: 2.3-2.8V *Intial Battery Capacity (maH): 800mAH or Greater *Battery Charge Rate: 1mA MAX *Voff: 2.0V *72 hours charge time from 2.0-3.1V
USB
NINA-W1
Michael Ammann @MAZGCH
I2C Address: 0x43
VCC Range: 2.7V - 3.3V
NEO-D9 LBAND
VCC Range: 2.7V - 3.6V
I2C Address: 0x42
ZED-F9 GNSS / RTK / DR
Open JP7/8 jumper to disconnect the direct connection between LBAND and GNSS
UART2 : GNSS - LBAND
Board thickness: 1.6mm
Er: 4.6
Copper Thickness (1oz): 1.4mil/0.035mm
RF Trace Width: 32 mil / 0.8128 mm
Polygon Isolation: 5mil /0.127 mm
Prepreg dielectric thickness (layer 1 to 4): 1.5mm
https://chemandy.com/calculators/coplanar-waveguide-with-ground-calculator.htm

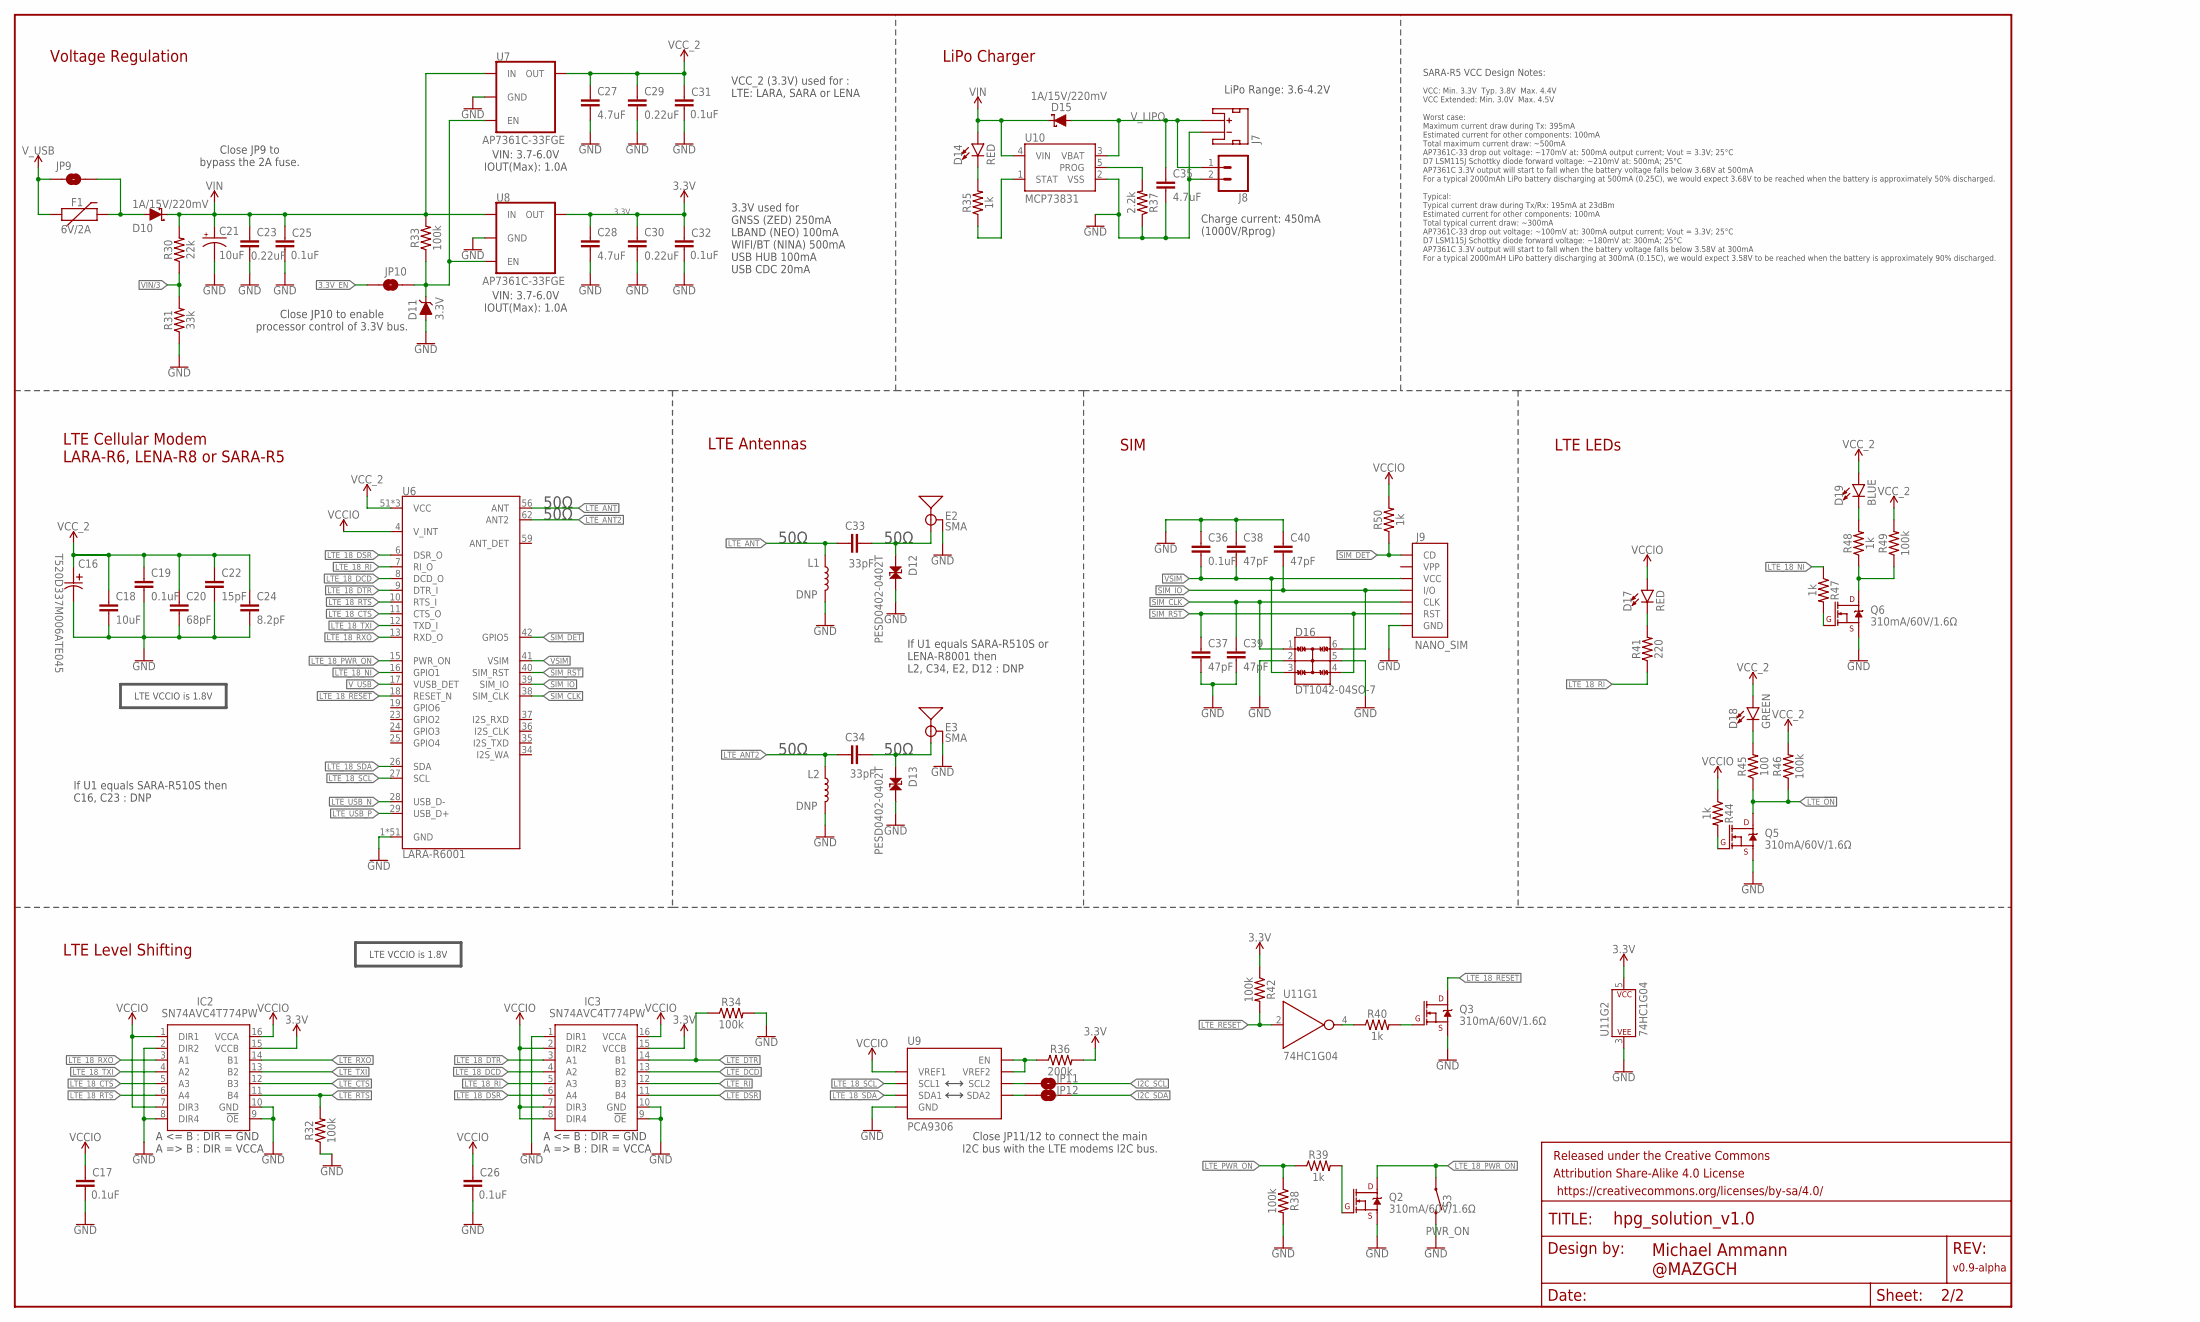
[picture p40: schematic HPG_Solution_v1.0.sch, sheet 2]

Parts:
C16: T520D337M006ATE045; CAPMP7.6X4.3_3.1N_KEM
C17, C19, C25, C26, C31, C32, C36: 0.1uF; 0603
C18: 10uF; 0603
C20: 68pF; 0603@1
C21: 10uF; EIA3216
C22: 15pF; 0603
C23, C29, C30: 0.22uF; 0603
C24: 8.2pF; 0603
C27, C28, C35: 4.7uF; 0603
C33, C34: 33pF; 0402
C37, C38, C39, C40: 47pF; 0603
D10, D15: 1A/15V/220mV; DO-214BA
D11: 3.3V; SOD-323
D12, D13: PESD0402-0402T; 0402-TIGHT
D14, D17: RED; LED-0603
D16: DT1042-04SO-7; SOT23-6L
D18: GREEN; LED-0603
D19: BLUE; LED-0603
E2, E3: SMA; SMA-EDGE
F1: 6V/2A; 1210
FRAME3: FRAME-LEDGER; CREATIVE_COMMONS
IC2, IC3: SN74AVC4T774PW; SOP65P640X120-16N
J7: JST_2MM_MALE; JST-2-SMD
J8: CONN_021X02_NO_SILK; 1X02_NO_SILK
J9: NANO_SIM; NANO_SIM_PP
JP9, JP10, JP11, JP12: JUMPER-SMT_2_NO_SILK; SMT-JUMPER_2_NO_SILK
L1, L2: DNP; 0402_COILCRAFT
Q2, Q3, Q5, Q6: 310mA/60V/1.6Ω; SOT323
R30: 22k; 0603
R31: 33k; 0603
R32, R33, R34, R38, R42, R46, R49: 100k; 0603
R35, R39, R40, R44, R47, R48, R50: 1k; 0603
R36: 200k; 0603
R37: 2.2k; 0603
R41: 220; 0603
R45: 100; 0603
S3: PWR_ON; TACTILE_SWITCH_SMD_5.2MM
U6: LARA-R6001; LARA-LGA
U7, U8: AP7361C-33FGE; UDFN-8
U9: PCA9306; VSSOP_8PIN
U10: MCP73831; SOT23-5
U11: 74HC1G04; SOT353

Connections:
3.3V: C28.1, C30.1, C32.1, IC2.15 (VCCB), IC3.15 (VCCB), R36.2, R42.1, U8.1 (OUT), U11.5 (P$V+); also elsewhere on the board
3.3V_EN: JP10.1; also elsewhere on the board
CHG_LED: R35.1, U10.1 (STAT)
GND: C16.2, C17.2, C18.2, C19.2, C20.2, C21.-, C22.2, C23.2, C24.2, C25.2, C26.2, C27.2, C28.2, C29.2, C30.2, C31.2, C32.2, C35.2, C36.1, C37.2, C38.1, C39.2, C40.1, D11.A, D12.2, D13.2, D16.2, D16.5, E2.GND@0 (GND), E2.GND@1 (GND), E2.GND@2 (GND), E2.GND@3 (GND), E3.GND@0 (GND), E3.GND@1 (GND), E3.GND@2 (GND), E3.GND@3 (GND), IC2.2 (DIR2), IC2.8 (DIR4), IC2.9 (!OE), IC2.10 (GND), IC3.1 (DIR1), IC3.9 (!OE), IC3.10 (GND), J7.1 (-), J8.2, J9.A1 (GND), J9.A2 (GND), J9.A3 (GND), J9.A4 (GND), J9.C5 (GND), L1.P$2 (2), L2.P$2 (2), Q2.2 (S), Q3.2 (S), Q5.2 (S), Q6.2 (S), R31.1, R32.1, R34.2, R37.1, R38.2, S3.3 (2), S3.4 (2), U6.1 (GND), U6.3 (GND), U6.5 (GND), U6.14 (GND), U6.20 (GND), U6.21 (GND), U6.22 (GND), U6.30 (GND), U6.32 (GND), U6.43 (GND), U6.50 (GND), U6.54 (GND), U6.55 (GND), U6.57 (GND), U6.58 (GND), U6.60 (GND), U6.61 (GND), U6.63 (GND), U6.64 (GND), U6.65 (GND), U6.66 (GND), U6.67 (GND), U6.68 (GND), U6.69 (GND), U6.70 (GND), U6.71 (GND), U6.72 (GND), U6.73 (GND), U6.74 (GND), U6.75 (GND), U6.76 (GND), U6.77 (GND), U6.78 (GND), U6.79 (GND), U6.80 (GND), U6.81 (GND), U6.82 (GND), U6.83 (GND), U6.84 (GND), U6.85 (GND), U6.86 (GND), U6.87 (GND), U6.88 (GND), U6.89 (GND), U6.90 (GND), U6.91 (GND), U6.92 (GND), U6.93 (GND), U6.94 (GND), U6.95 (GND), U6.96 (GND), U7.4 (GND), U7.EP (GND), U8.4 (GND), U8.EP (GND), U9.P1 (GND), U10.2 (VSS), U11.3 (P$V-); also elsewhere on the board
I2C_SCL: JP11.2; also elsewhere on the board
I2C_SDA: JP12.2; also elsewhere on the board
LTE_18_!RESET!: Q3.3 (D), U6.18 (RESET_N)
LTE_18_CTS: IC2.5 (A3), U6.11 (CTS_O)
LTE_18_DCD: IC3.4 (A2), U6.8 (DCD_O)
LTE_18_DSR: IC3.6 (A4), U6.6 (DSR_O)
LTE_18_DTR: IC3.3 (A1), U6.9 (DTR_I)
LTE_18_NI: R47.1, U6.16 (GPIO1)
LTE_18_PWR_ON: Q2.3 (D), S3.1, S3.2 (1), U6.15 (PWR_ON)
LTE_18_RI: IC3.5 (A3), R41.1, U6.7 (RI_O)
LTE_18_RTS: IC2.6 (A4), U6.10 (RTS_I)
LTE_18_RXO: IC2.3 (A1), U6.13 (RXD_O)
LTE_18_SCL: U6.27 (SCL), U9.P3 (SCL1)
LTE_18_SDA: U6.26 (SDA), U9.P4 (SDA1)
LTE_18_TXI: IC2.4 (A2), U6.12 (TXD_I)
LTE_!ON!: Q5.3 (D), R45.1, R46.1; also elsewhere on the board
LTE_!RESET!: R42.2, U11.2 (A); also elsewhere on the board
LTE_ANT: C33.1, L1.P$1 (1), U6.56 (ANT)
LTE_ANT2: C34.1, L2.P$1 (1), U6.62 (ANT2)
LTE_CTS: IC2.12 (B3); also elsewhere on the board
LTE_DCD: IC3.13 (B2); also elsewhere on the board
LTE_DSR: IC3.11 (B4); also elsewhere on the board
LTE_DTR: IC3.14 (B1), R34.1; also elsewhere on the board
LTE_PWR_ON: R38.1, R39.1; also elsewhere on the board
LTE_RI: IC3.12 (B3); also elsewhere on the board
LTE_RTS: IC2.11 (B4), R32.2; also elsewhere on the board
LTE_RXO: IC2.14 (B1); also elsewhere on the board
LTE_SCL: JP11.1, U9.P6 (SCL2)
LTE_SDA: JP12.1, U9.P5 (SDA2)
LTE_TXI: IC2.13 (B2); also elsewhere on the board
LTE_USB_N: U6.28 (USB_D-); also elsewhere on the board
LTE_USB_P: U6.29 (USB_D+); also elsewhere on the board
unnamed: C34.2, D13.1, E3.SIG (SIGNAL)
unnamed: D10.A, F1.2, JP9.2
unnamed: C33.2, D12.1, E2.SIG (SIGNAL)
unnamed: R37.2, U10.5 (PROG)
unnamed: D14.C, R35.2
unnamed: R36.1, U9.P7 (VREF2), U9.P8 (EN)
unnamed: Q2.1 (G), R39.2
unnamed: Q3.1 (G), R40.2
unnamed: R40.1, U11.4 (Y)
unnamed: D17.C, R41.2
unnamed: Q6.1 (G), R47.2
unnamed: Q6.3 (D), R48.1, R49.1
unnamed: D19.C, R48.2
unnamed: Q5.1 (G), R44.2
unnamed: D18.C, R45.2
unnamed: D11.C, JP10.2, R33.1, U7.5 (EN), U8.5 (EN)
SIM_CLK: C39.1, D16.1, J9.C3 (CLK), U6.38 (SIM_CLK)
SIM_DET: J9.CD, R50.1, U6.42 (GPIO5)
SIM_IO: C40.2, D16.6, J9.C7 (I/O), U6.39 (SIM_IO)
SIM_RST: C37.1, D16.4, J9.C2 (RST), U6.40 (SIM_RST)
VCCIO: C17.1, C26.1, D17.A, IC2.1 (DIR1), IC2.7 (DIR3), IC2.16 (VCCA), IC3.2 (DIR2), IC3.7 (DIR3), IC3.8 (DIR4), IC3.16 (VCCA), R44.1, R50.2, U6.4 (V_INT), U9.P2 (VREF1)
VCC_2: C16.1, C18.1, C19.1, C20.1, C22.1, C24.1, C27.1, C29.1, C31.1, D18.A, D19.A, R46.2, R49.2, U6.51 (VCC), U6.52 (VCC), U6.53 (VCC), U7.1 (OUT)
VIN: C21.+, C23.1, C25.1, D10.C, D14.A, D15.C, R30.2, R33.2, U7.8 (IN), U8.8 (IN), U10.4 (VIN); also elsewhere on the board
VIN/3: R30.1, R31.2; also elsewhere on the board
VSIM: C36.2, C38.2, D16.3, J9.C1 (VCC), U6.41 (VSIM)
V_LIPO: C35.1, D15.A, J7.2 (+), J8.1, U10.3 (VBAT)
V_USB: F1.1, JP9.1, U6.17 (VUSB_DET); also elsewhere on the board

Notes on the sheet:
SARA-R5 VCC Design Notes:
VCC: Min. 3.3V Typ. 3.8V Max. 4.4V VCC Extended: Min. 3.0V Max. 4.5V Worst case: Maximum current draw during Tx: 395mA Estimated current for other components: 100mA Total maximum current draw: ~500mA AP7361C-33 drop out voltage: ~170mV at: 500mA output current; Vout = 3.3V; 25°C D7 LSM115J Schottky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
Michael Ammann @MAZGCH
Voltage Regulation
VIN: 3.7-6.0V IOUT(Max): 1.0A
Close JP10 to enable processor control of 3.3V bus.
LiPo Charger
LiPo Range: 3.6-4.2V
Charge current: 450mA (1000V/Rprog)
VCC_2 (3.3V) used for : LTE: LARA, SARA or LENA
3.3V used for GNSS (ZED) 250mA LBAND (NEO) 100mA WIFI/BT (NINA) 500mA USB HUB 100mA USB CDC 20mA
Close JP9 to bypass the 2A fuse.
LTE Cellular Modem LARA-R6, LENA-R8 or SARA-R5
SIM
50Ω
LTE VCCIO is 1.8V
If U1 equals SARA-R510S then C16, C23 : DNP
LTE Antennas
If U1 equals SARA-R510S or LENA-R8001 then L2, C34, E2, D12 : DNP
LTE LEDs
LTE Level Shifting
Close JP11/12 to connect the main I2C bus with the LTE modems I2C bus.
v0.9-alpha

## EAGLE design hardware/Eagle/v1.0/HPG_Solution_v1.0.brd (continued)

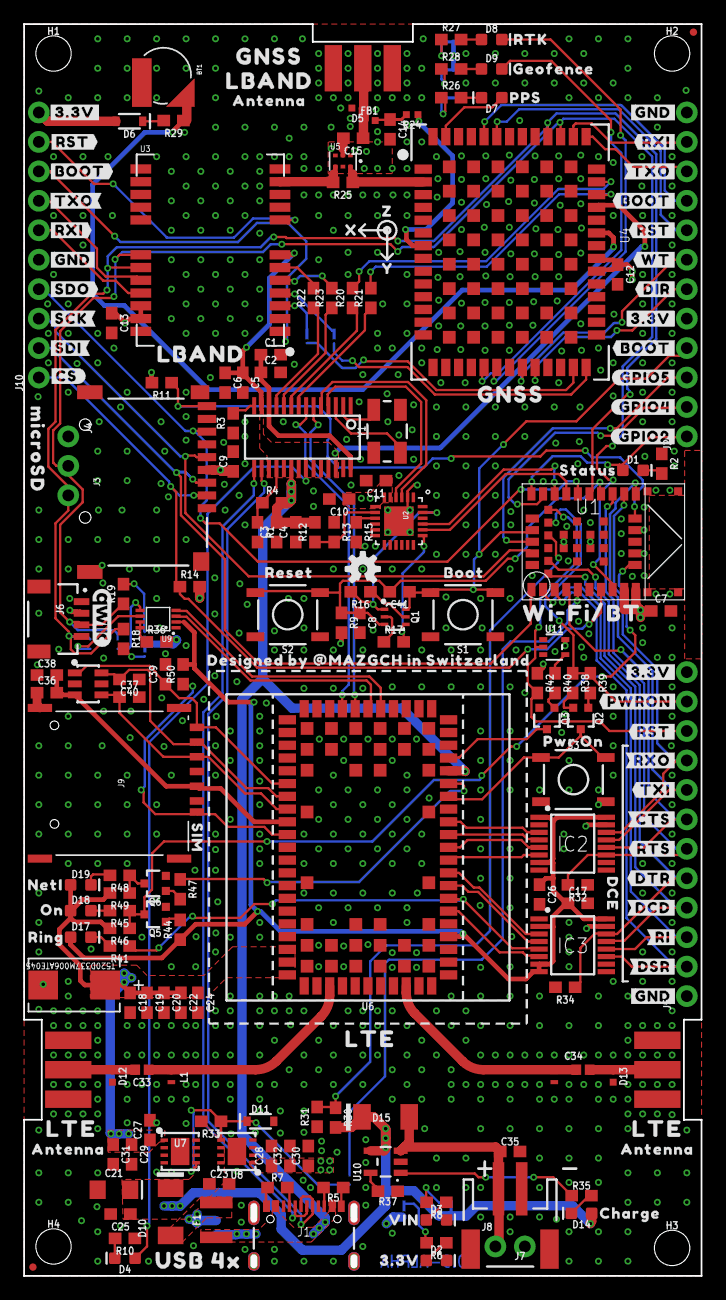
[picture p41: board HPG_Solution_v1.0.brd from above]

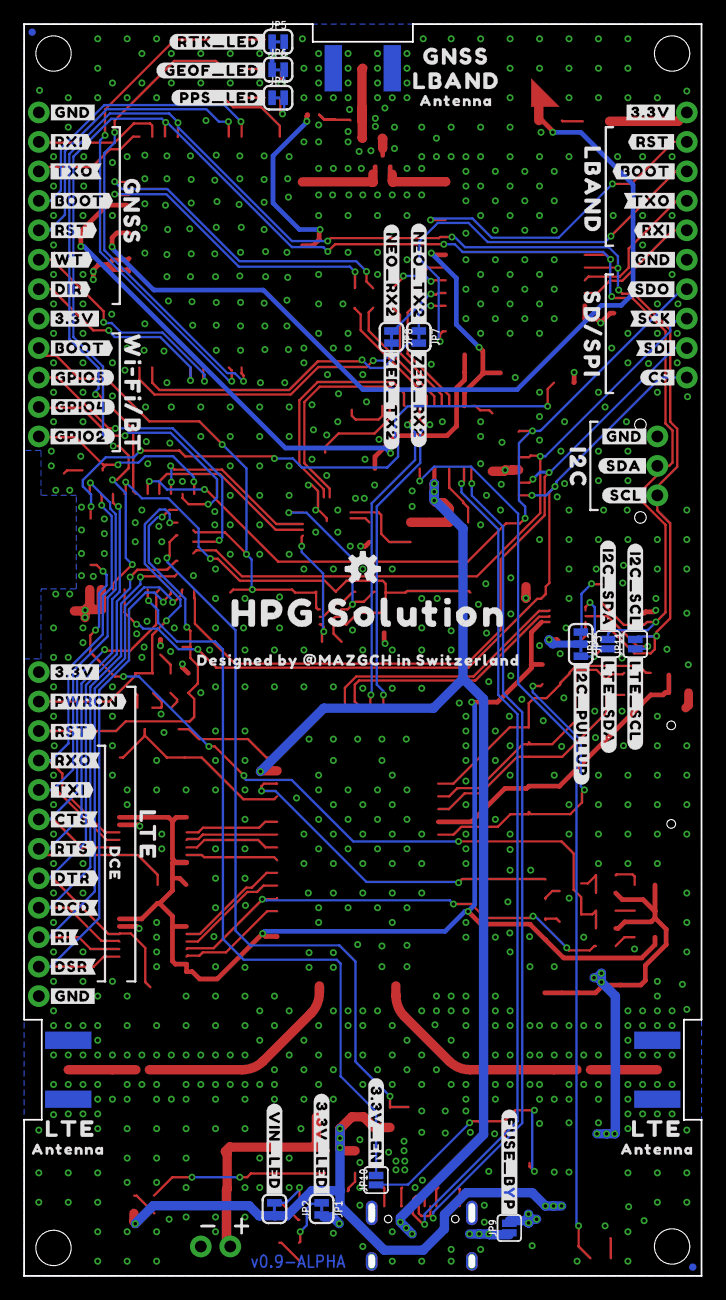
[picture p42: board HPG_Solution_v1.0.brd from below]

Board: 4 copper layers, 58.4 x 108.0 mm, 311 parts (84 on the bottom side), 141 nets.

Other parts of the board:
U$1, U$122: OSHW-LOGO-S
U$2: QWIIC_5MM
U$3: MICROSD0
U$4, U$5, U$19, U$44, U$45, U$118: LTE0
U$6, U$20, U$46, U$116: GNSS0
U$7: #PWRON#1
U$8, U$9, U$10, U$37, U$40, U$43, U$138: #GND#0
U$11, U$12, U$13, U$36, U$39, U$41: #3#3V#0
U$14, U$126, U$127: #RST#2
U$15: RESET6
U$16: BOOT5
U$17: PWR_ON0
U$18, U$22, U$35: #RST#3
U$21: CHARGE0
U$23: #RTK_LED#0
U$24: #3#3V_LED#0
U$25: 3#3V3
U$26: RTK16
U$27: #I2C_SCL#2
U$28: PPS14
U$29: #I2C_PULLUP#3
U$30, U$59: #RXI#1
U$31: ON0
U$32, U$33: #TXO#5
U$34: #CS#4
U$38, U$60: #RXI#0
U$42: #GEOF_LED#1
U$47: X1
U$48: Y2
U$49: #I2C_SDA#1
U$50: HPG_SOLUTION0
U$51: SIM0
U$52: Z0
U$53, U$75, U$76: #BOOT#1
U$54: VIN3
U$55: I2C0
U$56: #PWRON#0
U$57, U$72, U$74: #BOOT#0
U$58, U$61: #TXO#3
U$62: #PPS_LED#2
U$63: #GPIO4#1
U$64: #GPIO2#2
U$65: #GPIO2#8
U$66: #DIR#13
U$67: #WT#11
U$68: #WT#10
U$69: #DIR#12
U$70: #GPIO4#7
U$71: #GPIO5#6
U$73, U$114: DCE0
U$77, U$78, U$82, U$117: LBAND2
U$79: USB_4X3
U$80: RING0
U$81: STATUS7
U$83: #LTE_SCL#7
U$84, U$85, U$86, U$87, U$88, U$89: ANTENNA2
U$90, U$119: WI#FI#BT3
U$91: #3#3V_EN#1
U$92: #CTS#5
U$93: #DCD#4
U$94: #FUSE_BYP#2
U$95: #DSR#3
U$96: #DTR#7
U$97: #RI#6
U$98: #RXO#2
U$99: #RTS#8
U$100: #TXI#1
U$101: #RXO#3
U$102: #TXI#2
U$103: #CTS#6
U$104: #RTS#9
U$105: #DTR#8
U$106: #DCD#5
U$107: #RI#7
U$108: #DSR#4
U$109: #SCK#0
U$110: #NEO_RX2#0
U$111: #NEO_TX2#2
U$112: #ZED_RX2#3
U$113: #ZED_TX2#1
U$115: #GPIO5#0
U$120, U$121: DESIGNED_BY_#MAZGCH_IN_SWITZERLAND3
U$123: #LTE_SDA#5
U$124: #SCK#4
U$125: GEOFENCE5
U$128: #SDI#1
U$129: #VIN_LED#4
U$130: #SDO#2
U$131: #CS#3
U$132: #SDI#5
U$133: #SDO#6
U$134: SD#SPI8
U$135: NETI9
U$136: #SCL#11
U$137: #SDA#12

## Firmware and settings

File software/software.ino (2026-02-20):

/*
 * Copyright 2022 by Michael Ammann (@mazgch)
 *
 * Licensed under the Apache License, Version 2.0 (the "License");
 * you may not use this file except in compliance with the License.
 * You may obtain a copy of the License at
 *
    http://www.apache.org/licenses/LICENSE-2.0
 *
 * Unless required by applicable law or agreed to in writing, software
 * distributed under the License is distributed on an "AS IS" BASIS,
 * WITHOUT WARRANTIES OR CONDITIONS OF ANY KIND, either express or implied.
 * See the License for the specific language governing permissions and
 * limitations under the License.
 */

//-----------------------------------
// Follow instruction on: https://docs.espressif.com/projects/arduino-esp32/en/latest/installing.html
// Install Arduino -> Preferences -> AdditionalBoard Manager URL, then in Board Manager add esp32 by EspressIf, 
// After that select Board u-blox NINA-W10 series and configure the target CPU: 240MHz, Flash: 80MHz, 4MB, Minimal SPIFFS
// For the SparkFun RTK Everywhere: select the "ESP32 Wrover Module" and the "Huge APP" partition scheme
// Board Manager URL:    https://raw.githubusercontent.com/espressif/arduino-esp32/gh-pages/package_esp32_index.json
// Github Repository:    https://github.com/espressif/arduino-esp32 

// ESP32 libraries, version 3.3.7 is recommended
// - on NINA-W1 versions 2.0.10 until 2.0.17 crash due to https://github.com/espressif/esp-idf/issues/12222 do not use
// - recent v3.1.0 is causing some extra warnings when compiled with All warnings enabled

// Third parties libraries
//-------------------------------------------------------------------------------------

// ArduinoMqttClient by Arduino, version 0.1.8
// Library Manager:    http://librarymanager/All#ArduinoMqttClient   
// Github Repository:  https://github.com/arduino-libraries/ArduinoMqttClient 

// ArduinoWebsockets by Gil Maimon, version 0.5.4
// Library Manager:    http://librarymanager/All#ArduinoWebsockets   
// Github Repository:  https://github.com/gilmaimon/ArduinoWebsockets

// ArduinoJson by Benoit Blanchon, version 7.4.2
// Library Manager:    http://librarymanager/All#ArduinoJson      
// Github Repository:  https://github.com/bblanchon/ArduinoJson

// WiFiManager by Tzapu/Tablatronix, version 2.0.17
// Library Manager:    http://librarymanager/All#tzapu,WiFiManager  
// Github Repository:  https://github.com/tzapu/WiFiManager

// Arduino CAN by sandeepmistry, version 0.3.1
// Library Manager:   http://librarymanager/All#arduino-CAN
// Github Repository: https://github.com/sandeepmistry/arduino-CAN

// NimBLE-Arduino by h2zero, version 2.3.7
// Library Manager:   http://librarymanager/All#NimBLE-Arduino
// Github Repository: https://github.com/h2zero/NimBLE-Arduino

// Sparkfun libraries
//-------------------------------------------------------------------------------------

// SparkFun u-blox GNSS Arduino Library by Sparkfun Electronics, version 2.2.28
// Library Manager:    http://librarymanager/All#SparkFun_u-blox_GNSS_Arduino_Library
// Github Repository:  https://github.com/sparkfun/SparkFun_u-blox_GNSS_Arduino_Library

// SparkFun u-blox SARA-R5 Arduino Library by Sparkfun Electronics, version 1.1.13
// Library Manager:    http://librarymanager/All#SparkFun_u-blox_SARA-R5_Arduino_Library
// Github Repository:  https://github.com/sparkfun/SparkFun_u-blox_SARA-R5_Arduino_Library

// Header files of this project
// to remove LTE, BLUETOOTH, LBAND, CANBUS function simply comment the header below to save memory, 
// the peripherial is however not put into low power mode or its pins remain uncontrolled 
//-------------------------------------------------------------------------------------
#include "LOG.h"          // Comment this if you do not want a separate log level for this application 
#include "HW.h"
#include "CONFIG.h"
#include "UBXFILE.h"
//#include "BLUETOOTH.h"  // Optional, Comment this to save memory if not needed, choose the flash size 4MB and suitable partition
#include "WLAN.h"
#include "GNSS.h"
#include "LBAND.h"        // Optional, comment this if not needed
#include "LTE.h"          // Optional, comment this if not needed,
//#include "CANBUS.h"     // Optional, comment this if not on vehicle using the CAN interface, CAN PHY is reqired 

// ====================================================================================
// MAIN setup / loop
// ====================================================================================

/** Main Arduino setup function, initilizes all functions which spins off various tasks
*/
void setup(void) {
  // initialisation --------------------------------
  // serial port
  Serial.begin(115200);
  while (!Serial);
    /*nothing*/;
  log_i("-------------------------------------------------------------------");
  Config.init();
  String hwName = Config.getDeviceName();
  
  log_i("mazg.ch %s (%s) on board " HW_TARGET_NAME, Config.getDeviceTitle().c_str(), hwName.c_str());
  if (VIN != PIN_INVALID) {
    //              NINA-VCC / ADC-BITS * (R30  + R31)  / R31 * ADC-reading
    log_i("Supply %.2fV", (3.3 / 4095.0   * (22e3 + 33e3) / 33e3) * analogRead(VIN));
  }
  espVersion();
  // SD card 
  UbxSd.init(); // handling SD card and files runs in a task
#ifdef __BLUETOOTH_H__
  Bluetooth.init(hwName);
#endif
  Wlan.init(); // WLAN runs in a tasks, creates an additional LED task 
#ifdef __LTE_H__
  //Lte.enableDebugging(Serial);
  //Lte.enableAtDebugging(Serial); // we use UbxSerial for data logging instead
  //Lte.enableAtDebugging(Websocket); // forward all messages
  Lte.init();  // LTE runs in a task
#endif
  // i2c wire
  UbxWire.begin(I2C_SDA, I2C_SCL); // Start I2C
  UbxWire.setClock(400000); //Increase I2C clock speed to 400kHz
  if (!Gnss.detect()) { 
    log_w("GNSS ZED-F9 not detected, check wiring");
  }
#ifdef __LBAND_H__
  if (!LBand.detect()) {
    log_w("LBAND NEO-D9 not detected, check wiring");
  }
#endif  
#ifdef __CANBUS_H__
  Canbus.init();
#endif
}

/** Main Arduino loop function is used to manage the GPS and LBAND communication 
*/
void loop(void) {
#ifdef __LBAND_H__
  LBand.poll();
#endif
  Gnss.poll();
  delay(50);

  memUsage();
}

// ====================================================================================
// Helpers
// ====================================================================================

#ifndef ESP_ARDUINO_VERSION
  #include <core_version.h>
#endif
#if defined(ARDUINO_UBLOX_NINA_W10) && defined(ESP_ARDUINO_VERSION)
  #if ((ESP_ARDUINO_VERSION > ESP_ARDUINO_VERSION_VAL(2, 0, 9)) && (ESP_ARDUINO_VERSION < ESP_ARDUINO_VERSION_VAL(3, 0, 0)))
    #error "Please downgrade your Arduino-esp32 to version 2.0.9, or switch to 3.0.0 using the Board Manager"
    // for some reason 2.0.10 and at least until 2.0.17 crashes on NINA-W10 after boot with a flash CRC error
    // E (452) spi_flash: Detected size(128k) smaller than the size in the binary image header(2048k). Probe failed.
    // assert failed: do_core_init startup.c:328 (flash_ret == ESP_OK)
    // might be related to https://github.com/espressif/esp-idf/issues/12222
  #endif
#endif

/** Print the version number of the Arduino and ESP core. 
 */
void espVersion(void) {
#ifndef ESP_ARDUINO_VERSION
  log_i("Version IDF %s Arduino_esp32 %s", esp_get_idf_version(), ARDUINO_ESP32_RELEASE);
#else
  log_i("Version IDF %s Arduino_esp32 %d.%d.%d", esp_get_idf_version(),
        ESP_ARDUINO_VERSION_MAJOR,ESP_ARDUINO_VERSION_MINOR,ESP_ARDUINO_VERSION_PATCH);
#endif
}

const int MEM_USAGE_INTERVAL = 10000; //!< Dump interval in ms, set to 0 to disable
  
/** Helper function to diagnose the health of this application dumping the free stacks and heap.
*/
void memUsage(void) {
  int32_t now = millis();      
  static int32_t lastMs = now;    
  // this code allows to print all the stacks of the different tasks
  if (MEM_USAGE_INTERVAL && (0 >= (lastMs - now))) {
    lastMs = now + MEM_USAGE_INTERVAL;
    char buf[128];
    int len = 0;
    const char* tasks[] = { pcTaskGetName(NULL), "Lte", "Wlan", "Bluetooth", "UbxSd", "Led", "Can" };
    for (int i = 0; i < sizeof(tasks)/sizeof(*tasks); i ++) {
      const char *name = tasks[i];
      TaskHandle_t h = 0;
#if (ESP_ARDUINO_VERSION >= ESP_ARDUINO_VERSION_VAL(2, 0, 5))
      h = xTaskGetHandle(name);
#endif
      if (h) {
        UBaseType_t stack = uxTaskGetStackHighWaterMark(h);
        len += sprintf(&buf[len], " %s %d", tasks[i], stack); 
      }
    }
    log_i("Stacks:%s heap: min %d cur %d size %d tasks: %d", buf, 
          ESP.getMinFreeHeap(), ESP.getFreeHeap(), ESP.getHeapSize(), uxTaskGetNumberOfTasks());
  }
}

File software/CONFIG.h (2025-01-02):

/*
 * Copyright 2022 by Michael Ammann (@mazgch)
 *
 * Licensed under the Apache License, Version 2.0 (the "License");
 * you may not use this file except in compliance with the License.
 * You may obtain a copy of the License at
 *
    http://www.apache.org/licenses/LICENSE-2.0
 *
 * Unless required by applicable law or agreed to in writing, software
 * distributed under the License is distributed on an "AS IS" BASIS,
 * WITHOUT WARRANTIES OR CONDITIONS OF ANY KIND, either express or implied.
 * See the License for the specific language governing permissions and
 * limitations under the License.
 */
 
#ifndef __CONFIG_H__
#define __CONFIG_H__

#include <SPIFFS.h>
#include <vector>
#include <mbedtls/base64.h>
#include <ArduinoJson.h>

#include "HW.h"

// -----------------------------------------------------------------------
// MQTT / PointPerfect settings 
// -----------------------------------------------------------------------

/** settings for ZTP request that use HTTPS protocol  
 */
#define    THINGSTREAM_SERVER     "api.thingstream.io"            //!< the thingstream Rest API server domain        
#define    THINGSTREAM_ZTPPATH    "/ztp/pointperfect/credentials" //!< ZTP rest api
const char THINGSTREAM_ZTPURL[]   = "https://" THINGSTREAM_SERVER THINGSTREAM_ZTPPATH; // full ZTP url

/** settings for Amazon root CA request (not really needed, as long as we dont verify the certificates)  
 */
#define    AWSTRUST_SERVER        "www.amazontrust.com"             //!< the AWS trust server domain    
#define    AWSTRUST_ROOTCAPATH    "/repository/AmazonRootCA1.pem"   //!< the AWS root CA path
const char AWSTRUST_ROOTCAURL[]   = "https://" AWSTRUST_SERVER AWSTRUST_ROOTCAPATH; // full AWS root CA url

/** this table defines the recional coverage (by a bounding box and its region tag and frequency
 *  the lower the higher the priority and more targeted the lat/lon region should be
 *  PointPerfect LBAND satellite augmentation service EU / US LBAND frequencies taken from: 
 *  https://developer.thingstream.io/guides/location-services/pointperfect-service-description
 */
struct { const char* region; short lon1; short lon2; short lat1; short lat2; long freq; } POINTPERFECT_REGIONS[] = {
  // Continental
  { "us", -170, -50,   20, 75, 1556290000 }, // Continental US
  { "eu",  -30,  40,   35, 75, 1545260000 }, // Europe
  // Regional / Test 
  { "cn",   75,  135,  15, 60,          0 }, // China
  { "au",  111,  160, -43, -9,          0 }, // Australia
  { "jp",  128,  147,  30, 47,          0 }, // Japan
  { "kr",  126,  130,  34, 39,          0 }, // Korea
  { "sa",   34,   56,  15, 33,          0 }, // Saudi Arabia
  { "br",  -73,  -34, -34,  3,          0 }  // Brazil
};

const unsigned short MQTT_BROKER_PORT     =              8883;  //!< MQTTS port
const int MQTT_MAX_MSG_SIZE               =            9*1024;  //!< the max size of a MQTT pointperfect topic

#define MQTT_TOPIC_MGA                          "/pp/ubx/mga"   //!< GNSS assistance topic 
const char MQTT_TOPIC_KEY_FORMAT[]        =   "/pp/ubx/0236/";  //!< LBAND decryption keys topic
const char MQTT_TOPIC_FREQ[]           = "/pp/frequencies/Lb";  //!< LBAND frequency topic 
const char MQTT_TOPIC_IP_FORMAT[]         =            "/pp/";  //!< correction stream topic prefix, format: /pp/<stream>/<region>/<msg>

const char MQTT_TOPIC_IP_GAD[]            =            "/gad";  //!< geographic area defintion
const char MQTT_TOPIC_IP_HPAC[]           =           "/hpac";  //!< high precision atmospheric corrections
const char MQTT_TOPIC_IP_OCB[]            =            "/ocb";  //!< orbit, clock and bias
const char MQTT_TOPIC_IP_CLK[]            =            "/clk";  //!< clock correction

const char MQTT_STREAM_LBAND[]            =              "Lb";  //!< LBAND stream identifier 
const char MQTT_STREAM_IP[]               =              "ip";  //!< IP stream identifier

const char MQTT_TOPIC_MGA_GPS[]       = MQTT_TOPIC_MGA "/gps";  //!< GPS (US)
const char MQTT_TOPIC_MGA_GLO[]       = MQTT_TOPIC_MGA "/glo";  //!< Glonass (RU)
const char MQTT_TOPIC_MGA_GAL[]       = MQTT_TOPIC_MGA "/gal";  //!< Galileo (EU)
const char MQTT_TOPIC_MGA_BDS[]       = MQTT_TOPIC_MGA "/bds";  //!< Beidou (CN)

// -----------------------------------------------------------------------
// NTRIP settings 
// -----------------------------------------------------------------------
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

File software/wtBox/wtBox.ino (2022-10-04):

/*
 * Copyright 2022 by Michael Ammann (@mazgch)
 *
 * Licensed under the Apache License, Version 2.0 (the "License");
 * you may not use this file except in compliance with the License.
 * You may obtain a copy of the License at
 *
    http://www.apache.org/licenses/LICENSE-2.0
 *
 * Unless required by applicable law or agreed to in writing, software
 * distributed under the License is distributed on an "AS IS" BASIS,
 * WITHOUT WARRANTIES OR CONDITIONS OF ANY KIND, either express or implied.
 * See the License for the specific language governing permissions and
 * limitations under the License.
 */
 
#define SIDES 2
#define PINS 3

const int8_t PINIDS[SIDES][PINS] = { 
#ifdef ARDUINO_ESP8266_WEMOS_D1MINI
/*  Using Board: LOLIN (WEMOS) D1 R2 & mini
 * 
 *                         ---------- ANTENNA --
 *                         |              LED  |
 *                         RST   ESP8266      TX -> CDC @ 115200
 *                         ADC0               RX 
 *     BLUE / HALL_RL_A -> D0/WAKE            D1 <- HALL_RL_C / GREEN 
 *    GREEN / HALL_RR_C -> D5                 D2 <- HALL_RL_B / YELLOW
 *   YELLOW / HALL_RR_B -> D6            BOOT/D3
 *     BLUE / HALL_RR_A -> D7         LED/TX1/D4 -> ESF-MEAS @ 38400 -> ZED RXI
 *                         D8   FLASH        GND
 *                         3v3                5V <- IN
 *                         [BTN                |
 *                          ------- USB --------
 *                               
 */
  { // REAR LEFT (RL) WHEEL pins of hall sensors  
    D0, // HALL_RL_A / BLUE 
    D2, // HALL_RL_B / YELLOW 
    D1  // HALL_RL_C / GREEN
  },  
  {  // REAR RIGHT (RR) WHEEL pins of hall sensors (reverse order)
    D5, // HALL_RR_C / GREEN
    D6, // HALL_RR_B / YELLOW, 
    D7  // HALL_RR_A / BLUE
  },
#else
  #error "add the pins for your target here, and make sure that TX1 is free and availble"
  { // REAR LEFT (RL) WHEEL pins of hall sensors  
    D2, // HALL_RL_A / BLUE 
    D3, // HALL_RL_B / YELLOW 
    D4  // HALL_RL_C / GREEN
  },  
  {  // REAR RIGHT (RR) WHEEL pins of hall sensors (reverse order)
    D5, // HALL_RR_C / GREEN
    D6, // HALL_RR_B / YELLOW, 
    D7  // HALL_RR_A / BLUE
  },
#endif
};

/* convert ticks per period to a speed, 
 * 
 * example for BOSCH Indigo S+ 500
 * - wheel diameter:       ~16.5 cm
 * - wheel circumference:  ~53.0 cm 
 * - ticks per revolution:  1540 ticks
*/
#define ESF_TICKS_PER_METER  ( 1540 /* ticks per revolution */ \
                                * 2 /* left and right wheel */ \
                             / 0.53 /* wheel circumference m */ )
#define ESF_PROVIDER         0x0000 // ESF-MEAS provider id 
#define ESF_PERIOD_MS           100 // ESF-MEAS output rate in ms => 100 = 10Hz

// you should not have to changes what is here below. 
#define ESF_TICKS_TO_MM_PER_S ( 1e3 /* value unit scale to 1e-3m/s = mm */ \
                              * 1e3 /* s/ms */ / ESF_PERIOD_MS /* mesurement perios ms */ \
                              / ESF_TICKS_PER_METER /* ticks / m */ )
#define ESF_TICKtoSPEED(t) (int32_t)(ESF_TICKS_TO_MM_PER_S * t)
#define ESF_DATA_TICKS      0x007FFFFF
#define ESF_DATA_DIRECTION  0x00800000
#define ESF_DATA_TYPE       0xFF000000
#define ESF_DATATYPE_FRONTLEFT       6
#define ESF_DATATYPE_FRONTRIGHT      7
#define ESF_DATATYPE_REARLEFT        8
#define ESF_DATATYPE_REARRIGHT       9
#define ESF_DATATYPE_SINGLETICK      10
#define ESF_DATATYPE_SPEED           11
enum { LEFT = 0, RIGHT = 1, SINGLE = 2, SPEED = 3, ESF_MEAS_NUM } MEAS;

#define STATES 6
#define IGNORE -1
int8_t state[2];
int32_t wt[ESF_MEAS_NUM];
uint32_t esfWt[ESF_MEAS_NUM];
uint32_t esfMs;
uint32_t esfTtag;

size_t esfMeas(uint32_t* p, size_t num) {
  size_t i = 0;
  uint8_t m[6 + 8 + (4 * num) + 2];  
  m[i++] = 0xB5; // µ
  m[i++] = 0x62; // b
  m[i++] = 0x10; // ESF
  m[i++] = 0x02; // MEAS
  uint16_t esfSize = (8 + 4 * num);
  m[i++] = esfSize >> 0; 
  m[i++] = esfSize >> 8;
  m[i++] = esfTtag >> 0;
  m[i++] = esfTtag >> 8;
  m[i++] = esfTtag >> 16;
  m[i++] = esfTtag >> 24;
  uint16_t esfFlags = num << 11;
  m[i++] = esfFlags >> 0;
  m[i++] = esfFlags >> 8;
  m[i++] = ESF_PROVIDER >> 0;
  m[i++] = ESF_PROVIDER >> 8;
  for (int s = 0; s < num; s ++) {
    m[i++] = p[s] >> 0;
    m[i++] = p[s] >> 8;
    m[i++] = p[s] >> 16;
    m[i++] = p[s] >> 24;
  }
  uint8_t cka = 0;
  uint8_t ckb = 0;
  for (int c = 2; c < i; c++) {
    cka += m[c];
    ckb += cka;
  }
  m[i++] = cka;
  m[i++] = ckb;
  return Serial1.write(m, i);
}

void setup() {
  Serial.begin(115200);
  while (!Serial)
    /*nothing*/;
  Serial.print("\n\n"
              "|-- time --|-- rear left wheel tick ---------|-- rear right wheel tick --------|-- single wheel tick -----|-- speed --------------|\n"
              "    esfTtag    wt   esfWt Rev    esfWt Pin St    wt   esfWt Rev    esfWt Pin St    wt   esfWt Rev    esfWt    wt    speed    esfWt\n"); 
  // the default baud rate of u-blox GNSS is 38400 baud
  Serial1.begin(38400);
  // init pins to hall sensor pins
  for (int s = 0; s < SIDES; s ++) {
    for (int i = 0; i < PINS; i ++) {
      pinMode(PINIDS[s][i], INPUT);
    }
    state[s] = IGNORE;
  }
  // prepare the variables 
  esfMs = millis();
  esfTtag = 0;
  for (int s = 0; s < ESF_MEAS_NUM; s ++) {
    wt[s] = 0;
    esfWt[s] = (ESF_DATATYPE_REARLEFT + s) << 24;
  }
}
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

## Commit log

2022-05-22 added device discovery
2022-05-26 finally fixed the details table and the buttons
2022-05-26 fixed button
2022-05-31 rest of files
    [AcrylGlass_Bot.dxf, AcrylGlass_Top.dxf, HPG_Solution.brd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]
2022-06-14 small improvement
    - unswap pins of LTE function board
    - handle and dump arduino_esp version
    - allow sw to run on devices without PL feature
2022-06-14 prepare V1.0 version in case we build a new batch
    - connect shield of SIM card with GND
    - add pull up to LTE_PWR_ON
    - swap LTE_PWN_ON and LTE_RESET to match value in reset.
    [HPG_Solution_v1.0.brd, HPG_Solution_v1.0.sch]
2022-07-04 Update UBXFILE.h
    Disable logfile of AT interface to have enough heap memory for the wifi tasks when SD card is inserted. This is a quick fix, a better solution would be to use global buffer instead of cbuf that allocates memory form heap.
    [UBXFILE.h]
2022-07-07 avoid to include BT
    memory optimization
    [software.ino]
2022-07-09 Improved LTE detection (and reset)
    [LTE.h]
2022-07-15 small fixes
    - pp source lut table
    - correct regexp for parsing
    [CONFIG.h, WEBSOCKET.h]
2022-07-15 improving stability with 2.0.4
    [CONFIG.h, UBXFILE.h, WEBSOCKET.h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]
2022-07-18 issue error if FW is old.
    [LTE.h]
2022-07-23 Various updates
    - support of NEO-D9C / QZSS L6 CLAS receiver and messages (requires updated Sparkfun GNSS Lib)
    - Fixed Micromod target for new V2.0 LTE function boards (working with SARA-R5 / LARA-R6, todo LENA-R8)
    - Better bad/old firmware reporting and hints to upgrade
    - remove region in config if outside bounds, should unsubscribe ip stream outside coverage
    [CONFIG.h, GNSS.h, HW.h]
2022-07-28 various CLAS/LTE improvements
    - change default correction source config
    - improve LTE detection
    - fixed some ubx file writing in i2c
    - CLAS handling
    [LTE.h, UBXFILE.h, WLAN.h]
2022-07-29 prepare for HPS 1.30 release
    - legacy config interface no longer supported.
    - use just SETVAL/GETVAL
    - better checking of GNSS configuration and version
    - fix various comments
    [GNSS.h, software.ino]
2022-07-30 added CAN bus test code
2022-07-30 CANBUS test code added
    - need to uncomment CANBUS.h in software.ino
2022-08-07 can bus improvements, filter ztp response json to limit memory requirements
2022-08-31 add HPG modular board
2022-08-31 fix LED and SD detect
    [HW.h, UBXFILE.h]
2022-09-01 Add hint to fix wifimanager on nora
    - remove Log.poll debug
    [software.ino]
2022-09-03 better fixes for ESP32S3
    [software.ino]
2022-09-27 add error messages if the subscribe requests fail.
    [LTE.h]
2022-09-27 clear some of the serialisation variable in case things get interrupted on connection loss.
2022-09-29 Allow to set a JSON instead of Device Profile Token
2022-10-02 change to default TX1 pin
    - loose status led (shows now TX1)
    [wtBox.ino]
2022-10-02 Picture of the final prototype.
2022-10-02 apply speed calibration
2022-10-02 fix documentation and cleanup
    [GNSS.h, wtBox.ino]
2022-10-07 a simple can emulator
    - runs on a ESP32 and creates CAN message at 10Hz
    - requires external can PHY connected to GPIO4/5
    - pull BUTTON pin low to output a sinwave speed.
2022-10-07 rework the ESF-MEAS injection from CAN bus
    - not using I2C now using Serial2 to ZED-RXI this avoids long unpredictable latencies caused by larger i2C message injection or reads
    - need to wire up a spare GPIO (e.g LTE_DTR or V33_EN) to ZED-RXI
    - Can bus needs to be enabled by uncommenting its header in software.ino and setting the AUTOMOTIVE dynamic model
    [CANBUS.h, GNSS.h, software.ino]
2022-11-08 Add C214_revA pin mappings
2022-11-11 some workarounds for LENA-R8
    This commit relies on changes in the SARA-R5 driver when used with LENA-R8
    [CANBUS.h, CONFIG.h, LTE.h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]
2022-11-24 Fix HTTPs on LENA-R8001
    - Seems that HTTPS port is not automatically set to 443 when security is enabled.
    [LTE.h]
2022-12-08 NTRIP over LTE
    - added NTRIP client over LTE
    - fixed an issue in WIFI NTRIP client that reported too few bytes.
    - reworked the LTE and WIFI state machine so that it switches faster between different correction source configurations
    -
    [CONFIG.h, LTE.h, WLAN.h]
2022-12-09 fix transition between LTE and NTRIP LTE config
    [LTE.h]
2022-12-12 major rework
    - use esp log environment
    - restructure the state machines
    - split big functions
    [BLUETOOTH.h, CANBUS.h, CONFIG.h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]
2022-12-12 more restructure
    - task names
    - fix sdcard stack size
    [BLUETOOTH.h, CANBUS.h, GNSS.h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]
2022-12-12 fix Websocket
    - fixed websocket
    - cleanup bluetooth (reguires bigger flash/partition)
    - TODO/BUG BT connection immediately lost
    [BLUETOOTH.h, CANBUS.h, GNSS.h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]
2022-12-12 BLUETOOTH functional
    - Bluetooth LE based Nordic Uart service
    - allows to connect with SW Maps for visualisation and ntrip data
    - fixed debug mode compile and degraded and fixed several messages to verbose
    - provide heap diagnostics.
    [BLUETOOTH.h, CONFIG.h, GNSS.h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]
2022-12-12 fix notify size / make canbus code still compile
    [BLUETOOTH.h, CANBUS.h]
2022-12-15 major refactoring of code and documentation (and some features) (#11)
    - CODE: reorganised the code by split large functions up by topic to make it better readable and understandable
    - DOCU: briefly documented all functions and their arguments
    - BLUETOOTH now support both NUS and u-blox SPS
    - WEBSOCKET: now outputs also data from LBAND, LTE and WLAN services
    - CONSOLE: You can set the debug level of the application independently from Arduinos debug level.
    - CONSOLE: report heap usage an stack usage of the tasks
    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
2022-12-17 better correction source UI
    [LTE.h, WLAN.h]
2022-12-17 manage LBAND + CLAS receiver mode
    - this prevents LBAND message to be injected while de-configured or outside supported coverage
    - you may still see the MON-PMP
    [CONFIG.h]
2022-12-29 add device reconnect
    - remove debug console message on publish
    - try reconnection on timeout or error
    - dont hide some tiles on error / disconnect
2023-02-11 add ota button
2023-02-19 add error ellipse and tools bar in map view
    - fix rotate button location
    - draw error ellipse
    - allow to disable certain layers
    - open thingstream in separate browser window/tab
    - don't mix projections
    [WLAN.h]
2023-02-19 switch to rgb
2023-02-19 fix button radius
2023-02-19 migration to newer libraries
    - add full screen mode
    - rearrange some map buttons
    - todo: chart.js 4.2.1, ver 4.x does not yet work somehow
2023-02-19 fix scan button
2023-02-20 keep the tools buttons same size
2023-02-21 add arduino adapter (for open mower)
    [ArduinoAdapter.brd, ArduinoAdapter.sch]
2023-05-23 Prepare for official u-blox release XPLR-HPG1/2
    - renamed official u-blox targets
    - minor tweaks
    - update readme and reference to official boards.
2023-06-29 update versions to latest
    - added overlay icon
    - fixed monitor string parsing when no source
    - as used for customer N investigations
    [WEBSOCKET.h, software.ino]
2024-02-07 Fix bug in mqttCallback UNSUBSCRIBE (#17)
    [LTE.h]
2024-04-20 Test with latest version, add support for secure NTRIP, VIN monitor
    - Adding VIN voltage reading at start
    - Support Secure NTRIP connections on WIFI such as on PointPerfect 2102 port.
    - Draft Secure NTRIP connections on WIFI such as on PointPerfect 2102 port, requires new API in sparkfun SARA-R5 lib
    - tested with latest libraries, somehow however ESP32 2.0.10 and later crashes immediately after boot with a CRC error
    [LTE.h, WLAN.h, software.ino]
2024-04-20 better warning
    improve the warning for issue https://github.com/espressif/esp-idf/issues/12222
    [software.ino]
2024-04-20 Adding template code to enable secure PP over NTRIP
    currently disabled and requires latest changes to sparkfun library.
2024-04-20 type and migrate to ArduinoJson 7.x
    - typo in config page
    - migrate to ArduinoJson 7.x (do not use depricated functions)
2024-04-21 backup override to have a option to set TLS on socket
    to be removed when PR https://github.com/sparkfun/SparkFun_u-blox_SARA-R5_Arduino_Library/pull/43/ is merged and released
2024-04-21 Auto detect secure and non secure sockets for NTRIP
    - also wipe pointer after deleting
2024-04-21 Try to resolve query mountpoints using ntrip 2.0
    [WLAN.h]
2024-04-27 NTRIP improvements
    - make NTRIP client work with pointperfect/onocoy/rtk2go
    - reconnect also LTE after config changes
    - support secure and non secure NTRIP connections
    - using HTTP client for NTRIP over WIFI
    - compile time switches for NTRIP 1.0/2.0, and HTTP 1.0 / 1.1
2024-04-27 adding brazil, const no longer needed
    [CONFIG.h]
2024-04-28 improved config page
    - rework the config page to save memory
    - add ntrip version selection
    [CONFIG.h, LTE.h, WLAN.h]
2024-04-30 NTRIP + RTCM improvements
    - tabs vs spaces
    - add gga to http header
    - make compatibe with onocoy nrby_ mountpoints
    - fix step in bitfield decoding
    [CONFIG.h, GNSS.h, LTE.h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]
2024-05-01 make the green PCB version default,
2024-05-02 name the board, better debug output
2024-05-29 fixing a debug message typo (#23)
    [LTE.h]
2024-05-29 prepare for esp32_arduinov3.0.0
    - BOOT pin pull up must be set
    - Ringbuffer can't be size 0
    - you may need to patch ArduinoWebsockets https://github.com/gilmaimon/ArduinoWebsockets/issues/156
    - avoid some -wFormat= warnings (better disable completely as wifimanager, SARA-R5 and other libs are affected)
    [UBXFILE.h, WLAN.h, software.ino]
2024-06-01 fixing ntrip LTE client / more v3 changes
    - fix ntrip client: there was a additional cr / lr needed in the get request, also add accept header just in case.
    - more v3.0.0 fixes: avoid esp warning message when setting gpio level before switching the IO to output
    [HW.h, LTE.h, software.ino]
2024-06-03 better comments for working around issues with v3.0.0
    [HW.h, software.ino]
2025-01-02 port to new library and compiler versions
    - remove various warnings
    - avoid use of deprecated functions
    - improve sara r5 error message in case of socket failure
    [BLUETOOTH.h, CONFIG.h, LTE.h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]
2025-01-12 esp v 1.3.1, fixed some warnings
    add using statements for virtual overrides
    [BLUETOOTH.h, software.ino]
2025-08-25 add support for currents
2025-08-31 add fft, select param by table
    - filter tracks in table
    - improve hover in map.
    - select chart field by table
2025-09-06 improve UI with chart buttons
2025-09-22 improve the track handling
2025-11-10 fix chart button state at restore
2026-01-10 limit track names
2026-01-18 bump version of libs and board
    - nimble now requires to add name
2026-01-18 draft a supply message
    extract VCC power
2026-02-20 fix ble, not timeout with ble/usb
    [BLUETOOTH.h, software.ino]
2026-03-15 zoom fit button.
    uppon special request from cvoi
2026-05-07 filter Selective L5

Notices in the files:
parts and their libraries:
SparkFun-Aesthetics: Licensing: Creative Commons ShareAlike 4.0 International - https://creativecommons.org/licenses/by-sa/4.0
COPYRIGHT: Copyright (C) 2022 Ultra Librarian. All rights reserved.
